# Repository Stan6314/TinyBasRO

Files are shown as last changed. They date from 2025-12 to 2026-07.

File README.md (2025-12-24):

Microcomputer TinyBasRO
======================

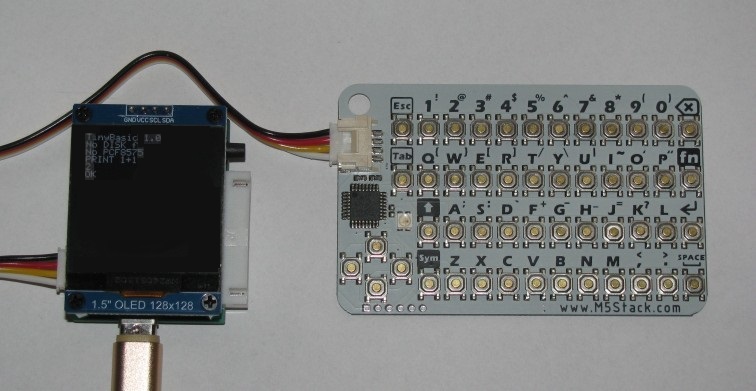
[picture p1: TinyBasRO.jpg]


The TinyBasRO microcomputer is a very simple device that even an electrical engineering beginner should be able to assemble and put into operation. It resembles simple 8-bit computers from the 1980s. After assembly, it can be programmed very easily using the Tiny BASIC language, which should be manageable even for those who have never programmed before. The basis is a small 32-bit RISC-V processor cooperating with serial I2C memory, where the user-created program is stored.

A microcomputer is suitable for the first introduction to computing technology when teaching hardware and software. It can be used not only for educational purposes, but can also be used as a control element for simple electronic devices.

Technical data for TinyBasRO
----------------------------

*   TinyBasHW_KiCad - HW documents (schematic and printed circuit board) in KiCad 9.0 format
*   src - Source files for TinyBasRO for CH32V003 created in ch32fun development environment
*   Bin - Compiled binary content in HEX format for direct loading into CH32V003 memory
*   Manuals - Manuals for HW, Tiny BASIC programming language and its examples and advice for beginners
*   EEPROM_examples - Contents of serial EEPROM memory in HEX format with examples of 8 ready-made Tiny BASIC sample programs for loading into microcomputer memory

Requirements for building and operating a TinyBasRO
---------------------------------------------------

*   Printed circuit board
*   Electrical components according to the list in the TinyBasRO_HW manual
*   WCHLinkE programmer for programming CH32V003
*   OLED display 128x128 with SH1107 driver
*   Keyboard CardKB from M5STACK
*   5V power supply

Using a microcomputer
---------------------

The assembled microcomputer only requires a 5 V power supply, OLED display 128x128 with SH1107 driver and CardKB keyboard. The board has several interfaces for connecting expansion modules via the I2C bus or controlled elements via the input/output connector. In addition, the TinyBasRO allows you to easily light up a string of up to 100 WS2812 LEDs compared to computer TinyBasRV.

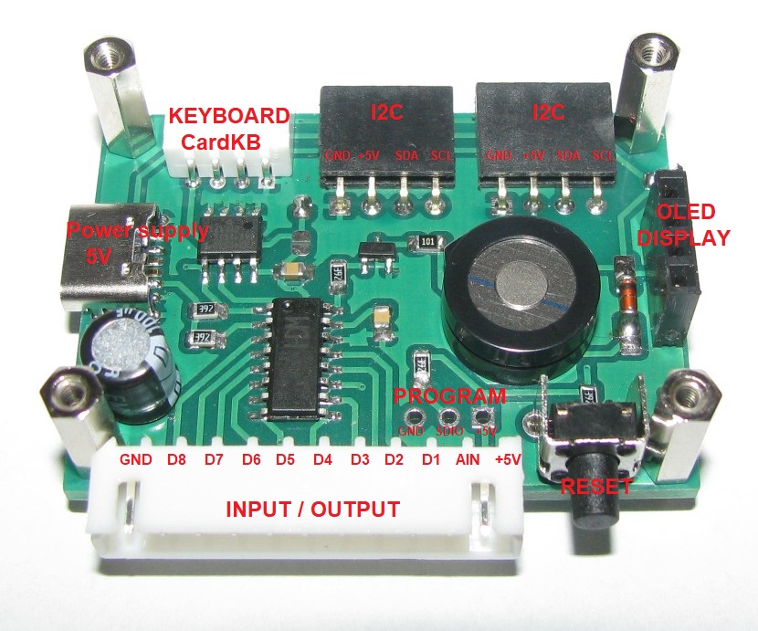
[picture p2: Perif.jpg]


After debugging the program, the TinyBasRO microcomputer can work independently without a monitor and keyboard and control, for example, some LED lighting effects.

* * *

Mikropočítač TinyBasRO
======================



Mikropočítač TinyBasRO je velmi jednoduché zařízení, které by měl dokázat sestavit a uvést do provozu i elektrotechnický začátečník. Podobá se jednoduchým 8bitovým počítačům z 80tých let. Po sestavení jej lze velmi jednoduše programovat pomocí jazyka Tiny BASIC, který by měl zvládnout i ten, kdo dříve neprogramoval. Základem je malý 32bitový RISC-V procesor spolupracující se sériovou I2C pamětí, kam se ukládá uživatelem tvořený program.

Mikropočítač je vhodný pro první seznámení s výpočetní technikou při výuce technického i programového vybavení. Může být použit nejen pro výukové účely, ale lze jej nasadit jako řídicí prvek pro jednoduché elektronické přístroje.

Technické podklady pro TinyBasRO
--------------------------------

*   TinyBasHW_KiCad - HW podklady (schéma a plošný spoj) ve formátu programu KiCad 9.0
*   src - Zdrojové soubory k TinyBasRO pro CH32V003 vytvořené v prostředí ch32fun
*   Bin - Přeložený binární obsah ve formátu HEX pro přímé nahrání do paměti CH32V003
*   Manuals - Manuály pro HW, programovací jazyk Tiny BASIC a jeho příklady a rady pro začátečníky
*   EEPROM_examples - Obsah sériové EEPROM paměti ve formátu HEX s příklady 8 hotových ukázkových programů Tiny BASIC pro nahrání do paměti mikropočítače

Požadavky pro stavbu a provoz TinyBasRO
---------------------------------------

*   Deska plošného spoje
*   Elektrotechnické součástky podle seznamu v manuálu TinyBasRO_HW
*   Programátor WCHLinkE pro naprogramování CH32V003
*   OLED displej 128x128 s řadičem SH1107
*   Klávesnice CardKB od M5STACK
*   Napájecí zdroj 5 V

Použití mikropočítače
---------------------

Sestavený mikropočítač vyžaduje pouze napájecí zdroj 5 V, OLED displej 128x128 s řadičem SH1107 a klávesnici CardKB. Na desce je několik rozhraní pro připojení rozšiřujících modulů přes I2C sběrnici nebo ovládaných členů přes konektor vstupů/výstupů. Navíc proti počítači TinyBasRV umožňuje snadno rozsvěcovat řetězec až se 100 LED WS2812. 



Po odladění programu, může mikropočítač TinyBasRO pracovat samostatně bez monitoru a klávesnice a řídit např. nějaké světelné LED efekty.

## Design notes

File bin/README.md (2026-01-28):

Memory content for the TinyBasRO microcomputer
==============================================

Here you will find two compiled versions of the program for the TinyBasRO microcomputer, which can be loaded directly into the microcontroller memory using the WCHLinkE programmer.

The file TinyBasRO.hex can be loaded into the CH32V003 memory with the standard display orientation (the display connector with the I2C bus is on top). If you would like to rotate the orientation of the microcomputer display (the display will be readable with the I2C bus connector on the bottom), use the file TinyBasRO_upsidedown.hex.

Notice!
=======

Be careful when reading and downloading HEX files from GitHub. When downloading a file, the end of the line is truncated to a single LF character (Linux-style). However, WCH-LinkUtility requires Windows-style line termination - CR+LF! When loading a file into its buffer, WCH-LinkUtility will only load one line of HEX file!

WCH-LinkUtility then acts as if it programmed the entire memory, but only 16 bytes are written. That is why the HEX files are now saved in .zip format.

* * *

Obsah paměti pro mikropočítač TinyBasRO
=======================================

Zde naleznete přeložené dvě verze programu pro mikropočítač TinyBasRO, které je možné nahrát přimo do paměti mikrořadiče pomocí programátoru WCHLinkE.

Soubor TinyBasRO.hex je možné nahrát do paměti CH32V003 při standardní orientaci displeje (konektor displeje s I2C sběrnicí je nahoře). Pokud byste chtěli orientaci displeje mikropočítače otočit (displej bude čitelný při konektoru I2C sběrnice dole) použijte soubor TinyBasRO_upsidedown.hex.

Upozornění!
===========

Dejte si pozor na čtení a stahování HEX souborů z GitHub. Při stažení souboru je konec řádku zkrácen na jeden znak LF (jako v Linuxu). WCH-LinkUtility ale vyžaduje ukončení řádku ve stylu Windows - CR+LF! Při načítání souboru do svého bufferu pak WCH-LinkUtility načte pouze jeden řádek HEX souboru!

WCH-LinkUtility pak fungují jakoby naprogramovaly celou paměť, ale zapíše se pouze 16 bajtů. Proto jsou HEX soubory nyní uloženy v .zip formátu.

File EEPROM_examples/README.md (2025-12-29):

Examples for TinyBasRO microcomputer
====================================

The file contains 8 examples in the Tiny BASIC language for the TinyBasRO computer. If you load them into the computer's serial EEPROM memory (you can choose "disk h" or "disk f") you will get 8 examples for working with the microcomputer.

The examples correspond to the examples described in the TinyBasExamples manual for the TinyBasRV microcomputer. Since the TinyBasRO computer has a smaller display (only 16 x 21 characters), the programs are modified to fit on the screen.

In the last example for controlling the traffic light, a total of 3 separate LEDs are used. Red on D2, yellow on D3 and green on D4 via 470 Ohm resistors. In addition, it is possible to connect a chain of 3 multi-colored WS2812 LEDs to D1. 

* * *

Příklady pro mikropočítač TinyBasRO
===================================

Soubor obsahuje 8 příkladů v jazyku Tiny BASIC pro počítač TinyBasRO. Pokud je nahrajete do sériové paměti EEPROM počítače (můžete si zvolit "disk h" nebo "disk f") získáte 8 ukázek pro práci s mikropočítačem.

Příklady odpovídají ukázkám popsaným v manuálu TinyBasExamples u mikropočítače TinyBasRV. Protože počítač TinyBasRO má menší displej (pouze 16 x 21 znaků), jsou programy modifikovány tak, aby se vešly na obrazovku.

U posledního příkladu pro ovládání semaforu jsou použity celkem 3 samostatné LED. Červená na D2, žlutá na D3 a zelená na D4 přes rezistory 470 Ohm. Navíc je možné připojit na D1 řetězec 3 vícebarevných LED typu WS2812.

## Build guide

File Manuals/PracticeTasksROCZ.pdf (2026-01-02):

## Cvičné úlohy pro jazyk Tiny BASIC (RO ver 1)

Příklad 1:

Zadání:
Vytvořte program pro výpočet plochy obdélníka. Po spuštění programu bude uživatel vyzván, ať zadá délky stran. Pak se vypíše velikost plochy. Vše počítejte s celočíselnými hodnotami.

Rada:
Použijte příkazy PRINT a INPUT. Plocha obdélníka se vypočítá jako součin délek jeho stran.

Příklad řešení:
0 REM Vypocet plochy obdelnika 1 PRINT “Zadej delku stran:\n“ 2 INPUT A; INPUT B
3 PRINT “Plocha je: “ , A*B

Poznámky k řešení:
Příklad by se dal napsat i na jeden řádek:
1 INPUT A; INPUT B; PRINT “Plocha je: “ , A*B

Rev. A

Příklad 2:

Zadání:
Vytvořte program pro výpočet plochy kruhu s přesností na 2 desetinná místa. Po spuštění programu bude uživatel vyzván, ať zadá poloměr kruhu a pak se vypíše velikost plochy.

Rada:
Použijte příkazy PRINT, LET, IF-THEN a INPUT. Tiny BASIC počítá pouze s celými čísly. Použijte pro výpočet plochy hodnotu π jako 314 a pak zobrazte výsledek postupně. Nejprve vypište celou hodnotu získanou dělením 100, znak pro desetinnou čárku a pak zbytek po dělení 100. Nezapomeňte, že zbytek po dělení je nutné zobrazit i s první nulou – např. 08.
Vzorec pro výpočet plochy je známý:

Příklad řešení:
0 REM Vypocet plochy kruhu
1 PRINT “Zadej polomer:\n“
2 INPUT R
3 LET S=R*R*314; LET C=S/100 4 PRINT “Plocha je: “ , C, “.“
5 LET Z=S-C*100
6 IF Z<10 THEN PRINT “0“
7 PRINT Z

Poznámky k řešení:
Tiny BASIC nemá operaci pro mocniny čísel. Proto je druhá mocnina zapsána jako R*R (řádek 3). A také nepracuje s desetinnými čísly. Násobením 314 místo 3,14 získáme výsledek 100krát větší. Abychom dostali celou část výsledku musíme S dělit 100 (řádek 3). Zbytek, který vypočítáme po odečtení celočíselné části násobené 100, pak musíme zobrazit i s případnou první nulou (řádek 6).

Příklad 3:

Zadání:
Vytvořte program, který pod sebe vypíše všechna lichá čísla do 20.

Rada:
Použijte příkazy PRINT, LET, GOTO a IF-THEN

Příklad řešení:
0 REM Licha cisla do 20
1 LET A=1
2 PRINT A, “\n“
3 LET A=A+2
4 IF A<20 THEN GOTO 2

Poznámky k řešení:
Jde o velmi jednoduchý počítaný cyklus. Začínáme od 1 (řádek 1) a postupně čísla vypisujeme na samostatné řádky (řádek 2) se zvětšováním po 2 (řádek 3). Vyhodnocovací podmínka (řádek 4) vrací program na výpis čísla, dokud není dosažena 20.

Příklad 4:

Zadání:
Vytvořte program, který vykresli na obrazovce pravoúhlý trojúhelník ze znaků * vysoký 10 řádků.

Rada:
Použijte příkazy PUTCH, LET, GOTO a IF-THEN. Znak pro nový řádek má hodnotu 10 a znak * má hodnotu 42.

Příklad řešení:
0 REM Trojuhelnik z *
1 PUTCH 10
2 LET A=1; REM Pocita radky
3 LET B=1; REM Hvezdy na radku 4 PUTCH 42; LET B=B+1
5 IF B<=A THEN GOTO 4
6 PUTCH 10; LET A=A+1
7 IF A<11 THEN GOTO 3

Poznámky k řešení:
Jsou zde použity 2 počítané cykly vnořené do sebe. V proměnné A se počítají řádky (řádky 2,6,7) a v proměnné B se počítají znaky vypisované na řádku (řádky 3,4,5).

Příklad 5:

Zadání:
Vytvořte program, který vykresli na obrazovce čtverec o délce strany 10 znaků.

Rada:
Použijte příkazy PUTCH, PRINT, LET, GOTO a IF-THEN. Abyste si ušetřili práci, použijte pro vykreslení vodorovné čáry podprogram s příkazy GOSUB a RETURN. Nezapomeňte program ve správném bodě ukončit příkazem END.
Znak pro vymazání displeje má hodnotu 12, nový řádek 10, levý horní roh 144, pravý horní roh 145, levý dolní roh 146, pravý dolní roh 147, svislá čára 156 a vodorovná čára 157.

Příklad řešení:
0 REM Ctverec
1 PUTCH 12
2 LET A=1; REM Pocita radky 3 PUTCH 144; GOSUB 10
4 PUTCH 145; PUTCH 10
5 PUTCH 156; PRINT “ “
6 PUTCH 156; PUTCH 10; LET A=A+1 7 IF A<8 THEN GOTO 5
8 PUTCH 146; GOSUB 10
9 PUTCH 147; PUTCH 10; END
10 REM Vodorovna cara
11 LET I=1
12 PUTCH 157; LET I=I+1
13 IF I<9 THEN GOTO 12
14 RETURN

Poznámky k řešení:
Řádky 3 a 4 vykreslí horní stranu čtverce, řádky 8 a 9 spodek čtverce. Využívá se podprogram na řádcích 10 až 14, který dělá vodorovnou čáru. Řádky 5, 6 a 7 vykreslí svislé čáry. Počet mezer v příkazu PRINT na řádku 5 musí být 8, aby se vyprázdnilo tělo čtverce.

Příklad 6:

Zadání:
Vytvořte program, který umožní posunovat znak X po obrazovce. Začíná se uprostřed obrazovky a stisknutí klávesy 2 znak X posune dolů, 4 vlevo, 6 vpravo a 8 nahoru.

Rada:
Použijte příkaz PUTCH s využitím jeho parametrů, CURSOR, INKEY, GOTO a IF-THEN.
Znak pro vymazání displeje má hodnotu 12, znak X je 88, prázdný znak je 32, 2 je 50, 4 je 52, 6 je 54 a 8 je 56.

Příklad řešení:
0 REM Posun X
1 PUTCH 12
2 CURSOR 157; PUTCH .88
3 INKEY K
4 IF K=50 THEN PUTCH v32; PUTCH .88 5 IF K=52 THEN PUTCH <32; PUTCH .88 6 IF K=54 THEN PUTCH >32; PUTCH .88 7 IF K=56 THEN PUTCH ^32; PUTCH .88
8 GOTO 3

Poznámky k řešení:
Program nejprve vyčistí obrazovku a umístí doprostřed displeje (pozice 400) znak X pomocí příkazu PUTCH. Symbol tečky zajistí, že kurzor zůstane na dané pozici. Když uživatel stiskne správnou klávesu, nejprve se vymaže stará pozice prázdným znakem a posune se kurzor na novou pozici (směr určuje symbol před hodnotou 32). Na nové pozici se pak vypíše X a ponechá kurzor.

Příklad 7:

Zadání:
Vytvořte program, který bude automaticky „hrát ping-pong“. Míček v podobě písmene o bude poletovat na řádku z levé strany na pravou stranu a naopak. Na kraji displeje se vždy odrazí a vrátí zpět.

Rada:
Použijte příkaz PUTCH s využitím parametrů, CURSOR, DELAY, GOTO a IF-THEN.
Znak pro vymazání displeje má hodnotu 12, znak o je 111, prázdný znak je 32.
Pozice uprostřed prostředního řádku má hodnotu 157, znak na levém okraji 147, vpravo 167.

Příklad řešení:
0 REM Ping-pong
1 PUTCH 12; LET C=157
2 CURSOR C; PUTCH .111
3 LET D=1
4 DELAY 100; PUTCH .32
5 LET C=C+D; CURSOR C; PUTCH .111 6 IF C=167 THEN LET D=-1
7 IF C=147 THEN LET D=1
8 GOTO 4

Poznámky k řešení:
Nejprve se program nastaví do výchozí pozice a směr pohybu míčku v proměnné D se určí na hodnotu 1 – tj. míček poletí vpravo(řádky 1 až 3). Ve smyčce, která začíná na řádku 4, se chvíli počká, smaže starý obraz míčku a pak se posune míček podle hodnoty v D na novou pozici. Řádky 6 a 7 hlídají dosažení kraje obrazovky a mění směr letu tam (D=1), nebo zpět (D=-1).

Příklad 8:

Zadání:
Napište program, který zahraje melodii podle not na obrázku. Na začátku uživatel zadá dobu trvání 1/8 noty v rozmezí 200 až 400 milisekund.

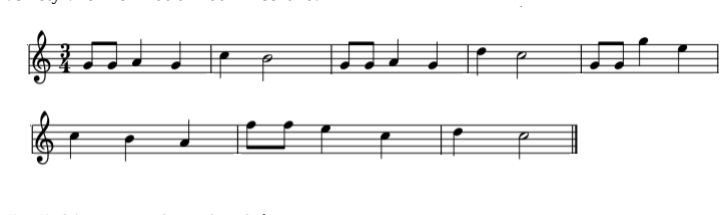
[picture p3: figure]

Přibližné frekvence základních tónů:
c‘: 262 | d‘: 294 | e‘: 330 | f‘: 349 | g‘: 392 | a‘: 440 | h‘: 494
c“: 523 | d“: 587 | e“: 659 | f“: 698 | g“: 784 | a“: 880 | h“: 989

Rada:
Použijte příkaz BEEP s využitím parametrů, INPUT, GOTO a IF-THEN. Pokud se v melodii objevují stejné pasáže, můžete použít podprogram GOSUB a RETURN, abyste nemuseli opisovat stejné části. Nezapomeňte program ukončit příkazem END.

Příklad řešení:
0 REM Melodie
1 PRINT “Zadej tempo:\n“
2 INPUT T
3 IF T<200 THEN GOTO 1
4 IF T>400 THEN GOTO 1
5 GOSUB 15
6 BEEP 523,2*T; BEEP 494,4*T; GOSUB 15 7 BEEP 587,2*T; BEEP 523,4*T; BEEP 392,T 8 BEEP 392,T; BEEP 784,2*T; BEEP 659,2*T
9 BEEP 523,2*T; BEEP 494,2*T; BEEP 440,2*T 10 BEEP 698,T; BEEP 698,T; BEEP 659,2*T
11 BEEP 523,2*T; BEEP 587,2*T; BEEP 523,4*T 12 END
15 BEEP 392,T; BEEP 392,T; BEEP 440,2*T
16 BEEP 392,2*T; RETURN

Poznámky k řešení:
Uživatel je nejprve vyzván k zadání tempa a je zkontrolováno povolené rozmezí hodnot (řádky 1 až 4). Protože se první čtyři tóny opakují ve třetím taktu, je použit podprogram na řádcích 15 a 16. Jednotlivé tóny jsou zadány frekvencí a dobou trvání. Čtvrťová nota je dvojnásobná a půlová čtyřnásobná proti zadané době osminové noty.

Příklad 9:

Zadání:
Napište program pro vytvoření velmi jednoduchého klavíru. Po stisknutí klávesy 1 až 9 zahraje po dobu 200 až 600 milisekund (čas se zadá po startu) tón c‘ až d“.
Přibližné frekvence základních tónů:
c‘: 262 | d‘: 294 | e‘: 330 | f‘: 349 | g‘: 392 | a‘: 440 | h‘: 494
c“: 523 | d“: 587

Rada:
Použijte příkaz BEEP s využitím parametrů, INPUT, INKEY, GOTO a IF-THEN. Zkuste využít toho, že klávesy 1 až 9 vrací v příkazu INKEY hodnoty 49 až 57. Pak můžete vypočítat potřebný skok v příkazu GOTO.

Příklad řešení:
0 REM Piano
1 PRINT “Zadej dobu tonu:\n“ 2 INPUT T
3 IF T<200 THEN GOTO 1
4 IF T>600 THEN GOTO 1
5 INKEY K
6 IF K<49 THEN GOTO 5
7 IF K>57 THEN GOTO 5
8 GOTO K-40
9 BEEP 262,T; GOTO 5
10 BEEP 294,T; GOTO 5
11 BEEP 330,T; GOTO 5
12 BEEP 349,T; GOTO 5
13 BEEP 392,T; GOTO 5
14 BEEP 440,T; GOTO 5
15 BEEP 494,T; GOTO 5
16 BEEP 523,T; GOTO 5
17 BEEP 587,T; GOTO 5

Poznámky k řešení:
Uživatel je nejprve vyzván k zadání doby tónu a je zkontrolováno povolené rozmezí hodnot (řádky 1 až 4). Ve smyčce, která začíná na řádku 5 se nejprve zkontroluje, zda klávesa patří mezi povolené a pak se vypočítá na řádku 8 skok na řádek s odpovídajícím tónem. Hodnota první povolené číslice 49 musí zamířit na řádek 9, proto se odečítá hodnota 40.

Příklad 10:

Zadání:
Vytvořte program, který bude představovat losovací zařízení pro čísla 1 až 49. Vždy po stisknutí libovolné klávesy zobrazí náhodné číslo z uvedeného rozsahu.

Rada:
Použijte příkazy TIME, INKEY, PRINT, GOTO a IF-THEN.
Po stisknutí klávesy vezměte aktuální čas. Jeho zbytek po dělení 49 bude dostatečně náhodné číslo. Nezapomeňte, že zbytek po dělení 49 je v rozsahu 0 až 48. Získanou hodnotu je potřeba zvýšit o 1.

Příklad řešení:
0 REM Nahodne cislo
1 INKEY K
2 IF K=0 THEN GOTO 1
3 TIME T; LET A=T/49
4 PRINT T-A*49+1, “\n“
5 GOTO 1

Poznámky k řešení:
Na řádcích 1 a 2 se čeká na stisknutí libovolné klávesy. V okamžiku, kdy uživatel stiskne klávesu se naplní proměnná T příkazem TIME. Hodnota získaná příkazem TIME se mění přibližně 32000krát za sekundu. Protože potřebujeme náhodná čísla do 49, vypočítáme zbytek po dělení 49. Výsledek zvětšený o 1 zobrazíme.

Příklad 11:

Zadání:
Vytvořte program ukazující čas uplynulý od spuštění počítače ve formě HH:MM:SS.

Rada:
Použijte příkazy TIME, PRINT, PUTCH, CURSOR, GOTO a IF-THEN.
Pokud hodnotu získanou příkazem TIME podělíte 31914, získáte čas od spuštění počítače v sekundách. Získaný čas pak stačí dělit 3600, abyste dostali počet uplynulých hodin. Ze zbytku pak dělením 60 získáte minuty. Nezapomeňte, že v zadání je zobrazení čísla na 2 místa. Nestačí vypsat jenom např. 5, je třeba zobrazit jako 05. Na to se může hodit podprogram s GOSUB a RETURN. Znak : má hodnotu 58, znak 0 má hodnotu 48.

Příklad řešení:
0 REM Hodiny
1 PUTCH 12
2 DELAY 300
3 TIME T; LET S=T/31914
4 LET A=S/3600; LET S=S-A*3600 5 CURSOR 0; GOSUB 10
6 LET A=S/60; LET S=S-A*60
7 PUTCH 58; GOSUB 10
8 LET A=S; PUTCH 58; GOSUB 10 9 GOTO 2
10 REM Vypis z A na 2 mista
11 IF A<10 THEN PUTCH 48
12 PRINT A; RETURN

Poznámky k řešení:
Čas získaný příkazem TIME podělíme hodnotou 31914, abychom získali celkový čas v sekundách. Hodiny do proměnné A získáme dělením 3600. Ve zbytku po celočíselném dělení zůstanou minuty a sekundy. Celočíselným dělením 60 dostaneme minuty a zbytek z výpočtu minut jsou sekundy. Vše musíme zobrazovat na 2 místa, takže doplňujeme případnou první nulu u jednociferných čísel při zobrazování hodnoty z A v podprogramu (řádek 11).

Příklad 12:

Zadání:
Vytvořte pomocí počítače „kuchyňskou minutku“. Po startu programu uživatel zadá čas od 1 do 99 minut. Po zadání začne na displeji odpočítávání po minutách a po dosažení 0 se ozve 10 sekund signál.

Rada:
Použijte příkaz TIME, BEEP, INPUT, PRINT, GOTO a IF-THEN. Po zadání požadovaného času si můžete vypočítat čas, při kterém časování skončí. Cílový čas získáte přičtením počtu minut násobených 60*31914 (sekundy v minutě krát počet tiků za sekundu = 1914840) k aktuálnímu času.

Příklad řešení:
0 REM Minutka
1 PRINT “Zadej cas [min]:\n“ 2 INPUT T
3 IF T<1 THEN GOTO 1
4 IF T>99 THEN GOTO 1
5 TIME C; LET C=C+T*60*31914 6 PUTCH 12
7 DELAY 300
8 TIME T; LET D=C-T
9 IF D<0 THEN BEEP 800,10000; END 10 CURSOR 0; PRINT D/1914840, “ “
11 GOTO 7

Poznámky k řešení:
Uživatel je nejprve vyzván k zadání doby a je zkontrolováno povolené rozmezí hodnot (řádky 1 až 4). Po správném zadání je do proměnné C uložen cílový čas, který vypočítáme jako aktuální čas s dobou zadanou uživatelem vynásobenou 31914 (počet tiků za sekundu) a 60 (počet sekund v minutě). Ve smyčce, která začíná na řádku 7, chvíli čekáme, protože není nutno zobrazovat hodnoty tak rychle, že by to uživatel stejně nepostřehl. Na řádku 8 zjistíme rozdíl mezi cílovým a aktuálním časem. Při záporném výsledku časování ukončíme. Jinak rozdíl zobrazíme. Konstanta 1914840 vznikne vynásobením 60*31914.

Příklad 13:

Zadání:
Naprogramujte hru „Lepší postřeh“ pro dva a více hráčů. Po stisknutí klávesy čeká 5 sekund, přičemž start časování je zahájen *. Pak zobrazí na displeji cílový znak. Klávesa, která byla zmáčknutá jako první po zobrazení cílového znaku, bude označena jako vítěz.

Rada:
Použijte příkazy INKEY, DELAY, PUTCH, PRINT, GOTO a IF-THEN. Při tvorbě programu nezapomeňte na to, že musíte zkontrolovat, zda hráč nezmáčknul klávesu před zobrazením cílového znaku.
Znak * má hodnotu 42, cílový znak má hodnotu 143.

Příklad řešení:
0 REM Lepsi postreh
1 PRINT “\nStart hry\n“
2 INKEY K
3 IF K=0 THEN GOTO 2
4 PUTCH 42; DELAY 5000; INKEY K 5 PUTCH 143; IF K>0 THEN GOTO 10
6 INKEY K
7 IF K=0 THEN GOTO 6
8 PRINT “\nVitez: “; PUTCH K; DELAY 2000 9 GOTO 1
10 PRINT “\nProhral: “; PUTCH K; DELAY 2000
11 GOTO 1

Poznámky k řešení:
Na řádcích 1 až 3 počkáme na start hry. Pak zobrazíme *, čekáme 5 sekund a sejmeme, zda někdo nestiskl klávesu předčasně (řádek 4). Na řádku 5 zobrazíme cílový znak a zkontrolujeme předčasné stisknutí klávesy. Je-li vše v pořádku, na řádcích 6 a 7 čekáme na stisknutí klávesy a na řádku 8 vyhlásíme vítěze.

Příklad 14:

Zadání:
Vytvořte program pro akustický generátor. Uživatel zadá frekvenci požadovaného tónu v rozsahu 100 až 4000 Hz a dokud nebude program ukončen, počítač píská zadaným tónem.

Rada:
Použijte příkazy BEEP, INPUT, PRINT, GOTO a IF-THEN.
Aby bylo možné program zastavit zadáním příkazu END, použijte v časovém parametru u příkazu BEEP nějakou přijatelnou hodnotu v rozsahu jednotek sekund.

Příklad řešení:
0 REM Zvukovy generator
1 PRINT “Zadej frekv. 100-4000\n“ 2 INPUT F
3 IF F<100 THEN GOTO 1
4 IF F>4000 THEN GOTO 1
5 BEEP F,5000
6 GOTO 5

Poznámky k řešení:
Uživatele nejprve vyzveme k zadání frekvence a je zkontrolováno povolené rozmezí hodnot (řádky 1 až 4). Pak je ve smyčce na řádcích 5 a 6 trvale pouštěn tón o zadané frekvenci.

Příklad 15:

Zadání:
Napište program, ve kterém uživatel zadá nějaké jméno ukončené klávesou Enter. Počítač pak vypíše, že jméno je jeho přítel. Maximální délka jména může být 30 znaků.

Rada:
Použijte příkazy INKEY, PRINT, PUTCH, GOTO a IF-THEN. Zadávané jméno je výhodné ukládat do proměnných v poli @. Počítejte si přitom počet uložených písmen.

Příklad řešení:
0 REM Pritel pocitace
1 LET I=0; PRINT “\nZadej jmeno:\n“ 2 INKEY K
3 IF K=0 THEN GOTO 2
4 IF K=10 THEN GOTO 10
5 PUTCH K; LET @I=K; LET I=I+1 6 IF I=30 THEN GOTO 10
7 GOTO 2
10 LET J=0; PUTCH 10
11 PUTCH @J; LET J=J+1
12 IF J<I THEN GOTO 11
13 PRINT “ je muj pritel\n“

Poznámky k řešení:
Řádky 2 a 3 čekají na zadání znaku. Řádek 4 kontroluje, zda nebylo zadávání ukončeno klávesou Enter. Na řádku 5 je znak uložen do pole. Řádek 6 kontroluje maximální povolenou délku jména. Na řádcích 10 až 12 je jméno opět vypsáno.

Příklad 16:

Zadání:
Vytvořte program pro ovládání LED připojené k výstupu D1 pomocí klávesnice. První zmáčknutí libovolné klávesy LED rozsvítí, druhé zhasne, další opět rozsvítí atd.

Doplňkový HW:
Na výstup D1 připojte LED s rezistorem podle následujícího obrázku. Červená barva LED bude vhodná pro následující úlohu.

Rada:

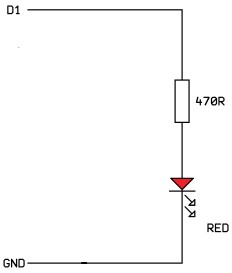
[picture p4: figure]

Použijte příkazy INKEY, DOUT, GOTO a IF-THEN. Příkaz DOUT 1,1 pak LED rozsvítí a DOUT 0,1 ji zhasne.
Protože program nemusí být rychlý, můžete do cyklu čekání na stisk klávesy vložit drobné zpoždění příkazem DELAY.

Příklad řešení:
0 REM Ovladani LED
1 LET L=0
2 DELAY 100; INKEY K
3 IF K=0 THEN GOTO 2
4 IF L=0 THEN GOTO 6
5 LET L=0; DOUT 0,1; GOTO 2
6 LET L=1; DOUT 1,1; GOTO 2

Poznámky k řešení:
Proměnná L ukládá aktuální hodnotu výstupu, abychom věděli, jak příště výstup změnit. Na řádcích 2 a 3 se čeká na stisk klávesy. Řádek 4 rozhodne podle stavu L, zda se LED rozsvítí nebo zhasne.

Příklad 17:

Zadání:
Vytvořte program, který z TinyBasRO udělá ovládání výstražných světel na železničním přejezdu i se zvukovou signalizací.

Doplňkový HW:
Na výstupy D1 a D2 připojte dvě LED (nejlépe červené) s rezistory podle následujícího obrázku.

Rada:

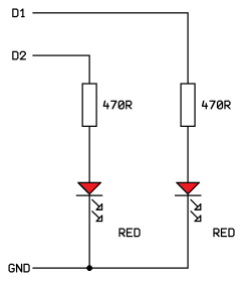
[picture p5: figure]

Použijte příkazy BEEP, DELAY, DOUT a GOTO. Zvukovou signalizaci si vyzkoušejte a upravte podle vlastních představ.

Příklad řešení:
0 REM Zeleznice - vystraha
1 DOUT 1,1; DOUT 0,2
2 BEEP 2000,100; BEEP 800,200; DELAY 200 3 DOUT 0,1; DOUT 1,2
4 BEEP 2000,100; BEEP 800,200; DELAY 200
5 GOTO 1

Poznámky k řešení:
Řádky 1 a 3 rozsvítí vždy pouze jednu z obou LED. Na řádcích 2 a 4 je generováno stejné zvukové znamení. Uvedený příklad jen velmi vzdáleně připomíná cinkání zvonce. Můžete je ladit a upravovat podle svého ucha...

Příklad 18:

Zadání:
Vytvořte program pro měření vstupního napětí na vstupu AIN v mV. Na vstup přiveďte napětí z běžce potenciometru, které bude zobrazováno s periodou ½ sekundy.

Doplňkový HW:
Na výstup AIN připojte lineární potenciometr s hodnotou odporu v rozmezí 1 až 100 kΩ podle následujícího obrázku.

Rada:

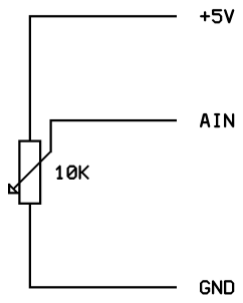
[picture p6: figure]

Použijte příkazy AINP, DELAY, CURSOR, PRINT a GOTO. Hodnota získaná z A/D převodníku je v rozsahu 0 až 1023. To představuje napětí 0 až 5V – tedy 0 až 5000 mV. Abychom přepočítali rozsah A/D převodníku na mV, musíme hodnotu nejprve vynásobit 5000 a pak dělit 1023.

Příklad řešení:
0 REM Analog vstup mV
1 PUTCH 12
2 CURSOR 154; AINP A
3 PRINT A*5000/1023, “ mV “ 4 DELAY 500
5 GOTO 2

Poznámky k řešení:
Na řádku 2 se nejprve nastaví kurzor přibližně do středu obrazovky a pak se změří napětí na vstupu AIN. Přepočet se provede při výpisu hodnoty v příkaze PRINT podle návodu v odstavci Rada. Po výpisu jednotek jsou ještě doplněny 3 mezery, aby se vymazal případný delší zápis z minulého měření.

Příklad 19:

Zadání:
Upravte počítač TinyBasRO tak, aby pracoval jako jednoduchý voltmetr s rozsahem do 50 V. Napětí bude zobrazováno s periodou ½ sekundy a s rozlišením na 2 desetinná místa.

Doplňkový HW:
Na výstup AIN připojte vstupní odporový dělič s rezistory s poměrem odporů 9:1. Ideální by bylo např. 900 kΩ a 100 kΩ. Hodnota 900 kΩ je ale mimo běžnou řadu dostupných rezistorů. Můžete použít nejbližší hodnotu 910 kΩ z řady E24. V nouzi lze použít i 1 MΩ a upravit konstantu v programu.

Rada:

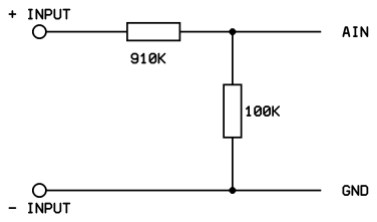
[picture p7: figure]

Použijte příkazy AINP, DELAY, CURSOR, PUTCH, PRINT, GOTO a IF-THEN. Hodnota získaná AINP z A/D převodníku je v rozsahu 0 až 1023. To představuje napětí 0 až 50V (musíme zobrazit 0.00 až 50.00 V). Abychom přepočítali rozsah A/D převodníku na V, je třeba hodnotu nejprve vynásobit 5000 a pak dělit 1023. Výsledné číslo zobrazíme s desetinou tečkou mezi číslicemi. Násobící konstanta 5000 je ideální případ, kdy se předpokládá přesné referenční napětí v mikropočítači a přesné hodnoty odporu obou rezistorů v děliči. V praxi se to bude lišit. Proto je potřeba u konkrétního kusu počítače tuto hodnotu upravit tak, aby zobrazené napětí se co nejvíce blížilo napětí změřenému referenčním voltmetrem.

Příklad řešení:
0 REM Voltmetr 50V
1 PUTCH 12; LET K=5320
2 CURSOR 154; AINP A
3 LET V=A*K/1023; LET C=V/100 4 LET Z=V-C*100
5 PRINT C, “.“
6 IF Z<10 THEN PRINT “0“
7 PRINT Z
8 DELAY 500
9 GOTO 2

Poznámky k řešení:
Na řádku 1 je nastavena přepočtová konstanta, kterou si musíte upravit podle konkrétního kusu počítače a vstupního odporového děliče. Další postup již kopíruje instrukce uvedené v odstavci Rada. Nejprve je vypsána celá část z proměnné C a pak zbytek po dělení 100 ze Z. Pokud je zbytek menší než 10, je nutné doplnit úvodní nulu (řádek 6).

Příklad 20:

Zadání:
Pomocí expanderu PCF8575 připojeného k TinyBasRO vyrobte běžící světlo na řadě LED připojených k výstupům expanderu.

Doplňkový HW:
Na výstupy modulu s expanderem PSC8575 připojte více LED podle obrázku. Záleží na množství LED, které máte k dispozici, maximálně je možné připojit 16 LED.

Rada:

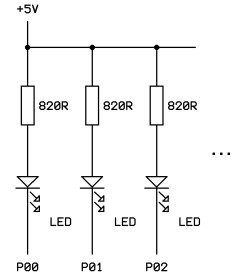
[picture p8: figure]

Použijte příkazy I2CW, DELAY, LET, GOTO a IF-THEN. Pokud chcete rozsvítit první LED, musíte do expanderu poslat binární číslo b1111111111111110 nebo dekadicky -2. Druhá LED vyžaduje poslat binární číslo b1111111111111101 nebo dekadicky -3. Další by bylo binární číslo b1111111111111011 nebo dekadicky -5. Rozsvícení LED se posune na další pozici vždy vynásobením 2 a přičtením 1.
Po rozsvícení poslední LED se musí světlo vrátit na začátek.

Příklad řešení (pro 8 LED): 0 REM Bezicich 8 LED
1 LET A=-2
2 I2CW A; DELAY 200
3 LET A=A*2+1
4 IF A < -300 THEN LET A=-2
5 GOTO 2

Poznámky k řešení:
Program postupuje podle instrukcí uvedených v odstavci Rada. Po daný příklad bylo použito pouze 8 LED, při dosažení hodnoty menší než -300 se hodnota v A vrátí na začátek. Poslání čísla -257 do expanderu (poslední odeslané v cyklu) na chvíli vypne všech 8 LED. Pokud byste to nechtěli, zmenšete podmínku např. na A<-150.

Příklad 21:

Zadání:
Napište program, který pomocí expanderu PCF8575 připojeného k TinyBasRO rozsvítí po stisknutí klávesy 0 až 9 určený počet LED (vámi zvolený obraz).

Doplňkový HW:
Na výstupy modulu s expanderem PSC8575 připojte více LED podle obrázku. Záleží na množství LED, které máte k dispozici, maximálně je možné připojit 16 LED.

Rada:

Použijte příkazy I2CW, DELAY, INKEY, GOTO a IF-THEN. Pro jednotlivé číslice si můžete určit libovolný vzorek rozsvícených LED. Např. po stisknutí klávesy 1 se rozsvítí každá lichá LED příkazem I2CW b1010101010101010, klávesa 2 rozsvítí dolní polovinu LED příkazem I2CW b1111111100000000 atd.
Klávesy 0 až 9 vrací v příkazu INKEY hodnoty 48 až 57.

Příklad řešení:
0 REM Vzory z LED
1 DELAY 100; INKEY K
2 IF K<48 THEN GOTO 1
3 IF K>57 THEN GOTO 1
4 GOTO K-43
5 I2CW b1100110011001100; GOTO 1 6 I2CW b1010101010101010; GOTO 1 7 I2CW b1111111100000000; GOTO 1 8 I2CW b1111100001100101; GOTO 1 9 I2CW b0000000011001100; GOTO 1 10 I2CW b1100110000000000; GOTO 1 11 I2CW b1110111011101110; GOTO 1 12 I2CW b1101110111011101; GOTO 1 13 I2CW b1011101110111011; GOTO 1
14 I2CW b0111011101110111; GOTO 1

Poznámky k řešení:
Nejprve se na řádcích 1, 2 a 3 zajistí přijetí pouze povolené číselné klávesy. Řádek 4 pak zajistí odskok na patřičný vzorek rozsvícených LED s návratem na začátek.

Příklad 22:

Zadání:
Naprogramujte měřič postřehu uživatele. Po stisknutí klávesy čeká program náhodný počet sekund (1 až 10), přičemž start časování je zahájen *. Pak zobrazí na displeji cílový znak. Uživatel musí co nejrychleji zmáčknout libovolnou klávesu. Na displeji se zobrazí reakční čas v milisekundách.

Rada:
Použijte příkazy INKEY, TIME, DELAY, PUTCH, PRINT, GOTO a IF-THEN. Při tvorbě programu nezapomeňte na to, že musíte zkontrolovat, zda hráč nezmáčknul klávesu před zobrazením cílového znaku. Pro měření času v milisekundách budeme počítat, že TIME vrací každou milisekundu hodnotu o 32 větší.
Znak * má hodnotu 42, cílový znak má hodnotu 143.

Příklad řešení:
0 REM Meric postrehu
1 PRINT “\nStart\n“
2 INKEY K
3 IF K=0 THEN GOTO 2
4 TIME T; LET C=T/10
5 LET D=T-C*10+1; LET D=D*1000 6 PUTCH 42; DELAY D
7 INKEY K; PUTCH 143; TIME S 8 IF K>0 THEN GOTO 14
9 INKEY K
10 IF K=0 THEN GOTO 9
11 TIME E; LET R=E-S
12 PRINT “\nReakce: “, R/32 13 PRINT “ milisec“; GOTO 1 14 PRINT “\nPredcasne!“
15 GOTO 1

Poznámky k řešení:
Řádky 2 a 3 čekají na start měření. Pak se získá pomocí příkazu TIME a zbytku po dělení 10 náhodný čas, který se uloží do proměnné D v milisekundách (řádky 4 a 5). Na řádku 6 se zobrazí * a provede čekání. Řádek 7 sejme stav kláves, zobrazí cílový znak a uloží začáteční čas pro měření postřehu. Na řádku 8 se zkontroluje případné předčasné stisknutí klávesy. Řádky 9 a 10 čekají na reakci uživatele. Čas, kdy zareagoval se uloží do E a pak na řádcích 11, 12 a 13 se výsledek vypíše.

Příklad 23:

Zadání:
Máte-li možnost připojit k TinyBasRO jehličkovou tiskárnu s paralelním portem přes expander PCF8575, vytvořte z ní jednoduchý psací stroj.

Doplňkový HW:
Na výstupy modulu s expanderem PCF8575 připojte konektor Cannon 25 samici podle obrázku.

Rada:

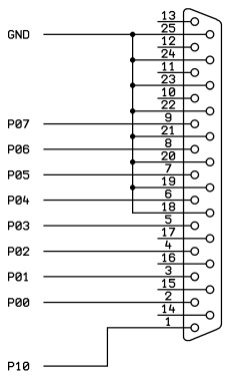
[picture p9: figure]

Použijte příkazy I2CW, DELAY, INKEY, GOTO a BEEP. Příkaz BEEP se použije pro zvukovou signalizaci stisknutí klávesy krátkým pípnutím. Není nutné jej použít.
Na vývodu 1 paralelního portu je signál STROBE ovládaný výstupem P10, který potvrdí a zapíše data do tiskárny. Aktivní hodnota je logická 0. Po zapsání dat, je nutné tento signál vrátit do klidové hodnoty 1. To lze nejsnáze udělat zapsáním hodnoty o 256 větší než zapisovaná data.

Příklad řešení:
0 REM Psaci stroj
1 INKEY K
2 IF K=0 THEN GOTO 1
3 I2CW K; PUTCH K
4 DELAY 10
5 I2CW K+256; BEEP 1000,50
6 GOTO 1

Poznámky k řešení:
Řádky 1 a 2 čekají na stisk klávesy. Řádek 3 pošle znak do tiskárny a okopíruje ho na displej. Na řádku 4 se chvíli počká (pro případ pomalé reakce tiskárny). Na řádku 5 se musí nastavit signál STROBE pro tiskárnu zpět na logickou 1 (hodnota znaku se zvýší o 9tý bit nastavený na 1) a krátce se pípne.

Příklad 24:

Zadání:
Vytvořte z TinyBasRO jednoduchou celočíselnou kalkulačku. Uživatel zadá první číslo, pak operand (+ - * /) a na závěr druhé číslo. Na displeji se objeví vypočítaný výsledek ve tvaru např. 256*2=512.

Rada:
Použijte příkazy INPUT, INKEY, PRINT, PUTCH, GOTO a IF-THEN. Znaky operandů mají následující hodnoty:
+ | 43 | - | 45 | * | 42 | / | 47
Nezapomeňte, že nulou nedělíme!

Příklad řešení:
0 REM Kalkulacka
1 PUTCH 10; INPUT A
2 INKEY K
3 IF K=42 THEN GOTO 8
4 IF K=43 THEN GOTO 8
5 IF K=45 THEN GOTO 8
6 IF K=47 THEN GOTO 8
7 GOTO 2
8 PUTCH K; PUTCH 10; INPUT B;
9 PRINT A; PUTCH K; PRINT B
10 IF K=43 THEN PRINT “=“,A+B; GOTO 1
11 IF K=45 THEN PRINT “=“,A-B; GOTO 1
12 IF K=42 THEN PRINT “=“,A*B; GOTO 1
13 IF B=0 THEN PRINT “ Nulou nelze!“; GOTO 1
14 PRINT “=“,A/B; GOTO 1

Poznámky k řešení:
První hodnota se uloží do proměnné A na řádku 1. Pak se na řádcích 3 až 7 čeká na typ operace. Na řádku 8 vytiskneme znak operace a počkáme na druhou hodnotu. Řádky 10 až 14 provedou výpočet podle stavu K, přičemž se na řádku 13 zkontroluje, zda se nebude dělit 0.

Příklad 25:

Zadání:
Napište program pro hádání tajného čísla 0 až 99. Po startu si počítač vybere náhodné číslo a hráč má toto číslo uhodnout na co nejmenší počet pokusů. Po každém pokusu počítač uvede, zda je tajné číslo větší nebo menší než to, které zadal hráč.

Rada:
Použijte příkazy INPUT, PRINT, TIME, LET, GOTO a IF-THEN. Nejprve si vygenerujte pomocí příkazu TIME a zbytku po dělení 100 náhodné číslo.

Příklad řešení:
0 REM Hadani cisla
1 TIME T; LET C=T/100; LET X=T-C*100 2 LET P=0; PRINT “\nHadej cislo\n“
3 INPUT A; LET P=P+1
4 IF A=X THEN GOTO 8
5 IF A>X THEN GOTO 7
6 PRINT P,“. Hadej vic\n“; GOTO 3
7 PRINT P,“. Hadej mene\n“; GOTO 3
8 PRINT “Uhodl jsi na “, P, “ pokusu\n“

Poznámky k řešení:
Na řádku 1 se pomocí příkazu TIME a zbytku po celočíselném dělení 100 uloží do proměnné X náhodně generované hádané číslo. Na řádcích 2 a 3 je uživatel vyzván k pokusu uhodnout číslo a v proměnné P se počítají provedené pokusy. Řádky 4 a 5 kontrolují úspěšnost pokusu a na zbývajících řádcích se vypisuje pokyn, kam směřovat další odhad nebo ukončení programu s výsledkem.

Příklad 26:

Zadání:
Vytvořte z TinyBasRO jednoduchý kódový zámek. Zadá-li uživatel na klávesnici správnou posloupnost 4 nebo 5 číslic, na výstupu D1 se na 3 sekundy objeví logická 1 a zazní zvukový signál.

Rada:
Použijte příkazy INKEY, LET, DOUT, BEEP, GOTO a IF-THEN. Počet kódových číslic si můžete zvolit sami. Tajnou číselnou kombinaci si uložte do pole @ a každá správně uhodnutá číslice posune ukazatel v poli na vyšší hodnotu. Při chybě se ukazatel vrátí na počátek pole.
Klávesy 0 až 9 vrací v příkazu INKEY hodnoty 48 až 57.

Příklad řešení:
0 REM Kodovy zamek
1 LET @0=49,57,50,48,51
2 LET P=0
3 INKEY K
4 IF K=0 THEN GOTO 3
5 IF K<>@P THEN GOTO 2
6 LET P=P+1;
7 IF P<5 THEN GOTO 3
8 DOUT 1,1; BEEP 800,3000; DOUT 0,1
9 GOTO 2

Poznámky k řešení:
Na řádku 1 je do pole @ uložen kód zámku. Proměnná P ukazuje, kam se uživatel při zadávání kódu dostal. Řádek 5 rozhoduje, zda se postoupí na další pozici, nebo se vrátí opět na první číslici kódu. Na řádku 7 se při správném postupu a dosažení ukazatele P na hodnotu 5 umožní přejít na řádek 8, kde se kódový zámek na 3 sekundy otevře.

Příklad 27:

Zadání:
Napište program, který bude nahrazovat hrací kostku. Program bude na displeji zobrazovat body tak, jak se nacházejí na kostce.

Rada:
Pokud se podíváte na vzory nacházející se na stěnách kostky, zjistíte, že kromě střední tečky se tečky vždy vyskytují po dvojicích. Např. 3 je kombinace A+B, 5 je A+B+C.

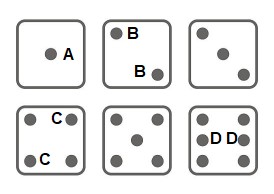
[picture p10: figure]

Vzory si můžete zakódovat do pole např. pomocí binárních čísel a pak je podle náhodně taženého čísla zobrazit. Doporučené pozice kurzoru jsou pro A: 157, pro B: 69 a 245, pro C: 77 a 237 a pro D: 153 a 161. Použijte příkazy LET, TIME, INKEY, GOTO, CURSOR, PUTCH a IF-THEN.

Příklad řešení:
0 REM Hraci kostka
1 PUTCH 12; LET @0=1,2,3,6,7,14
2 INKEY K
3 IF K=0 THEN GOTO 2
4 TIME D; LET C=D/6; LET D=D-C*6
5 CURSOR 157; PUTCH .32; IF @D&1 THEN PUTCH 143 6 CURSOR 69; PUTCH 32; CURSOR 245
7 PUTCH .32; IF@D&2 THEN PUTCH 143
8 CURSOR 69; IF@D&2 THEN PUTCH 143
9 CURSOR 77; PUTCH 32; CURSOR 237 10 PUTCH .32; IF@D&4 THEN PUTCH 143 11 CURSOR 77; IF@D&4 THEN PUTCH 143 12 CURSOR 153; PUTCH 32; CURSOR 161 13 PUTCH .32; IF@D&8 THEN PUTCH 143 14 CURSOR 153; IF@D&8 THEN PUTCH 143
15 GOTO 2

Poznámky k řešení:
V poli @ je zakódováno zobrazení čísel 0 až 5 pomocí binárního kódu. Pokud se podíváte, jak se uvedená čísla zapisují ve dvojkové soustavě, zjistíte, že nejnižší bit představuje tečku A, vyšší bit obě tečky B, další C a čtvrtý bit jsou tečky D. Řádky 2 a 3 čekají na stisknutí klávesy. Na řádku 4 je vygenerováno do proměnné D náhodné číslo 0 až 5. Pak jsou procházeny všechny pozice jednotlivých teček. Např. u řádku 5 je kurzor nastaven na tečku A a ta je nejprve smazána. Pokud prvek pole s indexem D má nastavený nejnižší bit, je tečka na pozici vykreslena.

Příklad 28:

Zadání:
Doplňte TinyBasRO tak, aby fungoval jako řídicí panel nouzového osvětlení. Pomocí fotorezistoru se bude snímat stav okolního osvětlení a měřená hodnota se zobrazí na displeji. Uživatel zadá na začátku hodnoty při kterých se zapne a naopak vypne LED připojená na D1.

Doplňkový HW:
Na vstup AIN a výstup D1 připojte dělič s fotorezistorem a LED s rezistorem podle obrázku.

Rada:

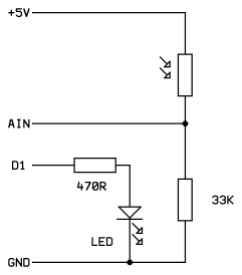
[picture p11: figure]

Použijte příkazy INPUT, PRINT, DOUT, AINP, GOTO a IF-THEN. Měřená hodnota osvětlení bude pouze číslo z A/D převodníku. Uživatel si může nastavit 2 hranice, při kterých se světlo zapne nebo vypne, a tak si nastavit hysterezi obvodu. Ošetřete, aby zadané hranice nebyly mimo rozumný rozsah.
Jako fotorezistor můžete použít typ 5537 nebo podobný.

Příklad řešení:
0 REM Nouzove osvetleni
1 PRINT “\f0\n\n“
2 INPUT H
3 IF H<10 THEN GOTO 2
4 IF H>1000 THEN GOTO 2
5 INPUT L
6 IF L>=H THEN GOTO 5
7 AINP A; CURSOR 0; PRINT A,“ “ 8 IF A<L THEN DOUT 1,1
9 IF A>H THEN DOUT 0,1
10 DELAY 200; GOTO 7

Poznámky k řešení:
Na řádcích 2 až 6 je vyžadováno zadání hranic, při kterých LED zhasne nebo se rozsvítí (i s kontrolou povolených hodnot). Vlastní smyčka je na řádcích 7 až 10. Po změření je hodnota vypsána. Příkaz PRINT je doplněn o vymazání delšího čísla, které by mohlo zůstat na displeji z předchozího měření. Pak je na řádcích 8 a 9 LED rozsvícena či zhasnuta.

Příklad 29:

Zadání:
Vytvořte z TinyBasRO jednoduchý kryptografický přístroj, který bude kódovat a dekódovat znaky abecedy a až z na jiný znak podle vámi zvolené šifrovací tabulky. Program po stisku příslušného znaku musí ukázat jak zakódovaný, tak odpovídající dekódovaný znak.

Rada:
V poli @ si pomocí příkazu LET vytvořte šifrovací tabulku. Po kontrole, zda zmáčknutá klávesa patří mezi povolené znaky, vyberte znak z tabulky, zobrazte ho a pak tabulku prohledejte pro dekódování. Doporučené příkazy PRINT, INKEY, CURSOR, GOTO a IF-THEN.

Příklad řešení:
0 REM Sifrovaci stroj
1 LET @0=6,18,11,5,20,14,22,2,9,15 2 LET @10=17,8,1,10,19,0,13,4,23,24 3 LET @20=25,7,16,12,21,3
4 PRINT “\fZnak Kod Dekod“
5 INKEY K
6 IF K<97 THEN GOTO 5
7 IF K>122 THEN GOTO 5
8 LET Z=K-97; CURSOR 22; PUTCH K 9 CURSOR 28; PUTCH 65+@Z; LET I=0 10 IF @I=Z THEN GOTO 12
11 LET I=I+1; IF I<26 THEN GOTO 10
12 CURSOR 34; PUTCH 65+I; GOTO 5

Poznámky k řešení:
Základem programu je kódovací tabulka v poli @. Všech 26 znaků anglické abecedy má svůj náhodně zvolený kód. Znak „a“ má kód na pozici 0, „b“ na 1, atd. Čísla kódů mohou být od 0 do 25.
Uvažujeme zadávání malých písmen abecedy, jejich hodnoty budou 97 až 122. Na to čekají řádky 5 až 7. Ukazatel do kódovací tabulky v proměnné Z získáme odečtením hodnoty 97 od znaku. Vypíšeme zadaný znak, jeho zakódovanou podobu ve formě velkého písmene, které začínají na hodnotách 65 (řádky 8 a 9). Na řádcích 10 a 11 tabulku prohledáme pro opačnou funkci – dekódování. Řádek 12 dekódovaný znak vypíše.

Příklad 30:

Zadání:
Napište program pro jednoduché stopky. První zmáčknutí libovolné klávesy měřený čas odstartuje, další pak hodnotu zastaví. Zobrazovat se bude na minuty:sekundy,desetiny sekund.

Rada:
Použijte příkazy INKEY, LET, PUTCH, PRINT, GOTO a IF-THEN. Po spuštění programu nejprve počkejte na zmáčknutí klávesy. Uložte si aktuální čas startu. Zobrazujte rozdíl mezi aktuálním časem a startem dělení 3191 (počet tiků za desetinu sekundy). Nejprve hodnotu dělenou 600 – to budou minuty a pak sekundy a desetiny sekund. Nezapomeňte, zobrazit sekundy vždy na 2 desetinná místa. Znak 0 má hodnotu 48.
Další stisk počítání zastaví, aby se dal přečíst dosažený čas. Třetí stisk klávesy pak opět vrátí stopky na nulový čas a připraví ke startu.

Příklad řešení:
0 REM Stopky
1 PUTCH 12; PRINT “0:00,0“ 2 INKEY K
3 IF K=0 THEN GOTO 2
4 TIME B
5 DELAY 80
6 TIME T; LET T=T-B; LET S=T/3191 7 LET A=S/600; LET S=S-A*600
8 CURSOR 0; PRINT A,“:“
9 LET A=S/10; LET S=S-A*10
10 IF A<10 THEN PUTCH 48
11 PRINT A,“,“,S
12 INKEY K; IF K=0 THEN GOTO 5 13 INKEY K
14 IF K=0 THEN GOTO 13
15 GOTO 1

Poznámky k řešení:
Řešení postupuje podle pokynů v odstavci Rada. Nejprve se čeká na start stopek (řádky 2 a 3). Do proměnné B se uloží čas startu. Lidské oko není příliš rychlé, tak má smyčka zobrazování zanesené zpoždění na řádku 5. Uplynulý čas v desetinách sekundy se vypočítá do proměnné S na řádku 6. Řádky 7 až 11 čas zobrazí na displej. Řádek 12 kontroluje zastavení stopek. Řádky 13 a 14 čekají na nový restart programu.

Příklad 31:

Zadání:
Napište program představující jednoduchou hru „Dostihy“. Hráč může s počátečním kapitálem vsadit částku na jednoho ze tří koní. Koně budou do cíle dobíhat s náhodným pořadím.

Rada:
Použijte např. příkazy INPUT, PRINT, PUTCH, LET, CURSOR, DELAY, TIME, GOTO a IF-THEN. Pozici, na které se nachází kůň, si uložte do pole @. Bude se pak lépe odkazovat na koně, který se bude náhodně posouvat pomocí příkazu TIME.
Při sázce na vítězného koně připočítejte hráči trojnásobek vsazené částky.

Příklad řešení:
0 REM Dostihy
1 LET M=1000
2 PRINT “\fVsadis? 1-“,M,“\n“
3 INPUT B; IF B<1 THEN GOTO 2 4 IF B>M THEN GOTO 2
5 PRINT “\nKun 1-3?\n“; INPUT K 6 LET @1=1; LET @2=1; LET @3=1 7 PRINT “\fZavod“; PUTCH p49,42
8 PUTCH p50,84; PUTCH p51,126
9 TIME T; LET V=T/3; LET V=T-V*3+1
10 DELAY 100; LET @V=@V+1; PUTCH p143,V*42+@V 11 IF @V<20 THEN GOTO 9
12 CURSOR 174; PRINT “Vyhral “,V; DELAY 1000
13 IF V=K THEN LET M=M+B*3; GOTO 2
14 LET M=M-B; IF M>0 THEN GOTO 2
15 PRINT “\nDosly prachy\n“

Poznámky k řešení:
Počáteční kapitál je nastaven na řádku 1. Pak je uživatel vyzván, aby určil hodnotu sázky s kontrolou, zda se nepokouší švindlovat (řádky 2 až 4). Řádek 5 vyzve k sázce na jednoho ze tří koňů. Zde se platnost volby nekontroluje, pokud hráč zadá nesmyslné číslo, peníze vyhodí oknem. Řádek 6 usadí koně na startovní pozici (pozice koní jsou v odpovídajícím prvku pole @). Řádky 7 a 8 připraví grafiku závodu. Na řádku 9 se vygeneruje, který kůň náhodně postoupí o jedno políčko. To je vykresleno na řádku 10 s tím, že pozice koně se uloží do jeho proměnné.
Řádek 11 řeší případné vítězství koně a ukončení závodu. Na řádcích 12 až 15 se vyplácí výhra, odebírají prohrané peníze a případně ukončuje hra při nedostatku peněz.

Příklad 32:

Zadání:
Napište pro TinyBasRO jednoduchou hru „Žabí skokani“. Na začátku budou 4 žáby jednoho druhu vlevo a 4 žáby druhého druhu vpravo. Uprostřed je jedna mezera. Hráč může skočit s libovolnou žábou do vedlejší mezery nebo jednu sousední žábu do mezery přeskočit. Cílem je na co nejmenší počet skoků přemístit žáby zleva na pravou stranu a naopak.

Rada:
Použijte příkazy INPUT, LET, PUTCH, PRINT, CURSOR, GOTO a IF-THEN. Počáteční a cílovou pozici si můžete uložit do pole @. Znaky pro žáby vlevo a vpravo si zvolte sami. Hráč bude muset vždy zadat „odkud“ skáče „kam“. Jednoduše to lze zadávat číslem např. 34 – skok z pozice 3 na 4. Budete muset ošetřit, aby hráč nezadal nesmyslné pozice skoku. Nesmí také skákat přes 2 a více žab naráz.

Příklad řešení:
0 REM Zabi skokani
1 LET P=0; LET @1=8,8,8,8,15,1,1,1,1
2 LET @10=1,1,1,1,15,8,8,8,8
3 PUTCH 12; LET I=1
4 CURSOR I*2; PUTCH v80+@I; PRINT I
5 LET I=I+1; IF I<10 THEN GOTO 4
6 PRINT “\n\n“; INPUT M; IF M>99 THEN GOTO 3 7 LET F=M/10; LET T=M-F*10; LET D=F-T
8 IF T<1 THEN GOTO 3
9 IF F<1 THEN GOTO 3
10 IF D<0 THEN LET D=-D
11 IF @T<>15 THEN GOTO 3
12 LET I=1; IF D>2 THEN GOTO 3
13 LET P=P+1; LET @T=@F; LET @F=15 14 LET K=I+9; IF @I<>@K THEN GOTO 3 15 LET I=I+1; IF I<10 THEN GOTO 14
16 PRINT “\nUspech na “,P,“ skoku“

Poznámky k řešení:
V proměnné P je uložen počet skoků. V poli jsou nejprve uloženy pozice žab při startu a pak i cílová pozice. Čísla jsou malá aby se snadno v programu zapsala. Pro zobrazení budou znaky zvýšeny o 80, takže levé žáby se objeví jako Q (81), pravé jako X (88) a volná pozice bude podtržítko (95). Na řádcích 3 až 5 je vykresleno hrací pole s žábami i s jejich pozicemi.
Na řádku 6 hráč zadá svůj skok. Ihned se kontroluje, zda číslo není moc velké. Na řádku 7 se rozdělí odkud (F) a kam (T) se skáče a jak dlouhý je to skok (D). Řádky 8 a 9 kontrolují, zda nebyla někde zadána 0 nebo záporné číslo. Řádek 10 opraví délku skoku na kladné číslo.
Řádek 11 kontroluje, jestli se skáče do volné pozice, řádek 12, není-li skok moc dlouhý. Na řádku 13 se provede platný skok. Řádky 14 a 15 zkontrolují případný konec hry při dosažení cíle.

Příklad 33:

Zadání:
Použijte TinyBasRO pro řízení sloupce 8 LED typu WS2812 připojených na D1. Na všech LED se bude postupně měnit 8 základních barev vzniklých kombinací RGB.

Doplňkový HW:
Na vstup D1 připojte řadu alespoň 8 ks LED typu WS2812. Tvar řetězce a počet LED upravte podle toho, co máte k dispozici.

Rada:
Použijte příkazy DOUT s parametrem w, DELAY, LET, GOTO a IF-THEN. Rychlost změny barev si zvolte podle vlastního vkusu.

Příklad řešení:
0 REM Barevne svetlo
1 LET @0=4210752,4210688,4194368 2 LET @3=4194304,16448,16384,64,0 3 DOUT w8
4 LET A=@7; LET I=7
5 LET J=I-1; LET @I=@J; LET I=J 6 IF I>0 THEN GOTO 5
7 LET @0=A; DELAY 500
8 GOTO 3

Poznámky k řešení:
Na řádcích 1 a 2 jsou uloženy barvy pro 8 kombinací RGB. Řádek 3 pošle hodnoty do řetězce. Pak je na řádku 4 uložena hodnota posledního prvku pole do proměnné A. Řádky 5 a 6 posunou všechny hodnoty do prvku pole o 1 vyššího. Na 7 řádku se vrací uložená hodnota z posledního prvku na začátek pole a počká se požadovanou dobu.

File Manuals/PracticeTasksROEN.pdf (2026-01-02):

## Tiny BASIC language exercises (RO ver 1)

Task 1:

Assignment:
Create a program to calculate the area of a rectangle. When the program is run, the user will be prompted to enter the lengths of the sides. Then the area will be printed. Calculate everything with integer values.

Advice:
Use the PRINT and INPUT statements. The area of a rectangle is calculated as the product of the lengths of its sides.

Solution example:
0 REM Calculate area of rectangle 1 PRINT “Enter length of sides:\n“ 2 INPUT A; INPUT B
3 PRINT “The area is: “ , A*B

Solution notes:
The program could be written on one line:
1 INPUT A; INPUT B; PRINT “The area is: “ , A*B

Rev. A

Task 2:

Assignment:
Write a program to calculate the area of a circle to 2 decimal places. When the program is run, the user is prompted to enter the radius of the circle and then the area is printed.

Advice:
Use the PRINT, LET, IF-THEN, and INPUT statements. Tiny BASIC only calculates with whole numbers. Use the value of π as 314 to calculate the area, and then display the result in sequence. First, print the whole value obtained by dividing by 100, the decimal point symbol, and then the remainder after dividing by 100. Remember that the remainder after division must be displayed with the first zero - e.g. 08.
The formula for calculating the area is known:

Solution example:
0 REM Calculate area of circle
1 PRINT “Enter radius:\n“
2 INPUT R
3 LET S=R*R*314; LET C=S/100 4 PRINT “The area is: “ , C, “.“
5 LET Z=S-C*100
6 IF Z<10 THEN PRINT “0“
7 PRINT Z

Solution notes:
Tiny BASIC does not have an operation for powers of numbers. That is why the square power is written as R*R (line 3). And it also does not work with decimal numbers. Multiplying by 314 instead of 3.14 gives a result 100 times larger. To get the whole part of the result, we must divide S by 100 (line 3). The remainder, which we calculate after subtracting the integer part multiplied by 100, must then be displayed, including any leading zero (line 6).

Task 3:

Assignment:
Create a program that prints all odd numbers up to 20.

Advice:
Use PRINT, LET, GOTO, and IF-THEN statements.

Solution example:
0 REM Odd numbers up to 20 1 LET A=1
2 PRINT A, “\n“
3 LET A=A+2
4 IF A<20 THEN GOTO 2

Solution notes:
This is a very simple counting loop. We start at 1 (line 1) and gradually print the numbers on separate lines (line 2) in increments of 2 (line 3). The evaluation condition (line 4) returns the program to print the number until 20 is reached.

Task 4:

Assignment:
Create a program that draws a rectangular triangle of the characters * 10 lines high on the screen.

Advice:
Use PUTCH, LET, GOTO, and IF-THEN statements. The newline character has the value 10 and the * character has the value 42.

Solution example:
0 REM Triangle *
1 PUTCH 10
2 LET A=1; REM Count lines 3 LET B=1; REM Stars on line 4 PUTCH 42; LET B=B+1
5 IF B<=A THEN GOTO 4
6 PUTCH 10; LET A=A+1
7 IF A<11 THEN GOTO 3

Solution notes:
There are 2 nested counting loops used here. In variable A, the lines are counted (lines 2,6,7) and in variable B, the characters printed on the line are counted (lines 3,4,5).

Task 5:

Assignment:
Create a program that draws a square with a side length of 10 characters on the screen.

Advice:
Use the PUTCH, PRINT, LET, GOTO, and IF-THEN statements. To save yourself some work, use a subroutine with GOSUB and RETURN statements to draw the horizontal line. Remember to end the program at the right point with the END statement.
The character to clear the display is 12, the new line is 10, the upper left corner is 144, the upper right corner is 145, the lower left corner is 146, the lower right corner is 147, the vertical line is 156, and the horizontal line is 157.

Solution example:
0 REM Square
1 PUTCH 12
2 LET A=1; REM Count lines 3 PUTCH 144; GOSUB 10
4 PUTCH 145; PUTCH 10
5 PUTCH 156; PRINT “ “
6 PUTCH 156; PUTCH 10; LET A=A+1 7 IF A<8 THEN GOTO 5
8 PUTCH 146; GOSUB 10
9 PUTCH 147; PUTCH 10; END
10 REM Horizontal line
11 LET I=1
12 PUTCH 157; LET I=I+1
13 IF I<9 THEN GOTO 12
14 RETURN

Solution notes:
Lines 3 and 4 draw the top of the square, lines 8 and 9 draw the bottom of the square. The subroutine on lines 10 through 14 is used to draw a horizontal line. Lines 5, 6, and 7 draw vertical lines. The number of spaces in the PRINT statement on line 5 must be 8 to empty the body of the square.

Task 6:

Assignment:
Write a program that allows you to move the character X around the screen. Starting in the middle of the screen, pressing the key 2 moves the character X down, 4 moves it left, 6 moves it right, and 8 moves it up.

Advice:
Use the PUTCH command using its parameters, CURSOR, INKEY, GOTO, and IF-THEN.
The character to clear the display has a value of 12, the X character is 88, the blank character is 32, 2 is 50, 4 is 52, 6 is 54, and 8 is 56.

Solution example:
0 REM Move X
1 PUTCH 12
2 CURSOR 157; PUTCH .88
3 INKEY K
4 IF K=50 THEN PUTCH v32; PUTCH .88 5 IF K=52 THEN PUTCH <32; PUTCH .88 6 IF K=54 THEN PUTCH >32; PUTCH .88 7 IF K=56 THEN PUTCH ^32; PUTCH .88
8 GOTO 3

Solution notes:
The program first clears the screen and places an X in the middle of the display (position 400) using the PUTCH command. The dot symbol ensures that the cursor remains at that position. When the user presses the correct key, the old position is first cleared with a blank character and the cursor moves to the new position (the direction is determined by the symbol before the value 32). The X is then printed at the new position and the cursor remains.

Task 7:

Assignment:
Create a program that will automatically "play ping-pong". A ball in the shape of the letter o will fly along a line from the left side to the right side and vice versa. It will always bounce off the edge of the screen and return.

Advice:
Use the PUTCH command using the parameters, CURSOR, DELAY, GOTO and IF-THEN.
The character to clear the display has a value of 12, the character o is 111, the blank character is 32. The position in the middle of the middle line has a value of 157, the character on the left edge 147, the right 167.

Solution example:
0 REM Ping-pong
1 PUTCH 12; LET C=157
2 CURSOR C; PUTCH .111
3 LET D=1
4 DELAY 100; PUTCH .32
5 LET C=C+D; CURSOR C; PUTCH .111 6 IF C=167 THEN LET D=-1
7 IF C=147 THEN LET D=1
8 GOTO 4

Solution notes:
First, the program is set to the initial position and the direction of the ball's movement in the variable D is set to the value 1 - i.e. the ball will fly to the right (lines 1 to 3). In the loop that starts on line 4, it waits for a while, deletes the old image of the ball and then moves the ball to a new position according to the value in D. Lines 6 and 7 monitor the edge of the screen and change the direction of flight there (D=1) or back (D=-1).

Task 8:

Assignment:
Write a program that plays a melody according to the notes in the image. At the beginning, the user enters the duration of a 1/8 note in the range 200 to 400 milliseconds.

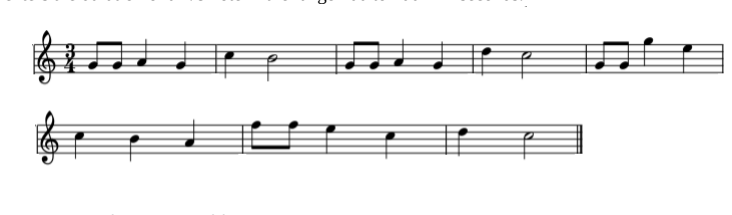
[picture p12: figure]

Approximate frequencies of fundamental tones:
c‘: 262 | d‘: 294 | e‘: 330 | f‘: 349 | g‘: 392 | a‘: 440 | h‘: 494
c“: 523 | d“: 587 | e“: 659 | f“: 698 | g“: 784 | a“: 880 | h“: 989

Advice:
Use the BEEP command with the parameters, INPUT, GOTO and IF-THEN. If the same passages appear in the melody, you can use the GOSUB and RETURN subroutines to avoid having to copy the same parts. Don't forget to end the program with the END command.

Solution example:
0 REM Melody
1 PRINT “Enter the pace:\n“ 2 INPUT T
3 IF T<200 THEN GOTO 1
4 IF T>400 THEN GOTO 1
5 GOSUB 15
6 BEEP 523,2*T; BEEP 494,4*T; GOSUB 15 7 BEEP 587,2*T; BEEP 523,4*T; BEEP 392,T 8 BEEP 392,T; BEEP 784,2*T; BEEP 659,2*T
9 BEEP 523,2*T; BEEP 494,2*T; BEEP 440,2*T 10 BEEP 698,T; BEEP 698,T; BEEP 659,2*T
11 BEEP 523,2*T; BEEP 587,2*T; BEEP 523,4*T 12 END
15 BEEP 392,T; BEEP 392,T; BEEP 440,2*T
16 BEEP 392,2*T; RETURN

Solution notes:
The user is first prompted to enter a tempo and the allowed range of values is checked (lines 1 to 4). Since the first four notes repeat in the third measure, the subroutine on lines 15 and 16 is used. The individual notes are specified by frequency and duration. A quarter note is double and a half note is quadruple the specified duration of an eighth note.

Task 9:

Assignment:
Write a program to create a very simple piano. When keys 1 to 9 are pressed, it will play the notes c' to d" for 200 to 600 milliseconds (the time is specified after the start).
Approximate frequencies of the fundamental notes:
c‘: 262 | d‘: 294 | e‘: 330 | f‘: 349 | g‘: 392 | a‘: 440 | h‘: 494
c“: 523 | d“: 587

Advice:
Use the BEEP command with the parameters, INPUT, INKEY, GOTO and IF-THEN. Try to take advantage of the fact that keys 1 to 9 return values 49 to 57 in the INKEY command. Then you can calculate the necessary jump in the GOTO command.

Solution example:
0 REM Piano
1 PRINT “Enter tone duration:\n“ 2 INPUT T
3 IF T<200 THEN GOTO 1
4 IF T>600 THEN GOTO 1
5 INKEY K
6 IF K<49 THEN GOTO 5
7 IF K>57 THEN GOTO 5
8 GOTO K-40
9 BEEP 262,T; GOTO 5
10 BEEP 294,T; GOTO 5
11 BEEP 330,T; GOTO 5
12 BEEP 349,T; GOTO 5
13 BEEP 392,T; GOTO 5
14 BEEP 440,T; GOTO 5
15 BEEP 494,T; GOTO 5
16 BEEP 523,T; GOTO 5
17 BEEP 587,T; GOTO 5

Solution notes:
The user is first prompted to enter the tone duration and the allowed range of values is checked (lines 1 to 4). In the loop that starts on line 5, it is first checked whether the key is among the allowed ones and then the jump to the line with the corresponding tone is calculated on line 8. The value of the first allowed digit 49 must go to line 9, so the value 40 is subtracted.

Task 10:

Assignment:
Create a program that will represent a lottery device for the numbers 1 to 49. Each time you press any key, it will display a random number from the specified range.

Advice:
Use the TIME, INKEY, PRINT, GOTO and IF-THEN commands.
After pressing a key, take the current time. Its remainder after dividing by 49 will be a sufficiently random number. Remember that the remainder after dividing by 49 is in the range 0 to 48. The obtained value needs to be increased by 1.

Solution example:
0 REM Lottery
1 INKEY K
2 IF K=0 THEN GOTO 1
3 TIME T; LET A=T/49
4 PRINT T-A*49+1, “\n“
5 GOTO 1

Solution notes:
Lines 1 and 2 wait for any key to be pressed. When the user presses a key, the variable T is filled with the TIME command. The value obtained by the TIME command changes approximately 32,000 times per second. Since we need random numbers up to 49, we calculate the remainder after dividing by 49. We display the result increased by 1.

Task 11:

Assignment:
Create a program that displays the time elapsed since the computer was started in the form HH:MM:SS.

Advice:
Use the TIME, PRINT, PUTCH, CURSOR, GOTO and IF-THEN commands.
If you divide the value obtained by the TIME command by 31914, you will get the time since the computer was started in seconds. Then you just need to divide the obtained time by 3600 to get the number of hours that have passed. Then divide the remainder by 60 to get the minutes. Do not forget that in Assignment the number is displayed to 2 places. It is not enough to just print out e.g. 5, it needs to be displayed as 05. A subroutine with GOSUB and RETURN can be useful for this. The character : has the value 58, the character 0 has the value 48.

Solution example:
0 REM Clock
1 PUTCH 12
2 DELAY 300
3 TIME T; LET S=T/31914
4 LET A=S/3600; LET S=S-A*3600 5 CURSOR 0; GOSUB 10
6 LET A=S/60; LET S=S-A*60
7 PUTCH 58; GOSUB 10
8 LET A=S; PUTCH 58; GOSUB 10 9 GOTO 2
10 REM List A to 2 digits
11 IF A<10 THEN PUTCH 48
12 PRINT A; RETURN

Solution notes:
We divide the time obtained by the TIME command by 31914 to get the total time in seconds. We get the hours in variable A by dividing by 3600. The remainder after integer division will be minutes and seconds. By integer division by 60 we get minutes and the remainder from the calculation of minutes is seconds. We have to display everything to 2 places, so we add any leading zero for single-digit numbers when displaying the value from A in the subroutine (line 11).

Task 12:

Assignment:
Create a “kitchen timer” using a computer. After starting the program, the user enters a time from 1 to 99 minutes. After entering, the display will start counting down in minutes and when it reaches 0, a signal will sound for 10 seconds.

Advice:
Use the TIME, BEEP, INPUT, PRINT, GOTO and IF-THEN commands. After entering the desired time, you can calculate the time at which the timing will end. The target time is obtained by adding the number of minutes multiplied by 60*31914 (seconds in a minute times the number of ticks per second = 1914840) to the current time.

Solution example:
0 REM Kitchen timer
1 PRINT “Enter time [min]:\n“ 2 INPUT T
3 IF T<1 THEN GOTO 1
4 IF T>99 THEN GOTO 1
5 TIME C; LET C=C+T*60*31914 6 PUTCH 12
7 DELAY 300
8 TIME T; LET D=C-T
9 IF D<0 THEN BEEP 800,10000; END 10 CURSOR 0; PRINT D/1914840, “ “
11 GOTO 7

Solution notes:
The user is first prompted to enter a time and the allowed range of values is checked (lines 1 to 4). After correct entry, the target time is stored in the variable C, which is calculated as the current time with the time entered by the user multiplied by 31914 (number of ticks per second) and 60 (number of seconds in a minute). In the loop that starts on line 7, we wait a while because it is not necessary to display the values so quickly that the user would not notice it anyway. On line 8, we find the difference between the target and current time. If the result is negative, we end the timing. Otherwise, we display the difference. The constant 1914840 is created by multiplying 60*31914.

Task 13:

Assignment:
Program the game "Better Perception" for two or more players. After pressing a key, it waits 5 seconds, while the timing starts *. Then it displays the target character on the display. The key that was pressed first after the target character was displayed will be declared the winner.

Advice:
Use INKEY, DELAY, PUTCH, PRINT, GOTO and IF-THEN statements. When writing your program, remember to check if the player pressed a key before displaying the target character. The * character has the value 42, the target character has the value 143.

Solution example:
0 REM Perception
1 PRINT “\nGame start\n“
2 INKEY K
3 IF K=0 THEN GOTO 2
4 PUTCH 42; DELAY 5000; INKEY K 5 PUTCH 143; IF K>0 THEN GOTO 10
6 INKEY K
7 IF K=0 THEN GOTO 6
8 PRINT “\nWinner: “; PUTCH K; DELAY 2000 9 GOTO 1
10 PRINT “\nLoser: “; PUTCH K; DELAY 2000
11 GOTO 1

Solution notes:
On lines 1 to 3 we wait for the game to start. Then we display *, wait 5 seconds, and check if someone pressed a key prematurely (line 4). On line 5 we display the target character and check for premature keypresses. If everything is OK, on lines 6 and 7 we wait for a keypress, and on line 8 we declare the winner.

Task 14:

Assignment:
Create a program for an acoustic generator. The user enters the frequency of the desired tone in the range of 100 to 4000 Hz and the computer beeps the entered tone until the program is terminated.

Advice:
Use the BEEP, INPUT, PRINT, GOTO, and IF-THEN statements.
To be able to stop the program by inserting an END statement, use some acceptable value in the time parameter of the BEEP statement in the range of seconds.

Solution example:
0 REM Audio generator
1 PRINT “Insert freq. 100-4000\n“ 2 INPUT F
3 IF F<100 THEN GOTO 1
4 IF F>4000 THEN GOTO 1
5 BEEP F,5000
6 GOTO 5

Solution notes:
The user is first prompted to enter a frequency and the allowed range of values is checked (lines 1 to 4). Then, a tone of the specified frequency is played continuously in a loop on lines 5 and 6.

Task 15:

Assignment:
Write a program in which the user enters a name followed by the Enter key. The computer then prints out that the name is his friend. The maximum length of the name can be 30 characters.

Advice:
Use the INKEY, PRINT, PUTCH, GOTO and IF-THEN commands. It is convenient to store the entered name in variables in the @ array. Count the number of letters stored.

Solution example:
0 REM Computer friend
1 LET I=0; PRINT “\nEnter name:\n“ 2 INKEY K
3 IF K=0 THEN GOTO 2
4 IF K=10 THEN GOTO 10
5 PUTCH K; LET @I=K; LET I=I+1 6 IF I=30 THEN GOTO 10
7 GOTO 2
10 LET J=0; PUTCH 10
11 PUTCH @J; LET J=J+1
12 IF J<I THEN GOTO 11
13 PRINT “ is my friend\n“

Solution notes:
Lines 2 and 3 wait for a character to be entered. Line 4 checks whether the input was terminated by pressing the Enter key. Line 5 stores the character in the array. Line 6 checks the maximum allowed length of the name. Lines 10 to 12 print the name again.

Task 16:

Assignment:
Create a program to control an LED connected to output D1 using the keyboard. The first press of any key turns the LED on, the second press turns it off, the next press turns it on again, and so on.

Additional HW:
Connect an LED with a resistor to the D1 output as shown in the following figure. The red LED will be suitable for the following task.

Advice:


Use the INKEY, DOUT, GOTO, and IF-THEN statements. The DOUT 1,1 statement turns the LED on, and the DOUT 0,1 statement turns it off.
Since the program doesn't have to be fast, you can insert a small delay into the keypress cycle with the DELAY statement.

Solution example:
0 REM LED control
1 LET L=0
2 DELAY 100; INKEY K
3 IF K=0 THEN GOTO 2
4 IF L=0 THEN GOTO 6
5 LET L=0; DOUT 0,1; GOTO 2
6 LET L=1; DOUT 1,1; GOTO 2

Solution notes:
The variable L stores the current value of the output so that we know how to change the output next time. Lines 2 and 3 wait for a key press. Line 4 decides whether the LED turns on or off based on the state of L.

Task 17:

Assignment:
Create a program that turns TinyBasRO into a control for warning lights at a railroad crossing, including sound signaling.

Additional HW:
Connect two LEDs (preferably red) with resistors to outputs D1 and D2 as shown in the following figure.

Advice:

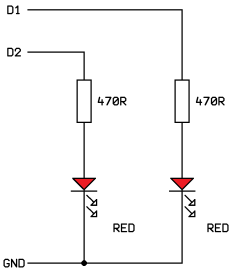
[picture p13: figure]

Use the BEEP, DELAY, DOUT and GOTO commands. Try out the sound signaling and adjust it to your liking.

Solution example:
0 REM Railroad crossing
1 DOUT 1,1; DOUT 0,2
2 BEEP 2000,100; BEEP 800,200; DELAY 200 3 DOUT 0,1; DOUT 1,2
4 BEEP 2000,100; BEEP 800,200; DELAY 200
5 GOTO 1

Solution notes:
Lines 1 and 3 always light up only one of the two LEDs. Lines 2 and 4 generate the same sound signal. The example given only very vaguely resembles the ringing of a bell. You can tune and adjust them to your ear...

Task 18:

Assignment:
Create a program to measure the input voltage at the AIN input in mV. Apply the voltage from the potentiometer slider to the input, which will be displayed with a period of ½ second.

Additional HW:
Connect a linear potentiometer with a resistance value in the range of 1 to 100 kΩ to the AIN output according to the following figure.

Advice:


Use the AINP, DELAY, CURSOR, PRINT, and GOTO commands. The value obtained from the A/ D converter is in the range 0 to 1023. This represents a voltage of 0 to 5V – that is, 0 to 5000 mV. To convert the A/D converter range to mV, we must first multiply the value by 5000 and then divide by 1023.

Solution example:
0 REM Analog input mV
1 PUTCH 12
2 CURSOR 154; AINP A
3 PRINT A*5000/1023, “ mV “ 4 DELAY 500
5 GOTO 2

Solution notes:
On line 2, first set the cursor approximately to the center of the screen and then measure the voltage at the AIN input. The conversion is performed when the value is printed in the PRINT command according to the instructions in the Advice paragraph. After the units are printed, 3 spaces are added to erase any longer entries from the previous measurement.

Task 19:

Assignment:
Modify the TinyBasRO computer to work as a simple voltmeter with a range of up to 50 V. The voltage will be displayed with a period of ½ second and a resolution of 2 decimal places.

Additional HW:
Connect an input resistor divider to the AIN output with resistors with a resistance ratio of 9:1. For example, 900 kΩ and 100 kΩ would be ideal. However, the value of 900 kΩ is outside the normal range of available resistors. You can use the closest value of 910 kΩ from the E24 series. In an emergency, you can also use 1 MΩ and adjust the constant in the program.

Advice:


Use the AINP, DELAY, CURSOR, PUTCH, PRINT, GOTO, and IF-THEN commands. The value obtained by AINP from the A/D converter is in the range of 0 to 1023. This represents a voltage of 0 to 50V (we need to display 0.00 to 50.00 V). To convert the A/D converter range to V, we first need to multiply the value by 5000 and then divide by 1023. We display the resulting number with a decimal point between the digits.
The multiplication constant of 5000 is the ideal case, when an accurate reference voltage in the microcontroller and accurate resistance values of the two resistors in the divider are assumed. In practice, this will vary. Therefore, for a particular piece of computer, this value needs to be adjusted so that the displayed voltage is as close as possible to the voltage measured by the reference voltmeter.

Solution example:
0 REM Voltmeter 50V
1 PUTCH 12; LET K=5320
2 CURSOR 154; AINP A
3 LET V=A*K/1023; LET C=V/100 4 LET Z=V-C*100
5 PRINT C, “.“
6 IF Z<10 THEN PRINT “0“
7 PRINT Z
8 DELAY 500
9 GOTO 2

Solution notes:
Line 1 sets the conversion constant, which you must adjust according to the specific computer and input resistor divider. The next step copies the instructions given in the Advice paragraph. First, the entire part of the variable C is printed, and then the remainder after dividing 100 from Z. If the remainder is less than 10, it is necessary to add a leading zero (line 6).

Task 20:

Assignment:
Using a PCF8575 expander connected to a TinyBasRO, make a running light on a series of LEDs connected to the expander outputs.

Additional HW:
Connect multiple LEDs to the outputs of the PSC8575 expander module as shown in the picture. It depends on the number of LEDs you have available, a maximum of 16 LEDs can be connected.

Advice:


Use the I2CW, DELAY, LET, GOTO and IF-THEN commands. To light the first LED, you need to send the binary number b1111111111111110 or decimal -2 to the expander. The second LED requires sending the binary number b1111111111111101 or decimal -3. The next would be the binary number b1111111111111011 or decimal -5. The LED lighting is moved to the next position by multiplying by 2 and adding 1.
After the last LED is lit, the light must return to the beginning.

Solution example (for 8 LEDs): 0 REM Running 8 LED
1 LET A=-2
2 I2CW A; DELAY 200
3 LET A=A*2+1
4 IF A < -300 THEN LET A=-2
5 GOTO 2

Solution notes:
The program follows the instructions given in the Advice paragraph. In the given example, only 8 LEDs were used, when reaching a value less than -300 the value in A returns to the beginning. Sending the number -257 to the expander (the last one sent in the cycle) will turn off all 8 LEDs for a while. If you do not want this, reduce the condition, for example, to A<-150.

Task 21:

Assignment:
Write a program that uses a PCF8575 expander connected to TinyBasRO to light up a specified number of LEDs (an image of your choice) when you press the 0 to 9 key.

Additional HW:
Connect multiple LEDs to the outputs of the PSC8575 expander module as shown in the picture. It depends on the number of LEDs you have available, a maximum of 16 LEDs can be connected.

Advice:

Use the I2CW, DELAY, INKEY, GOTO and IF-THEN commands. You can specify any pattern of LED lights for each digit. For example, pressing key 1 will light up each odd LED with the I2CW command b1010101010101010, key 2 will light up the bottom half of the LEDs with the I2CW command b111111100000000, etc.
Keys 0 to 9 return values 48 to 57 in the INKEY command.

Solution example:
0 REM LED patterns
1 DELAY 100; INKEY K
2 IF K<48 THEN GOTO 1
3 IF K>57 THEN GOTO 1
4 GOTO K-43
5 I2CW b1100110011001100; GOTO 1 6 I2CW b1010101010101010; GOTO 1 7 I2CW b1111111100000000; GOTO 1 8 I2CW b1111100001100101; GOTO 1 9 I2CW b0000000011001100; GOTO 1 10 I2CW b1100110000000000; GOTO 1 11 I2CW b1110111011101110; GOTO 1 12 I2CW b1101110111011101; GOTO 1 13 I2CW b1011101110111011; GOTO 1
14 I2CW b0111011101110111; GOTO 1

Solution notes:
First, lines 1, 2, and 3 ensure that only the allowed number keys are accepted. Line 4 then ensures a jump to the appropriate pattern of lit LEDs and a return to the beginning.

Task 22:

Assignment:
Program a user's perception meter. After pressing a key, the program waits a random number of seconds (1 to 10), with the timing starting at *. Then it displays the target character on the display. The user must press any key as quickly as possible. The display shows the reaction time in milliseconds.

Advice:
Use the INKEY, TIME, DELAY, PUTCH, PRINT, GOTO, and IF-THEN commands. When writing your program, remember to check to see if the player pressed a key before the target character is displayed. To measure time in milliseconds, we will assume that TIME returns a value 32 larger for each millisecond.
The * character has the value 42, the target character has the value 143.

Solution example:
0 REM Perception meter
1 PRINT “\nStart\n“
2 INKEY K
3 IF K=0 THEN GOTO 2
4 TIME T; LET C=T/10
5 LET D=T-C*10+1; LET D=D*1000 6 PUTCH 42; DELAY D
7 INKEY K; PUTCH 143; TIME S 8 IF K>0 THEN GOTO 14
9 INKEY K
10 IF K=0 THEN GOTO 9
11 TIME E; LET R=E-S
12 PRINT “\nReaction: “, R/32 13 PRINT “ milisec“; GOTO 1 14 PRINT “\nPrematurely!“
15 GOTO 1

Solution notes:
Lines 2 and 3 wait for the measurement to start. Then, using the TIME command and the remainder after dividing by 10, a random time is obtained, which is stored in the variable D in milliseconds (lines 4 and 5). Line 6 displays * and waits. Line 7 reads the key state, displays the target character, and stores the starting time for the perception measurement. Line 8 checks for any premature key presses. Lines 9 and 10 wait for the user to respond. The time at which the user responded is stored in E, and then lines 11, 12, and 13 print the result.

Task 23:

Assignment:
If you have the choice to connect a dot matrix printer with a parallel port to the TinyBasRO via a PCF8575 expander, create a simple typewriter from it.

Additional HW:
Connect the Cannon 25 female connector to the outputs of the PCF8575 expander module as shown in the picture.

Advice:


Use the I2CW, DELAY, INKEY, GOTO and BEEP commands. The BEEP command is used to sound a short beep when a key is pressed. It is not necessary to use it.
On pin 1 of the parallel port there is a STROBE signal controlled by output P10, which confirms and writes data to the printer. The active value is logical 0. After writing the data, it is necessary to return this signal to the idle value 1. This is easiest to do by writing a value 256 greater than the data being written.

Solution example:
0 REM Typewriter
1 INKEY K
2 IF K=0 THEN GOTO 1
3 I2CW K; PUTCH K
4 DELAY 10
5 I2CW K+256; BEEP 1000,50
6 GOTO 1

Solution notes:
Lines 1 and 2 wait for a keystroke. Line 3 sends the character to the printer and copies it to the display. Line 4 waits for a moment (in case the printer is slow to respond). Line 5 must set the STROBE signal for the printer back to logic 1 (the character value is increased by the 9th bit set to
1) and a short beep is emitted.

Task 24:

Assignment:
Create a simple integer calculator from TinyBasRO. The user enters the first number, then the operand (+ - * /) and finally the second number. The calculated result appears on the display in the form, for example, 256*2=512.

Advice:
Use the INPUT, INKEY, PRINT, PUTCH, GOTO, and IF-THEN commands. The operand characters have the following values:
+ | 43 | - | 45 | * | 42 | / | 47
Don't forget that we don't divide by zero!

Solution example:
0 REM Calculator
1 PUTCH 10; INPUT A
2 INKEY K
3 IF K=42 THEN GOTO 8
4 IF K=43 THEN GOTO 8
5 IF K=45 THEN GOTO 8
6 IF K=47 THEN GOTO 8
7 GOTO 2
8 PUTCH K; PUTCH 10; INPUT B;
9 PRINT A; PUTCH K; PRINT B
10 IF K=43 THEN PRINT “=“,A+B; GOTO 1
11 IF K=45 THEN PRINT “=“,A-B; GOTO 1
12 IF K=42 THEN PRINT “=“,A*B; GOTO 1
13 IF B=0 THEN PRINT “0 not possible!“; GOTO 1
14 PRINT “=“,A/B; GOTO 1

Solution notes:
The first value is stored in variable A on line 1. Then lines 3 through 7 wait for the operation type. Line 8 prints the operation character and waits for the second value. Lines 10 through 14 perform the calculation based on the state of K, with line 13 checking for division by 0.

Task 25:

Assignment:
Write a program to guess a secret number from 0 to 99. After starting, the computer chooses a random number and the player has to guess this number in the fewest number of attempts possible. After each attempt, the computer indicates whether the secret number is greater or less than the one entered by the player.

Advice:
Use the INPUT, PRINT, TIME, LET, GOTO, and IF-THEN statements. First, generate a random number using the TIME statement and the remainder after dividing by 100.

Solution example:
0 REM Guess number
1 TIME T; LET C=T/100; LET X=T-C*100 2 LET P=0; PRINT “\nGuess number\n“ 3 INPUT A; LET P=P+1
4 IF A=X THEN GOTO 8
5 IF A>X THEN GOTO 7
6 PRINT P,“. Guess more\n“; GOTO 3 7 PRINT P,“. Guess less\n“; GOTO 3
8 PRINT “You guessed in “, P, “ tries\n“

Solution notes:
On line 1, a randomly generated guessed number is stored in variable X using the TIME command and the remainder after integer division by 100. On lines 2 and 3, the user is asked to try to guess the number, and the number of attempts is counted in variable P. Lines 4 and 5 check the success of the attempt, and the remaining lines print instructions on where to go for the next guess or exit the program with the result.

Task 26:

Assignment:
Create a simple code lock from TinyBasRO. If the user enters the correct sequence of 4 or 5 digits on the keyboard, a logical 1 will appear on the D1 output for 3 seconds and a sound signal will sound.

Advice:
Use the INKEY, LET, DOUT, BEEP, GOTO and IF-THEN commands. You can choose the number of code digits yourself. Store the secret number combination in the @ array and each correctly guessed digit will move the pointer in the array to a higher value. If you make a mistake, the pointer will return to the beginning of the array.
The keys 0 to 9 return the values 48 to 57 in the INKEY command.

Solution example:
0 REM Code lock
1 LET @0=49,57,50,48,51
2 LET P=0
3 INKEY K
4 IF K=0 THEN GOTO 3
5 IF K<>@P THEN GOTO 2
6 LET P=P+1;
7 IF P<5 THEN GOTO 3
8 DOUT 1,1; BEEP 800,3000; DOUT 0,1
9 GOTO 2

Solution notes:
On line 1, the lock code is stored in the @ array. The variable P shows where the user got to when entering the code. Line 5 decides whether to advance to the next position or return to the first digit of the code. On line 7, if the procedure is correct and the P pointer reaches the value 5, it is possible to move to line 8, where the code lock opens for 3 seconds.

Task 27:

Assignment:
Write a program that will replace a dice. The program will display the points on the screen as they are located on the dice.

Advice:
If you look at the patterns on the sides of the cube, you will notice that, except for the center dot, the dots always appear in pairs. For example, 3 is a combination of A+B, 5 is A+B+C.


You can encode patterns into an array, for example using binary numbers, and then display them according to a randomly drawn number. Recommended cursor positions are for A: 157, for B: 69 and 245, for C: 77 and 237, and for D: 153 and 161. Use the LET, TIME, INKEY, GOTO, CURSOR, PUTCH, and IF-THEN commands.

Solution example:
0 REM Dice
1 PUTCH 12; LET @0=1,2,3,6,7,14
2 INKEY K
3 IF K=0 THEN GOTO 2
4 TIME D; LET C=D/6; LET D=D-C*6
5 CURSOR 157; PUTCH .32; IF @D&1 THEN PUTCH 143 6 CURSOR 69; PUTCH 32; CURSOR 245
7 PUTCH .32; IF@D&2 THEN PUTCH 143
8 CURSOR 69; IF@D&2 THEN PUTCH 143
9 CURSOR 77; PUTCH 32; CURSOR 237 10 PUTCH .32; IF@D&4 THEN PUTCH 143 11 CURSOR 77; IF@D&4 THEN PUTCH 143 12 CURSOR 153; PUTCH 32; CURSOR 161 13 PUTCH .32; IF@D&8 THEN PUTCH 143 14 CURSOR 153; IF@D&8 THEN PUTCH 143
15 GOTO 2

Solution notes:
The @ array encodes the display of the numbers 0 to 5 using binary code. If you look at how the numbers are written in binary, you will see that the lowest bit represents dot A, the next higher bit represents both dots B, the next C, and the fourth bit is dot D. Lines 2 and 3 wait for a key to be pressed. Line 4 generates a random number 0 to 5 in variable D. Then all positions of the individual dots are traversed. For example, in line 5, the cursor is set to dot A and it is deleted first. If the array element with index D has the lowest bit set, the dot at the position is drawn.

Task 28:

Assignment:
Complete the TinyBasRO to function as an emergency lighting control panel. The photoresistor will be used to sense the ambient light level and the measured value will be displayed on the display. The user will initially enter the values at which the LED connected to D1 will turn on and off.

Additional HW:
Connect a divider with a photoresistor and an LED with a resistor to the AIN input and D1 output as shown in the figure.

Advice:

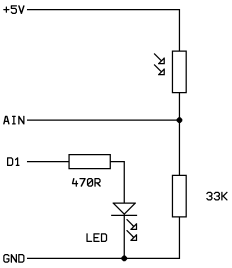
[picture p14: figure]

Use the INPUT, PRINT, DOUT, AINP, GOTO and IF-THEN commands. The measured light value will be just a number from the A/D converter. The user can set 2 limits at which the light turns on or off, thus setting the hysteresis of the circuit. Make sure that the entered limits are not outside a reasonable range.
You can use a type 5537 or similar as a photoresistor.

Solution example:
0 REM Emergency lighting
1 PRINT “\f0\n\n“
2 INPUT H
3 IF H<10 THEN GOTO 2
4 IF H>1000 THEN GOTO 2
5 INPUT L
6 IF L>=H THEN GOTO 5
7 AINP A; CURSOR 0; PRINT A,“ “ 8 IF A<L THEN DOUT 1,1
9 IF A>H THEN DOUT 0,1
10 DELAY 200; GOTO 7

Solution notes:
Lines 2 to 6 require the entry of the limits at which the LED turns off or on (including checking the allowed values). The actual loop is on lines 7 to 10. After the measurement, the value is printed. The PRINT command is supplemented by deleting a longer number that could remain on the display from the previous measurement. Then, on lines 8 and 9, the LED is turned on or off.

Task 29:

Assignment:
Create a simple cryptographic device from TinyBasRO that will encode and decode characters from the alphabet to another character according to your chosen encryption table. The program must display both the encoded and the corresponding decoded character after pressing character on keyboard.

Advice:
Use the LET command to create an encryption table in the @ array. After checking whether the pressed key is among the allowed characters, select a character from the table, display it, and then search the table for decoding. Recommended commands are PRINT, INKEY, CURSOR, GOTO, and IF-THEN.

Solution example:
0 REM Cryptograph
1 LET @0=6,18,11,5,20,14,22,2,9,15 2 LET @10=17,8,1,10,19,0,13,4,23,24 3 LET @20=25,7,16,12,21,3
4 PRINT “\fChar Code Decode“
5 INKEY K
6 IF K<97 THEN GOTO 5
7 IF K>122 THEN GOTO 5
8 LET Z=K-97; CURSOR 22; PUTCH K 9 CURSOR 28; PUTCH 65+@Z; LET I=0 10 IF @I=Z THEN GOTO 12
11 LET I=I+1; IF I<26 THEN GOTO 10
12 CURSOR 35; PUTCH 65+I; GOTO 5

Solution notes:
The basis of the program is the encoding table in the @ array. All 26 characters of the English alphabet have their randomly chosen code. The character "a" has a code at position 0, "b" at 1, etc. The code numbers can be from 0 to 25.
We consider entering lowercase letters of the alphabet, their values will be 97 to 122. Lines 5 to 7 are waiting for this. We obtain a pointer to the encoding table in the variable Z by subtracting the value 97 from the character. We print the entered character, its encoded form in the form of an uppercase letter, which begin with the values 65 (lines 8 and 9). On lines 10 and 11 we search the table for the opposite function - decoding. Line 12 prints the decoded character.

Task 30:

Assignment:
Write a program for a simple stopwatch. The first press of any key will start the measured time, the next press will stop the value. It will be displayed in minutes:seconds,tenths of seconds.

Advice:
Use the INKEY, LET, PUTCH, PRINT, GOTO and IF-THEN commands. After starting the program, first wait for a key press. Save the current start time. Display the difference between the current time and the start time by dividing 3191 (the number of ticks per tenth of a second). First, the value divided by 600 – these will be minutes, then seconds and tenths of seconds. Remember to always display seconds to 2 decimal places. The character 0 has the value 48.
Another press stops the counting so that the time reached can be read. A third press of the key then returns the stopwatch to zero time and prepares it for starting.

Solution example:
0 REM Stopwatch
1 PUTCH 12; PRINT “0:00,0“ 2 INKEY K
3 IF K=0 THEN GOTO 2
4 TIME B
5 DELAY 80
6 TIME T; LET T=T-B; LET S=T/3191 7 LET A=S/600; LET S=S-A*600
8 CURSOR 0; PRINT A,“:“
9 LET A=S/10; LET S=S-A*10
10 IF A<10 THEN PUTCH 48
11 PRINT A,“,“,S
12 INKEY K; IF K=0 THEN GOTO 5 13 INKEY K
14 IF K=0 THEN GOTO 13
15 GOTO 1

Solution notes:
The solution follows the instructions in the Advice paragraph. First, the stopwatch is waited for to start (lines 2 and 3). The start time is stored in variable B. The human eye is not very fast, so the display loop has a delay on line 5. The elapsed time in tenths of a second is calculated in variable S on line 6. Lines 7 to 11 display the time on the display. Line 12 checks to see if the stopwatch has stopped. Lines 13 and 14 wait for the program to restart.

Task 31:

Assignment:
Write a program that represents a simple game called "Horse Racing". The player can bet an amount on one of three horses with an initial capital. The horses will finish in a random order.

Advice:
Use, for example, the commands INPUT, PRINT, PUTCH, LET, CURSOR, DELAY, TIME, GOTO and IF-THEN. Store the position of the horse in the @ array. This will make it easier to refer to the horse, which will be moved randomly using the TIME command.
When betting on the winning horse, add three times the bet to the player.

Solution example:
0 REM Horse Racing
1 LET M=1000
2 PRINT “\fBet? 1-“,M,“\n“
3 INPUT B; IF B<1 THEN GOTO 2 4 IF B>M THEN GOTO 2
5 PRINT “\nHorse 1-3?\n“; INPUT K 6 LET @1=1; LET @2=1; LET @3=1 7 PRINT “\fRace“; PUTCH p49,42
8 PUTCH p50,84; PUTCH p51,126
9 TIME T; LET V=T/3; LET V=T-V*3+1
10 DELAY 100; LET @V=@V+1; PUTCH p143,V*42+@V 11 IF @V<20 THEN GOTO 9
12 CURSOR 174; PRINT “Win “,V; DELAY 1000
13 IF V=K THEN LET M=M+B*3; GOTO 2
14 LET M=M-B; IF M>0 THEN GOTO 2
15 PRINT “\nNo money\n“

Solution notes:
The initial capital is set on line 1. Then the user is asked to determine the value of the bet with a check to see if he is trying to cheat (lines 2 to 4). Line 5 asks to bet on one of the three horses. Here, the validity of the choice is not checked; if the player enters a meaningless number, the money is thrown out the window.
Line 6 places the horse in the starting position (the horse positions are in the corresponding element of the array @). Lines 7 and 8 prepare the race graphics. Line 9 generates which horse will randomly advance one space. This is plotted on line 10, with the horse's position being stored in its variable.
Line 11 handles the eventual victory of the horse and the end of the race. Lines 12 to 15 pay out the winnings, collect the lost money, and eventually end the game if there is a shortage of money.

Task 32:

Assignment:
Write a simple game for TinyBasRO called "Frog Jumpers". At the beginning, there will be 4 frogs of one type on the left and 4 frogs of another type on the right. There is one gap in the middle. The player can jump with any frog into the adjacent gap or jump over one of the neighboring frogs into the gap. The goal is to move the frogs from the left to the right side and vice versa in the fewest number of jumps.

Advice:
Use the INPUT, LET, PUTCH, PRINT, CURSOR, GOTO and IF-THEN commands. You can store the starting and target positions in the @ array. Choose the characters for the frogs on the left and right yourself. The player will always have to enter "from where" frog jumps "to where". This can be simply entered as a number, e.g. 34 - jump from position 3 to 4. You will have to take care that the player does not enter meaningless jump positions. They are also not allowed to jump over 2 or more frogs at once.

Solution example:
0 REM Frog Jumpers
1 LET P=0; LET @1=8,8,8,8,15,1,1,1,1
2 LET @10=1,1,1,1,15,8,8,8,8
3 PUTCH 12; LET I=1
4 CURSOR I*2; PUTCH v80+@I; PRINT I
5 LET I=I+1; IF I<10 THEN GOTO 4
6 PRINT “\n\n“; INPUT M; IF M>99 THEN GOTO 3 7 LET F=M/10; LET T=M-F*10; LET D=F-T
8 IF T<1 THEN GOTO 3
9 IF F<1 THEN GOTO 3
10 IF D<0 THEN LET D=-D
11 IF @T<>15 THEN GOTO 3
12 LET I=1; IF D>2 THEN GOTO 3
13 LET P=P+1; LET @T=@F; LET @F=15 14 LET K=I+9; IF @I<>@K THEN GOTO 3 15 LET I=I+1; IF I<10 THEN GOTO 14
16 PRINT “\nDone in “,P,“ jumps“

Solution notes:
The number of jumps is stored in the variable P. The @ first stores the frogs' starting positions and then the target position. The numbers are small to make them easy to write in the program. For display, the characters will be increased by 80, so that the left frogs will appear as Q (81), the right as X (88), and the free position will be an underscore (95). Lines 3 to 5 draw the playing field with the frogs and their positions.
On line 6, the player enters his jump. It is immediately checked whether the number is not too large. On line 7, it is divided into from (F) and to (T) the jump is made and how long the jump is (D). Lines 8 and 9 check whether a 0 or negative number has been entered somewhere. Line 10 corrects the jump length to a positive number.
Line 11 checks whether the jump is made to a free position, line 12 if the jump is not too long. A valid jump is made on line 13. Lines 14 and 15 check for a possible game end when the goal is reached.

Task 33:

Assignment:
Use TinyBasRO to control a column of 8 WS2812 LEDs connected to D1. All LEDs will gradually change the 8 basic colors created by the RGB combination.

Additional HW:
Connect a string of at least 8 WS2812 LEDs to input D1. Adjust the shape of the string and the number of LEDs according to what you have available.

Advice:
Use DOUT with w, DELAY, LET, GOTO and IF-THEN commands. Choose the speed of the color change according to your taste.

Solution example:
0 REM Color light
1 LET @0=4210752,4210688,4194368 2 LET @3=4194304,16448,16384,64,0 3 DOUT w8
4 LET A=@7; LET I=7
5 LET J=I-1; LET @I=@J; LET I=J 6 IF I>0 THEN GOTO 5
7 LET @0=A; DELAY 500
8 GOTO 3

Solution notes:
Lines 1 and 2 store the colors for 8 RGB combinations. Line 3 sends the values to a string. Then, line 4 stores the value of the last element of the array in variable A. Lines 5 and 6 shift all values to the element of the array 1 higher. Line 7 returns the stored value from the last element to the beginning of the array and waits for the required time.

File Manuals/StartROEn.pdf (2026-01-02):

## How to get started with Tiny BASIC

For complete beginners, the first steps can sometimes be very difficult. To help you get started, here are some examples and tips for getting started with the TinyBasRO microcomputer.

Command or program line

Computers oriented to various versions of the BASIC language usually have a language interpreter running after startup, which simultaneously performs the tasks of an "operating system", a command line and a language translator. It is similar with TinyBasRO. After startup, the computer waits for a command (or several commands) to be executed.
The user can decide whether to directly give the computer the command "to perform a certain action immediately", or to "make a list" of what the computer will do when the user instructs it to start the program.
Both modes (direct command and program writing) work with commands that the computer understands. There are 28 of them in total and you will find them described in detail in the TinyBasLang manual and at the end of it there is a summary table with an overview of the commands.
Tiny BASIC language commands are not entered into the TinyBasRO computer by typing them out one by one using individual characters. The command is passed to the computer by pressing the left Ctrl key and then simultaneously pressing the key according to the table at the end of the TinyBasLang manual.
A typical first example in programming textbooks is a task that forces the computer to say hello. With TinyBasRO, we can achieve this in 2 ways:
1) Enter the command to print the greeting directly
PRINT "Hello"
and then press Enter. The PRINT command is entered as Ctrl+P and then the text is typed between quotes. The computer prints the desired greeting on the next line. The disadvantage is that you have to do this every time you want the computer to say hello.
2) The second option is to write the greeting as a program and then run it. You can imagine that the computer is a servant waiting with a notebook 128 lines long. The computer has lines in the notebook numbered 0 to 127. On each line it can write down the command you enter. After you dictate your commands to it, you can tell it to "now do this according to the list". Some lines may be empty, others may have up to 3 commands per line.
In our case, we can enter into the computer, for example:
1 PRINT "Hello"
After pressing Enter, nothing seems to happen. But the computer has saved our command in its notebook on line 1. And it will wait for more commands. If we now enter the RUN command (Ctrl+R) and press Enter, the computer will start performing tasks in the notebook. On line 1, it will find the command to execute. The result will be the same output as in point 1). The difference is that now we can call up the greeting using the RUN command whenever we want.

More commands per line

Since the microcomputer has a 32-character command line, it would be a shame not to use it. It can write up to 3 commands per line, even with parameters separated by a ; character. You are limited to only 32 characters. You can try writing on one line:
INPUT A,B ; PRINT "Area: " , A*B
And try what it does after you run it with Enter. If you didn't make a mistake in any character while entering the commands, you have a simple tool for calculating the area of a rectangle.
Ver. 1 | 1

You can take advantage of this if you need to write a specific character somewhere on the display screen. You can use a combination of commands
CURSOR 157 ; PUTCH 143
The specified parameter values for commands are printed in a solid square in the middle of the screen.

How a computer processes program lines

If you decide to create a program that the computer will later execute, you can start "dictating" to it on the lines of its notebook what it will do. You can always write on any line from 0 to 127. When you have completed the program, you run it with the RUN command.
The computer will start to go through the individual lines starting from the number 0 and execute the commands it finds on them. It will skip an empty line and move to the next line 1 higher. When it reaches line 127 and should go to the non-existent line 128, it will stop executing the program. Try the following program:
1 INPUT A
5 PRINT "Volume: " , A*A*A
And you have a simple program to calculate the volume of a cube. Try running it.
You can also terminate the program execution at any line using the END command. Add the following line to the program:
3 END
Now, after starting, the computer will prompt you to enter the value A, but it will no longer calculate the volume of the cube. This is because on line 3 it encountered the END command and will not go to line 5.

As a piece of advice, you can take the recommendation for special use of line 0. It is a good idea to learn to write a REM command on line 0 and add a short description of what the program does. After a while, you may not remember what you wanted to create with the program, and a note at the beginning of the program can refresh your memory.

Creating a program - an infinite and counted loop

Computers make their work easier by telling them what to repeat and not having to prescribe each step individually. If we wanted to print out even numbers, we wouldn't prescribe:
1 PRINT 2
2 PRINT 4
3 PRINT 6
…
We will let the computer count by 2 (that's what a computer is for, after all) and we will write the values on lines below each other. For example, like this:
1 LET A=0
2 LET A=A+2 ; PRINT A ; PUTCH 10
3 GOTO 2
The program starts printing even numbers at high speed after it is run. On the first line, we set the value of A to 0. The second line increases the value of A by 2, prints it, and uses the PUTCH command to move the cursor to the next line. Because the GOTO command on line 3 returns the program to line 2 again, an infinite loop has been created that keeps the program running until you turn off or reset the computer. The program can also be interrupted by typing the END command on the keyboard.

If you want to print only a limited number of even numbers (e.g. up to 20), modify line 3 to the new version:
3 IF A<20 THEN GOTO 2
Now when you start the computer, it will print only even numbers up to 20. The conditional IF statement evaluates the condition and returns the program to line 2 only for numbers less than 20. And if you did not delete line 5 from the previous example, it will print as an extra bonus the volume of a cube with sides of 20. You can simply delete line 5 by typing a blank line 5:
5

Statements that are repeated multiple times in a row are usually referred to as a program loop. The IF statement can be entered at the beginning of a loop – for example:
5 IF condition THEN GOTO 21
…
loop statements
…
20 GOTO 5
at the end of the loop, as was shown in the example with the list of even numbers. At first glance, it may seem that it does not matter where the evaluation of the condition is placed. In practice, this often leads to the same program behavior. The main difference, however, is that a loop with an evaluation statement at the end must always be executed at least once. If the test is at the beginning and the condition is met when the loop is first entered, the loop does not have to be executed even once.
Using the IF/THEN and GOTO statements, even in such a simple language, it is possible to create program constructs for which higher-level languages have special statements.

If you need to perform the same operations repeatedly with different parameters during a program, you can use a so-called subroutine. As an example of a subroutine, we can demonstrate something that, when called, will cause the speaker to beep several times according to the value in variable A. 40 BEEP 1000,200 ; DELAY 200
41 LET A=A-1; IF A>0 THEN GOTO 40
42 RETURN
In the program, I can now insert the line: whenever I need to signal several beeps with sound:
23 LET A=5 ; GOSUB 40
On the given line, I set the number of times to beep in variable A and then call the subroutine on line 40. It will make the appropriate number of beeps and using the RETURN command on line 42, the program will return to the line 1 number higher than where it was called from. In our case, the program would continue on line 24.

Where the program is stored (FILE and DISK commands)

The microcomputer stores the entered program in its serial EEPROM memory. Since one notebook is not enough for a good servant, our computer also has the possibility of equipping itself with multiple notebooks. It is clear that a program for taking care of the garden is different from a program for cleaning the house or maintaining a car.
Depending on the type of installed memory, 1 to 16 programs can be stored in it. The types of memories and the number of programs are summarized in the table in the TinBasHW manual. You can switch between programs using the FILE command. For example:
FILE 3
switches to the file with program 3 (gives our servant notebook number 3 in his hand). This program (notebook in his hand) will remain current until a new FILE command. After the computer starts, program 0 is default. If you are not sure which program is currently switched, enter the FILE command without a parameter and the computer will answer you with its number.
To make it not so simple, our servant can have 2 bookcases and each of them has more notebooks. It is possible to use 2 serial EEPROM memories. In order to distinguish between them, one is marked "h" (like a hard disk) and is firmly soldered to the board. The other is marked "f" (like a flash or floppy disk) and can be mounted via I2C connector. External memory can be connected only when turned off!
Switching between EEPROM memories is done with the DISK command – for example:
DISK f
Again, if you are unsure, you can enter the command without any parameters and the computer will tell you which disk is active. After booting, it is always disk h.

Interface with the outside world – warning light

To try working with outputs and simple control of external peripherals, you can try connecting two red LEDs to digital outputs D1 and D2 via resistors according to the following diagram:


Let's load a simple program into memory:
1 DOUT 1,1; DOUT 0,2
2 BEEP 2000,100; BEEP 800,200; DELAY 200 3 DOUT 0,1; DOUT 1,2
4 BEEP 2000,100; BEEP 800,200; DELAY 200
5 GOTO 1

This will give us a simple warning device for a railway crossing with an audible signal. On lines 1 and 3 we always turn on one LED (and turn off the other). Lines 2 and 4 are the same and make an audible signal and a short delay. Line 5 then loops the program.

Expander

If you have an expansion board with a PCF8575 expander available, you can control a larger number of LEDs. This allows you to create, for example, a "running arrow" or other lighting effect. Connect the required number of LEDs (max. 16 pcs) to the expander outputs, always according to the picture:

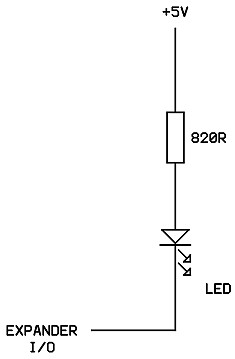
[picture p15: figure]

You can turn on the LEDs you want to light up with the command (for 8 LEDs):
I2CW b11110100
The binary digits in the parameter determine what will be lit – position 0, and what will be off – 1. If you want a running light, you can create it for 8 LEDs like this:
1 LET A=-2
2 I2CW A ; DELAY 200
3 LET A=A*2+1
4 IF A < -300 THEN LET A=-2
5 GOTO 2
This is where the magic of computer mathematics comes into play. The number -2 is made up of all 1s and one 0. The operation A*2+1 then moves this 0 up 1 position.

WS2812 string control

The TinyBasRO microcomputer has an extended number of digital inputs and outputs compared to the TinyBasRV computer. In addition, it allows you to control a string of up to 100 WS2812 LEDs via output D1. For example, the command
DOUT w16
will send the values stored in the @ field to 16 connected LEDs.

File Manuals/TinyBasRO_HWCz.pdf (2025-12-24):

## Hardwarové vybavení TinyBasRO ver. 1.0

Parametry:
Napájecí napětí: | 5 V
Odběr proudu: | 200 mA max
Počet vstupů a výstupů: | 8 x digitální + 1 analogový vstup
Rozšiřující moduly: | expander s PCF8575, modul s I2C pamětí

Mikropočítač TinyBasRO je jednoduché zapojení, které začínajícímu elektrotechnikovi umožňuje postavit si vlastní snadno ovladatelný a programovatelný počítač. Pro jeho používání k němu stačí připojit zdroj +5V, I2C klávesnici CardKB od firmy M5STACK a OLED displej 128x128. Všechny součástky počítače se nacházejí na jedné straně dvouvrstvého plošného spoje o velikosti 34 x 47 mm. Kompletní schéma zapojení je na následujícím obrázku.

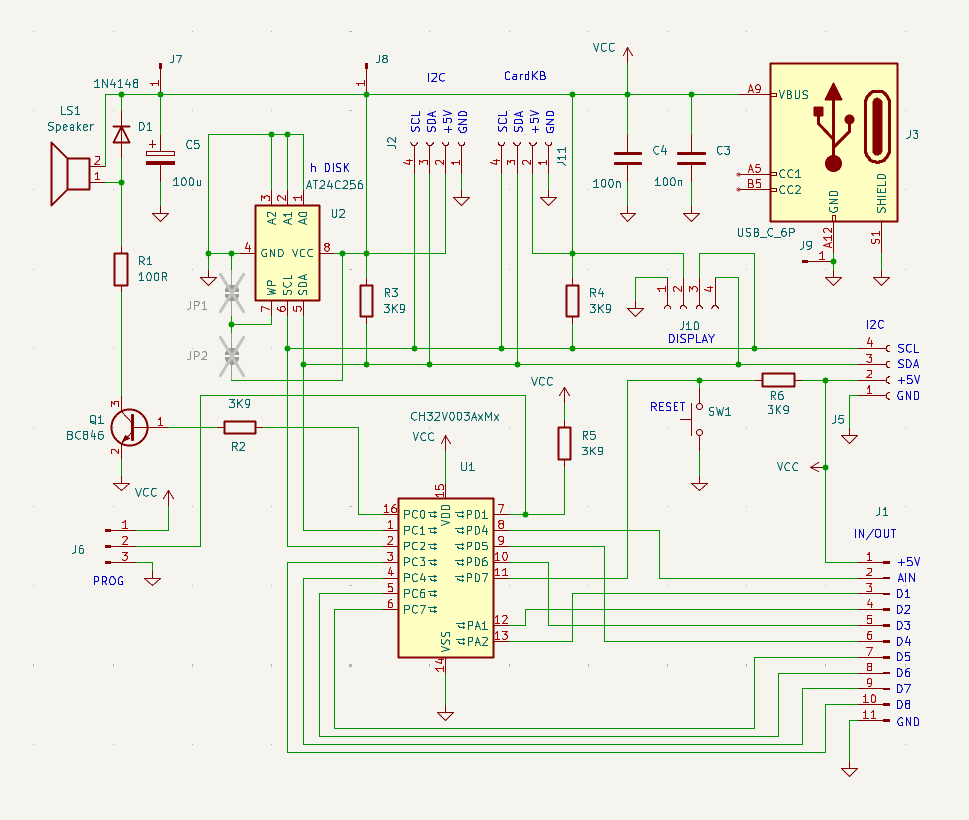
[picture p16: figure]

Rev A | 1

### Jádro počítače

Součástky nezbytné pro funkci počítače jsou integrované obvody U1 a U2, rezistory R3 a R4, kondenzátory C3 až C5 a konektory J10 a J11. Toto představuje minimum součástek, které je nutné na desku plošného spoje osadit.
Řídicí 32bitový RISC-V procesor U1 přijímá povely z klávesnice zapojené do konektoru J11. Rezistory R3 a R4 udržují klidovou úroveň log. 1 na sběrnici I2C pro klávesnici a displej. Výstupem pro uživatele je informace zobrazená na OLED displeji přes konektor J10.
Procesor má data s programem uložena v EEPROM sériové paměti U2. Komunikace s ní probíhá po sběrnici I2C. Paměť U2 označovaná jako „DISK h“ má všechny adresové vstupy A0 až A2 připojené na log. 0 a má tak nastavenou adresu 0. Paměť je stejně jako procesor v provedení SMD a je trvale připájena na desce. Cínové propojky JP1 a JP2 určují, zda je paměť U2 v režimu „Read only“ při spojení JP2, nebo zda je možné měnit její obsah (propojka JP1).
Zbývající součástky tj. kondenzátory C3 až C5 slouží k blokování napájecího napětí.

Napájení počítače
Počítač vyžaduje stabilizované napájecí napětí +5V. To je možné přivést přímo na desku plošného spoje pomocí vodičů do děr vedle konektoru pro OLED (J8 je +, J9 je GND). Nabízí se také možnost napájet počítač z běžného síťového adaptéru s USB konektorem typu C. Na desce jsou připraveny kontaktní plochy pro připájení 6vývodového napájecího konektoru typu C.

### Volitelné části:

Zvukový výstup
Aby mohl počítač vydávat různé tóny, má přichystánu zvukovou část. Základem je miniaturní reproduktor LS1 buzený přes tranzistor Q1. Rezistor R1 omezuje proud tekoucí přes reproduktor a R2 určuje proud do báze tranzistoru. Dioda D1 je ochranná a slouží pro potlačení napěťových špiček, které by vznikaly v okamžiku vypnutí proudu přes reproduktor.

Obvod RESET
Pokud by se stalo, že počítač přestal reagovat na povely uživatele, je možné jej uvést tlačítkem RESET do úvodního stavu. Rezistor R6 udržuje klidovou úroveň log. 1 na resetovacím vstupu procesoru. Po stisknutí tlačítka SW1 je úroveň změněna na log. 0 a dojde k RESETu počítače.

Rozšíření sběrnice I2C
Počítač má poměrně málo vstupů a výstupů pro případ, kdyby uživatel chtěl ovládat rozsáhlejší periferie. V tomto případě lze využít sběrnici I2C, přes kterou komunikuje s pamětí a displejem. Osadíte-li 4vývodové konektory na pozice J2 a J5, můžete pak počítač rozšířit o modul expanderu nebo další paměť EEPROM.
Jazyk Tiny Basic tohoto počítače nabízí možnost přímo ovládat připojenou desku s expanderem PCF8575. Tím se počet digitálních vstupů/výstupů rozšíří o 16. Při připojování externích obvodů na I2C sběrnici buďte opatrní a provádějte to vždy ve vypnutém stavu. Sběrnice přenáší data mezi procesorem a pamětmi a rušivý signál může poškodit zapsaný program.
Rozšíření paměti pro uložení více programů nebo pro zajištění přenosu programů mezi několika TinyBasRO počítači lze zařídit připojením externího modulu se sériovou I2C pamětí, jaké se nabízejí např. v obchodech s díly pro Arduino apod. Připojovaný modul musí mít nastavenu adresu 1 – tj. A0 = 1, A1 a A2 = 0.

Vstupy a výstupy
Na konektoru J1 může mít uživatel několik vstupů a výstupů pro ovládání různých přístrojů. Jeden vstup AIN je analogový a umožňuje měřit napětí 0 až 5V. Další vstupy/výstupy jsou digitální a je jich celkem 8. Bude-li konkrétní vývod vstupní nebo výstupní se určí pomocí programu. Zvláštní postavení má digitální výstup D1, přes který lze ovládat řetězec programovatelných barevných LED diod typu WS2812.

Signály na konektoru J1:
Vývod: | Použití:
+V | Napájecí napětí +5V
AIN | Analogový vstup 0 až 5 V
D1 | Digitální vstup/výstup, ovládání řetězce LED WS2812 pomocí příkazu „DOUT w“
D2 | Digitální vstup/výstup
D3 | Digitální vstup/výstup
D4 | Digitální vstup/výstup
D5 | Digitální vstup/výstup
D6 | Digitální vstup/výstup
D7 | Digitální vstup/výstup
D8 | Digitální vstup/výstup
GND | Společný vodič - zem

Poznámka: Digitální vstupy mohou mít definovanou klidovou úroveň. Lze u nich nastavit tzv. „Pull-up“ nebo „Pull-down“ rezistor na vstupu. Příkazem DOUT se daný vývod nastavuje do režimu výstup a současně se posílá logická úroveň na daný výstup. Při změně směru výstupu na vstup pomocí příkazu DINP se vývod změní na vstupní. Poslední výstupní hodnota, která byla zapsána na daném výstupu pak určuje klidovou hodnotu nezapojeného vstupu.
Např. Příkaz DOUT 1,3 způsobí, že následující příkaz DINP A,3 přečte do proměnné A u nezapojeného vstupu hodnotu 1. Po příkazu DOUT 0,3 by následující příkaz DINP A,3 přečetl do proměnné A u nezapojeného vstupu hodnotu 0.

### Sestavení počítače

Všechny součástky počítače jsou osazeny na jedné straně oboustranného plošného spoje. Na desku je nutné umístit pouze součástky označené výše jako jádro počítače a zajistit jeho napájení. Další součástky jsou již volitelné.

### Mechanická sestava počítače

Pokud použijete OLED displej 128x128 bodů s řadičem SH1107 se 4 vývody pro I2C sběrnici, jsou upevňovací otvory na desce displeje na stejných místech, jako montážní otvory počítače TinyBasRO. Pro spojení obou desek postačí použít 4 ks distančních sloupků délky 11 mm. U popisovaného vzorku byly použity pro spojení 4 ks šestihranných sloupků se závitem M2 a k tomu 4 šrouby a matice M2.

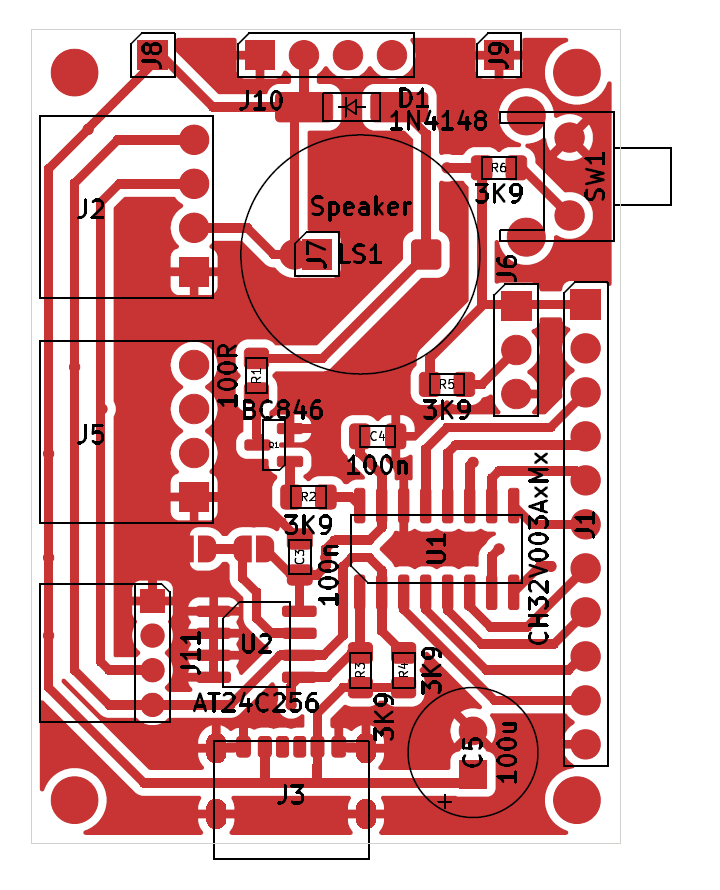
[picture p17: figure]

### Doporučený postup montáže

Při stavbě mikropočítače je vhodné začít jako první připájením procesoru U1 a kondenzátoru C4 na desku. Pak je možno pomocí programu WCH-LinkUtility naprogramovat Tiny BASIC do paměti počítače. K zapsání programu do paměti je nutný programátor WCHLinkE (Pozor! Programátor bez „E“ nebude fungovat!). Program WCH-LinkUtility lze najít na stránkách výrobce procesorů CH32V003 a je volně ke stažení. V okně programu stačí obvykle zvolit správný typ procesoru a zadat HEX soubor s daty pro naprogramování.

Program WCH-LinkUtility je také součástí programovacího prostředí MounRiver Studio. Je ale dobře ukrytý. Ve verzi 2.10 jej najdete ve složce:

c:\MounRiver\MounRiver_Studio2\resources\app\resources\win32\components\WCH\Others\ SWDTool\default\WCH-LinkUtility.exe

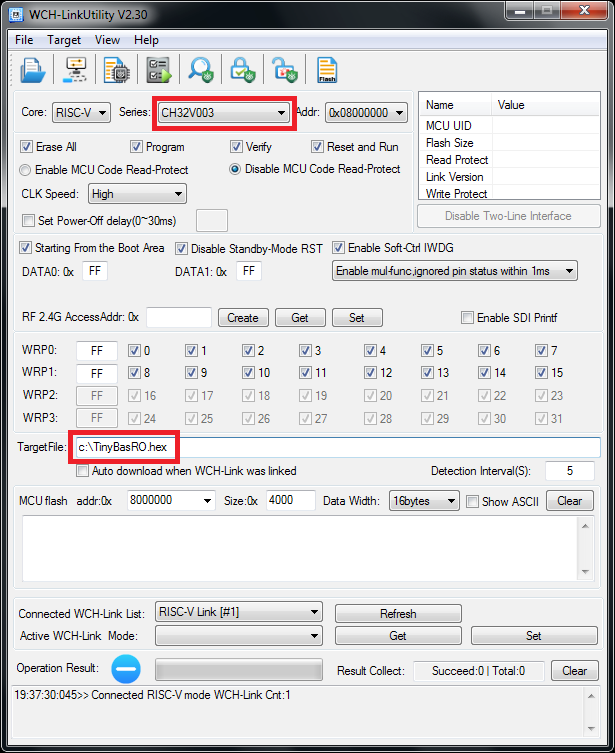
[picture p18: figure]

Na účely naprogramování je na desce připraven konektor J6. Pokud neplánujete častější přepisování nových verzí Tiny BASIC, není potřeba konektor osazovat. Programátor WCHLinkE je možné připojit 3 vodiči přímo do děr pro J6 na desce. Propojí se signály GND, SDIO a +5V na programátoru s deskou. Zvolte soubor TinyBasRO.hex. Pak stačí zadat Target – Program.

V případě potřeby je možné obsah procesoru v budoucnu přehrát novou verzí.

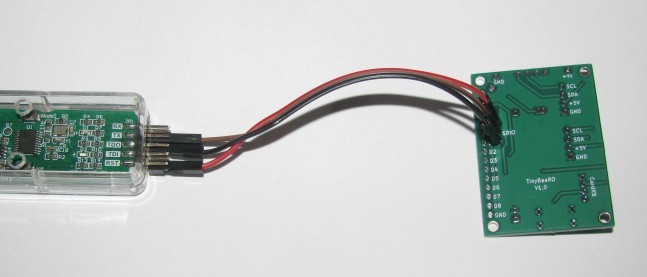
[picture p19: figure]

Po úspěšném naprogramování procesoru můžeme přistoupit k osazení dalších součástek. Jak bylo zmíněno výše, je nutné osadit jádro počítače (U1, U2, C3 až C5, R3 a R4, J10, J11). Zbývající části počítače a jejich součástky jsou volitelné, nejsou nezbytné pro základní fungování přístroje.
U kompletního počítače je ještě potřeba nastavit povolení zápisu do paměti zkratováním propojky JP1 pomocí kapky cínu.

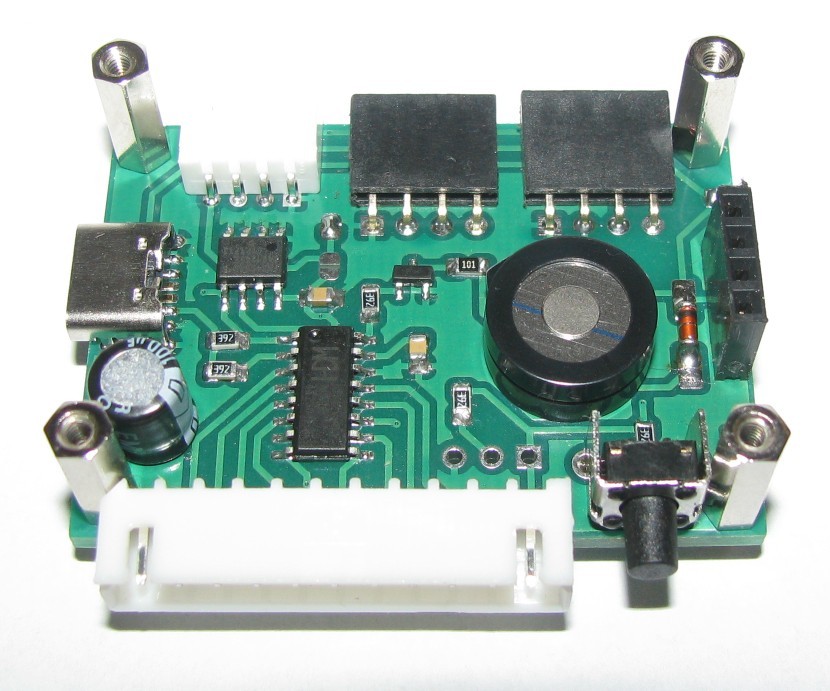
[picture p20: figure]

### Seznam součástek

Pozice | Typ | Poznámka
U1 | CH32V003A4M6 | 32bitový RISC-V
U2 | EEPROM I2C – viz dále | SOIC8
Q1 | BC846 | SOT23 nebo podobný NPN
D1 | 4148 | Nebo podobný typ
R1 | 100R | 0805
R2 až R6 | 3K9 | 0805
C3,C4 | 100n | Keramika 0805

C5 | 100u/16 | Elektrolyt (vhodný je nižší typ)
LS1 | Miniaturní reproduktor 16Ω | Průměr 12 mm
SW1 | Mikrospínač boční | Např. TS6606-8.0-180
J1 | JST XH 2,54 mm 11 pin | Samec do pl. spoje, nebo kolíková lišta
J2, J5 | Dutinková lišta 4 vývody | Do pl. spoje 90°
J3 | USB C 6 vývodů | Např. USB4125
J10 | Dutinková lišta 4 vývody | Do pl. spoje přímá
J11 | Grove 4 pin 2 mm | Do pl. Spoje 90° (pro CardKB)
- | Displej OLED 128x128 | Řadič SH1107 pro I2C
- | Klávesnice CardKB | Výrobce M5STACK

### Typy pamětí a počet programů

Na desku počítače je možné zapojit různé sériové I2C EEPROM paměti podle aktuální dostupnosti a požadavků uživatele. Při volbě paměti zkontrolujte, zda výrobce paměti povoluje napájecí napětí 5V a rychlost sběrnice 400 kHz. Různí výrobci označují svoje typové řady různě, např. 24LC256, 24AA256, M24512 apod. V tabulce je proto uvedeno základní číslicové značení, které je obvykle doplněno o další kombinace písmen.

Typ | Velikost | Počet programů | Označení programů
2432 | 32 Kbit / 4 KByte | 1 | 0
2464 | 64 Kbit / 8 KByte | 2 | 0,1
24128 | 128 Kbit / 16 KByte | 4 | 0,1,2,3
24256 | 256 Kbit / 32 KByte | 8 | 0,1,2,3,4,5,6,7
24512 | 512 Kbit / 64 KByte | 16 | 0,1,2,3,4,5,6,7,8,9,10,11,12,13,14,15

Sloupec „Počet programů“ udává, kolik samostatných programů jazyka Tiny BASIC je možné do paměti uložit. Poslední sloupec pak odkazuje na číselné značení jednotlivých programů zapsaných v paměti.
V případě, že máte k dispozici programátor sériových I2C EEPROM pamětí, lze využít vyvedené sběrnice I2C na konektoru J5. Propojíte-li správně 4 vodiče z konektoru do patice programátoru EEPROM pamětí, můžete nahrát do EEPROM obsah souboru ExampleBasRO.hex, který je ve složce EEPROM_examples. Soubor má velikost 32 KByte, takže je vhodný pro paměti 24256 a 24512. Podaří-li se vám to, získáte 8 ukázkových programů jazyka Tiny BASIC. Příklady můžete zapsat i do externí paměti. Bližší informace k programům najdete v návodu TinyBasExamples. Pokud budete na sběrnici I2C připojovat externí modul s EEPROM pamětí, nezapomeňte, že je potřeba nastavit adresový bit A0 na logickou 1!

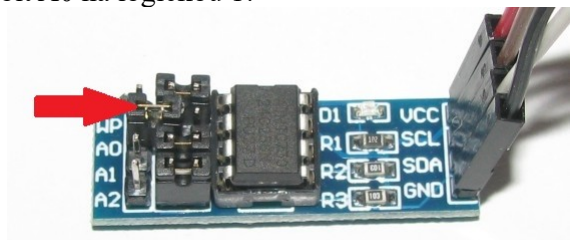
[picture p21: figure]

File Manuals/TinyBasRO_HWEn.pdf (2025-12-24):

## Hardware description TinyBasRO ver. 1.0

Parameters:
Supply voltage: | 5 V
Current consumption: | 200 mA max
Number of inputs and outputs: | 8 x digital + 1 analog input
Expansion modules: | expander with PCF8575, module with I2C memory

The TinyBasRO microcomputer is a simple circuit that allows a novice electrician to build their own easy-to-use and programmable computer. To use it, you just need to connect a +5V power supply, an I2C CardKB keyboard from M5STACK, and a 128x128 OLED display.
All computer components are located on one side of a two-layer printed circuit board measuring 34 x 47 mm. The complete circuit diagram is shown in the following figure.


Rev A | 1

### Computer core

The components necessary for the computer to function are integrated circuits U1 and U2, resistors R3 and R4, capacitors C3 to C5 and connectors J10 and J11. This represents the minimum number of components that must be mounted on the printed circuit board.
The control 32-bit RISC-V processor U1 receives commands from the keyboard connected to connector J11. Resistors R3 and R4 maintain a level of log. 1 on the I2C bus for the keyboard and display. The output for the user is information displayed on the OLED display via connector J10. The processor has data with the program stored in the EEPROM of the serial memory U2. Communication with it takes place via the I2C bus. The memory U2, designated as "DISK h", has all address inputs A0 to A2 connected to log. 0 and thus has the address set to 0. The SMD memory and the processor are permanently soldered to the board. Tin jumpers JP1 and JP2 determine whether the U2 memory is in "Read only" mode when JP2 is connected, or whether its contents can be changed (jumper JP1).
The remaining components, i.e. capacitors C3 to C5, are used to block the supply voltage.

Computer power supply
The computer requires a stabilized +5V power supply. This can be connected directly to the printed circuit board using wires in the holes next to the OLED connector (J8 is +, J9 is GND). It is also possible to power the computer from a regular AC adapter with a USB Type-C connector. The board has contact areas for soldering a 6-pin Type-C power connector.

### Optional parts:

Audio output
To emit various tones computers has a sound section. The basis is a miniature speaker LS1 driven by a transistor Q1. Resistor R1 limits the current flowing through the speaker and R2 determines the current to the base of the transistor. Diode D1 is protective and serves to suppress voltage peaks that would arise when the current through the speaker is turned off.

RESET
If the computer stops responding to user commands, it can be reset to its initial state by pressing the RESET button. Resistor R6 maintains a quiescent level of log. 1 on the processor reset input. After pressing the SW1 button, the level is changed to log. 0 and the computer is RESET.

I2C bus expansion
The computer has relatively few inputs and outputs in case the user wants to control larger peripherals. In this case, the I2C bus can be used, through which it communicates with the memory and display. If you install 4-pin connectors in positions J2 and J5, you can then expand the computer with an expander module or additional EEPROM memory.
The Tiny Basic language of this computer offers the possibility of directly controlling the connected PCF8575 expander board. This increases the number of digital inputs/outputs by 16. Be careful when connecting external circuits to the I2C bus and always do it in the off state. The bus transfers data between the processor and the memories and an interfering signal can damage the written program.
Memory expansion for storing multiple programs or for transferring programs between multiple TinyBasRO computers can be arranged by connecting an external module with serial I2C memory, such as those offered, for example, in Arduino parts stores, etc. The connected module must have address 1 set - i.e. A0 = 1, A1 and A2 = 0.

Inputs and outputs
On the J1 connector, the user can have several inputs and outputs for controlling various devices. One input AIN is analog and allows measuring voltages from 0 to 5V. Other inputs/outputs are digital and there are 8 of them in total. Whether a specific pin is an input or output is determined by the program. A special position is given to the digital output D1. Through D1 a string of programmable color LEDs of the WS2812 type can be controlled.

Signals on connector J1:
Pin: | Use:
+V | Supply voltage +5V
AIN | Analog input 0 to 5 V
D1 | Digital input/output, controlling WS2812 LED string using the command "DOUT w"
D2 | Digital input/output
D3 | Digital input/output
D4 | Digital input/output
D5 | Digital input/output
D6 | Digital input/output
D7 | Digital input/output
D8 | Digital input/output
GND | Common potential - ground

Note: Digital inputs can have a defined idle level. A so-called “Pull-up” or “Pull-down” resistor can be set on the input. The DOUT command sets the given pin to output mode and simultaneously sends a logic level to the given output. When changing the direction of the output to input using the DINP command, the pin changes to input. The last output value that was written to the given output then determines the idle value of the unconnected input.
For example, the DOUT 1,3 command causes the following DINP A,3 command to read the value 1 into the variable A of the unconnected input. After the DOUT 0,3 command, the following DINP A,3 command would read the value 0 into the variable A of the unconnected input.

### Building a computer

All computer components are mounted on one side of a double-sided printed circuit board. Only the components marked above as the core of the computer need to be placed on the board and its power supply must be provided. Other components are optional.

### Mechanical assembly of the computer

If you use a 128x128 OLED display with a SH1107 controller with 4 pins for the I2C bus, the mounting holes on the display board are in the same places as the mounting holes of the TinyBasRO computer. To connect the two boards, it is enough to use 4 pcs of 11 mm long spacers. In the described sample, 4 pcs of hexagonal posts with M2 thread were used for the connection, along with 4 M2 screws and nuts..


### Recommended assembly procedure

When building a microcomputer, it is advisable to start by soldering the U1 processor and the C4 capacitor to the board. Then, you can use the WCH-LinkUtility program to write Tiny BASIC into the computer's memory. To write the program into the memory, you need the WCHLinkE programmer (Caution! A programmer without an "E" will not work!). The WCH-LinkUtility program can be found on the website of the CH32V003 processor manufacturer and is freely downloadable. In the program window, you usually just need to select the correct processor type and enter the HEX file with the programming data.
The WCH-LinkUtility program is also part of the MounRiver Studio programming environment. However, it is well hidden. In version 2.10, you can find it in the folder:

c:\MounRiver\MounRiver_Studio2\resources\app\resources\win32\components\WCH\Others\ SWDTool\default\WCH-LinkUtility.exe


For programming purposes, the J6 connector is prepared on the board. If you do not plan to rewrite new versions of Tiny BASIC frequently, there is no need to install the connector. The WCHLinkE programmer can be connected with 3 wires directly to the holes for J6 on the board. The GND, SDIO and +5V signals on the programmer are connected to the board. Select the TinyBasRO.hex file. Then just enter Target – Program.
If necessary, the processor content can be overwritten with a new version in the future.


After successfully programming the processor, we can proceed to installing other components. As mentioned above, it is necessary to install the computer core (U1, U2, C3 to C5, R3 and R4, J10, J11). The remaining parts of the computer and their components are optional, they are not necessary for the basic functioning of the device. For a complete computer, it is still necessary to set the permission for writing to the memory by shorting the jumper JP1 with a drop of tin.

### Parts list


Position | Type | Note
U1 | CH32V003A4M6 | 32bit RISC-V SOIC16
U2 | EEPROM I2C – see next | SOIC8
Q1 | BC846 | SOT23 or similar NPN
D1 | 4148 | Or a similar type
R1 | 100R | 0805
R2 to R6 | 3K9 | 0805
C3,C4 | 100n | Ceramic 0805

C5 | 100u/16 | Electrolyte (lower type is suitable)
LS1 | Miniature speaker 16Ω | Diameter 12 mm
SW1 | Side microswitch | E.g. TS6606-8.0-180
J1 | JST XH 2,54 mm 11 pin | Male to pcb or pin header
J2, J5 | Pin header 4 terminals | To pcb 90° female
J3 | USB C 6 pins | E.g. USB4125
J10 | Pin header 4 terminals | To pcb upright
J11 | Grove 4 pin 2 mm | To pcb 90° (for CardKB)
- | Display OLED 128x128 | Driver SH1107 for I2C
- | Keyboard CardKB | Producer M5STACK

### Memory types and number of programs

It is possible to connect various serial I2C EEPROM memories to the computer board according to current availability and user requirements. When choosing a memory, check whether the memory manufacturer allows a supply voltage of 5V and a bus speed of 400 kHz. Different manufacturers mark their type series differently, e.g. 24LC256, 24AA256, M24512, etc. The table therefore shows the basic numerical marking, which is usually supplemented by other letter combinations.

Type | Size | Number of programs | Program designations
2432 | 32 Kbit / 4 KByte | 1 | 0
2464 | 64 Kbit / 8 KByte | 2 | 0,1
24128 | 128 Kbit / 16 KByte | 4 | 0,1,2,3
24256 | 256 Kbit / 32 KByte | 8 | 0,1,2,3,4,5,6,7
24512 | 512 Kbit / 64 KByte | 16 | 0,1,2,3,4,5,6,7,8,9,10,11,12,13,14,15

The "Number of programs" column indicates how many separate Tiny BASIC programs can be stored in memory. The last column then refers to the numerical marking of individual programs written in memory.
If you have a serial I2C EEPROM programmer, you can use the I2C bus on connector J5. If you correctly connect the 4 wires from the connector to the EEPROM programmer socket, you can load the contents of the ExampleBasRO.hex file, which is in the EEPROM_examples folder, into the EEPROM. The file is 32 KByte in size, so it is suitable for 24256 and 24512 memories. If you succeed, you will get 8 sample Tiny BASIC programs. You can also write the examples to external memory. For more information about the programs, see the TinyBasExamples manual.
If you are going to connect an external module with EEPROM memory to the I2C bus, do not forget that you need to set the address bit A0 to logical 1!

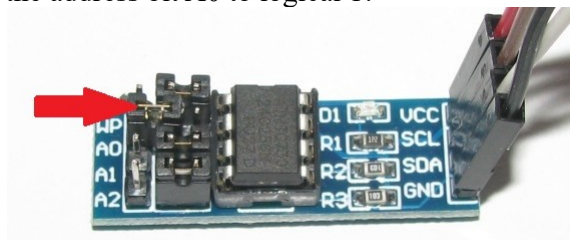
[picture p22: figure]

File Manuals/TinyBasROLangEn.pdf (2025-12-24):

# Tiny BASIC

# for

# TinyBasRO

Rev A | 1

## Software ver. 1.0

The TinyBasRO microcomputer contains a Tiny BASIC language interpreter with some limitations and, conversely, with a number of improvements. The interpreter provides the user interface (communication with the user) and also execution of the stored program.
After turning on the microcomputer, the message "Tiny BASIC x.x" appears on the OLED display indicating the current version of the interpreter. This document should have the same version as reported by the computer after starting. The microcomputer simultaneously tests the available hardware and possibly reports that the DISK f and the PCF8575 expander on the I2C bus are not available and that some functions are limited. To connect the "f" disk or expander, follow the instructions "What to do when..." at the end of this manual.

When interacting with the user, the microcomputer expects a command to be entered at the prompt in two possible formats:
STATEMENT (; STATEMENT) (; STATEMENT)
or
NUM STATEMENT (; STATEMENT) (; STATEMENT)
where STATEMENT represents a Tiny BASIC command that can be executed. If a line begins with a statement, it is executed immediately. If a line begins with a number NUM (in the range 0 to 127), the statement is not executed, but is stored in memory and becomes one of the lines of the program waiting to be executed.

Example:
PRINT 5+46
It immediately prints the result on the line 51
On the contrary
26 PRINT 5+46
does nothing. This line is stored at line number 26 in the program memory in the current "file" (see the FILE command). It remains inactively written in memory until the program is run. Only after the program is run is the command executed at the moment when line number 26 is processed.

There can be one, two, or three semicolon-separated statements on a line, which are executed sequentially from the left. Some statements, such as REM, GOTO, IF, cause the next statement (or statements) on the line to not be executed.

### Writing a program

The program or interpreter commands are entered using the keyboard on the line at the blinking cursor. Printable characters appear on the screen immediately after entry. If you need to enter more than one "space" character, you can use the Tab key, which expands to 4 spaces. Any errors can be undone with the "Back Space" key. Moving on the line using the arrows is not possible, you can only delete characters one by one.
You can delete a misspelled line by entering a blank line. At the beginning of the line, type only the number of the deleted line and then press Enter. The misspelled line is corrected automatically after you type a new correct version of the line.
Tiny BASIC language commands are not written out character by character, but are entered by pressing 2 keys simultaneously. Commands are entered by pressing one key and previously pressed the "Fn" key. The list of allowed commands and their corresponding keys is in the summary table on the last page of this document.
Commands (STATEMENT) can be entered up to 3 at the same line. Most commands expect one or more parameters in a specific, precisely defined format after the command itself. The list of parameters and their meaning is given below in the description of individual commands and also in the table on the last page. The main parameters of the commands are:

STRING
is a text string enclosed in quotation marks. Any printable characters can be included within the string. A special case within a string is the combination of two characters - "\" (backslash) followed by the letters "n", "t" or "f" - e.g. "\n". These combinations cause:
n- line break
t - tab with cursor movement to positions divisible by 8 (i.e. 0,8,16)
f - clear the screen and return the cursor to the top left

VAR
indicates a variable in which numerical values are stored. Since a 32-bit computer is used, all variables are also 32-bit. The values stored in them can be in the range -2,147,483,648 to 2,147,483,647. The user has a total of 126 automatically predefined variables. These are divided into two groups. Either they have their own name and are indicated by uppercase letters of the English alphabet A to Z (26 variables in total).
Or they form an indexed array of 100 items. The array can be accessed using the "@" character, immediately followed by the index number of the item given by one or two digits, or a letter indicating the variable where the index value is stored.

Examples of allowed variable names: A, .. Q, .. Z
Examples of array element names: @0, .. @9, .. @10, .. @28, .. @99, @A .. @Z.

Direct indexing of an array by digits does not exceed the array size, because the interpreter processes only one or two digits. However, if a variable is used for indexing, its contents may exceed the size of the array. For example, if A contains the value 4786, then a reference to an array element @A will cause an error message and the program to terminate.

EXPR
represents a mathematical expression with a computable value. It can be a number, the content stored in a variable, or an algebraic expression for calculating a specific value. The usable forms of expressions are described in the mathematics of the language below.

NUM
a number entered directly using consecutive decimal digits. The second option is to enter the number in binary form. A binary number is indicated by the letter "b" followed closely by the digits 0 or 1.

### Mathematics of language

The language uses integer arithmetic, so it is not possible to enter numbers with fractional part. The range of a number can be from -2147483648 to 2147483647. Numbers outside this range will not be processed correctly.
Calculations process 32-bit numbers in the specified range. Addition, subtraction, multiplication and division operations can be used for calculations. The priority of operations (multiplication and division have priority over addition and subtraction) is respected. With the same priority level, expressions are processed from left to right.
Mathematics can be written formally:

EXPR = ( |+|-)TERM ((+|-) TERM)^
where TERM = FACT ((*|/) FACT)^
and FACT = VAR | NUM ...... see above.

Items in parentheses are optional. Options are separated by the character "|". Parentheses marked "^" can be repeated until the end of the line.
Examples of mathematical expressions (EXPR) that are allowed:
| -5 A/3 + @23 10 + A*15 - @G/42*R -114783648 – Q * R* S* T + 526 / C

Parentheses cannot be used in mathematics in the program. If we need to calculate, for example, the formula A=(B+C)/(D-E), it is necessary to divide the calculation into several steps - for example:

| LET F=B+C; LET G=D-E; LET A=F/G

### Commands

The same formal description was used when entering the parameters of individual commands as the description given above for the language mathematics. Items in parentheses are optional and brackets marked "^" can be repeated until the end of the line.

Command: PRINT
Parameters: (STRING | EXPR) (,(STRING | EXPR))^
Command function: Prints the data specified in the parameters to the screen from the current cursor position. STRING is printed in text form without leading and closing quotation marks. EXPR is printed as a number expressed by the given mathematical expression.

Examples:
PRINT 5+3 | prints the number 8 at the current screen position
PRINT "Result is " , B | prints according to the content of B e.g. Result is 115
PRINT A, "\n", B, "\n", C | will print the contents of variables A,B,C one after the other on
| the lines below them

Command: IF
Parameters: EXPR RelOp EXPR
Command function: This statement is closely related to the following THEN statement, which must immediately follow on the same line. They form a single, linked pair of statements, effectively representing a single double statement.

Command: THEN
Parameters: STATEMENT
Command function: Together with the IF statement, they create a decision condition that allows for conditional processing of another statement or branching of the program. The IF-THEN pair executes the STATEMENT statement in the THEN parameter only if the relational condition EXPR RelOp EXPR in the parameter of the IF statement is true.
RelOp is a comparison condition between two EXPR expressions. It can be of the form:
= | are both expressions the same?
< | is the first expression less than the second?
<> | are the expressions different?
<= | is the first expression less than or equal to the second?
> | is the first expression greater than the second?
>< | are the expressions different?
>= | is the first expression greater than or equal to the second?
& | is the bitwise logical conjunction of the expressions non-zero?
If the condition is true, the STATEMENT command is executed, otherwise, the command is not executed.
Attention! If the condition is false, the execution of the line after the THEN keyword is not continued and the program moves to the next line of the program. This property can be used when executing multiple commands simultaneously. If the condition is met, the execution of the line continues and since there can be up to 3 commands on a line, it is possible to execute or not execute up to 3 commands after evaluating one condition.
Examples:
IF A>5 THEN PRINT A | the content of A is only printed if it is greater than 5

IF A*5=100 THEN GOTO 35 | if the value in A is 20, the program jumps to line 35,
| otherwise it continues with the next line
IF C&b1000 THEN BEEP 1000,100 | if bit no. 3 in variable C is log. 1, a tone will sound
IF A=0 THEN LET A=1; PRINT B | if the value of A is zero, A changes to 1 and B is printed

Command: GOTO
Parameters: EXPR
Command function: This is a jump function that transfers the current position of the processed lines to the line whose number is given by the expression EXPR. The command is only meaningful in the processing mode of a running program. If the user enters it as a command in the command entry mode, nothing is done. The command parameter is a general expression. However, the programmer must ensure that the value of this expression does not exceed the range 0 to 127. If an attempt is made to "jump" outside the allowed line number, an error is reported and program execution stops.

Examples:
GOTO 23 | transfers program execution to line number 23
GOTO 10+I*5 | according to the value in variable I, the program jumps to a line in
| multiples of 5

Command: INPUT
Parameters: VAR (,VAR)^
Command function: Entering numerical values into individual variables. The programmer can choose as a parameter which values the user should enter and these are gradually stored in the given variable. The user is gradually prompted to enter a number. When entering, the name of the variable being filled is displayed. For an array type variable, the user is prompted to enter only "@" (the index is not given). Numbers can only be entered in decimal form.

Examples:
INPUT L,H | the user is prompted to enter values into variables L and then H
INPUT @20, @38 | the user will be asked twice to enter a value in @

Command: LET
Parameters: VAR = EXPR or @VAR = EXPR(,NUM)^
Command function: The assignment statement determines which EXPR value is inserted into the VAR variable.
The statement can also be used to simultaneously fill additional values into multiple array items. After entering a value into a specified array element, it is possible to enter numeric values separated by commas into subsequent elements. The number of values entered is limited only by the length of the line or by reaching the end of the array.

Examples:
LET I=52 | the value 52 is written to I
LET Q= 23*W-L/3 | the expression 23*W-L/3 is first calculated and the result is written to

Q variable
LET @23=4,12,8,63,47 array elements 23 to 27 are filled with the values entered sequentially

Command: GOSUB
Parameters: EXPR
Command function: Calling a subroutine, which can be on reserved program lines. This command is very similar to the GOTO command and does practically the same thing. In addition, however, the return value for the RETURN command is stored. The return value is the line number 1 greater than the line on which the GOSUB command is currently being processed. After executing the subroutine, the RETURN command returns the program to the line given by the return value. Within a subroutine, it is possible to call another subroutine and thus nest subroutines within each other. However, the maximum level is limited to 8 nested subroutines. An attempt to call the ninth subroutine from the eighth nested subroutine will cause an error message and the program to terminate.

Examples:
GOSUB 44 | the subroutine stored on line 44 will be called, after it is terminated
| with the RETURN command, it will continue on the next line

Command: RETURN
Parameters: ---
Command function: Terminate a subroutine. The statement takes the return value stored by the GOSUB command and places it in the pointer to the next line to be executed. Calling the RETURN statement without first calling the GOSUB statement (i.e., missing a return value) will cause an error to be reported and the program to terminate.

Examples:
RETURN | ends the subroutine and returns the program to the line following the
| GOSUB command

Command: CLEAR
Parameters: ---
Command function: Delete the current program. After executing this command, all lines of the program will be empty. If any program was written in the current file (see FILE command), it will be completely deleted.

Examples:
CLEAR | deletes the current program

Command: LIST
Parameters: (NUM)
Command function: Prints the current program in memory. The command can be given without a parameter. In this case, it prints the entire current program stored in the computer's memory. If a number is specified as a parameter, it prints only a specific line. The number can be any, but only the lowest 7 bits are valid (so-called modulo 128 arithmetic).

Examples:
LIST | prints the entire program on the screen
LIST 15 | prints line 15 of the program
LIST 130 | prints line 2 of the program

Command: RUN
Parameters: ---
Command function: Starts program execution. After starting, the program lines are executed sequentially from line 0. If there is no jump command (GOTO or GOSUB) on the given line, the line with a number 1 higher is executed after the current line is executed. Lines on which no command is stored are searched, but no action is performed on them. They represent only a minor delay in the program (the line must be read). For time-critical parts of the program, it is advisable not to leave lines unnecessarily empty. If the line pointer exceeds the value from 127 to 128, the program is automatically terminated.
Line 0 is intended for storing a note in a REM command or for automatic program start. Other functional commands on line 0 will not be executed.
A special case is writing the RUN command in the file FILE 0 (on the disk "h") at the first position of line 0. If the computer finds the RUN command at this position, it automatically starts this program after it is turned on. The computer does not need to have a keyboard connected and can be used, for example, to control a device after debugging the program.

Examples:
RUN | runs the written program

Command: END
Parameters: ---
Command function: Terminates program execution. If the END command is processed during program execution, the program is terminated and the computer returns to the waiting for user command mode. The END command is the only command whose pressing of the appropriate keys (Ctrl + N) is tested during the transition between lines during program execution. When this command is entered on the keyboard, the running program is terminated.

Examples:
END | ends the running program

Command: TIME
Parameters: VAR
Command function: It stores the value from the permanently running internal counter in the variable VAR. The counter is incremented by 1 every time a graphic line is drawn on the OLED monitor since the computer started. To synchronize with the oscillator frequency, the counter runs at a frequency of 31914 Hz. This means that its content is incremented by 31914 every second. Since the counter is 32-bit, it must overflow. After reaching the value 2,147,483,647, which will happen after about 18 hours of operation, the value jumps to the smallest negative number -2,147,483,648 and continues to increase by 1. Further overflows will then always occur after more than 37 hours. The function can be used not only to monitor the passage of a certain time interval during program execution, but also, for example, as a random number generator. When you press a key and save the current time, you just need to calculate the remainder after dividing the time by the number that determines the generator range.

Examples:
TIME T | stores the time in the variable T
TIME R; LET Q=R/6; LET R=R-Q*6 | in the variable R we get a random number from 0 to 5
| (e.g. for a dice roll)

Command: CURSOR
Parameters: EXPR
Command function: Sets the cursor (the place where writing will be done on the screen) to the specified position. The upper left corner of the screen is position 0 and the lower right corner is position 335. Positions increase on lines from left to right, just as when writing. If the position is outside the allowed range, the command does nothing and the cursor position remains at its original value.
If it is necessary to set the cursor position using a line number, then a calculation can be used where the line number is multiplied by 21 and the character positions within the line are added.

Examples:
CURSOR A | moves the cursor position to the values according to variable A
CURSOR 21*5+15 | moves the cursor to the sixth line from the top and the 16th position
| on that line
CURSOR 1024 | does nothing (value is out of range)

Command: PUTCH
Parameters: EXPR or x EXPR (where x see next) or p EXPR, EXPR
Command function: At the position specified by the cursor (the place where the screen will be written), a character is printed whose value is determined by the parameter expression. The lowest 8 bits are used for the printout. The character is printed in the range 0 to 255 (for higher numbers it will be the remainder after dividing by 256). The drawn character corresponds to the ASCII table. For example, the letter "A" has a value of 65.
Within the ASCII table range, only printable characters from 32 to 127 will be displayed. Above this range, semigraphic characters (mainly lines suitable for various frames) will be displayed in the range 128 to 159. After the semigraphic characters there is an area whose value is expanded as a BASIC keyword. For example, the value 160 will cause the word "PRINT" to be printed.
The remaining characters are non-printable and a dot will appear instead. The only exceptions are 3 values that correspond to the characters "\n", "\t" and "\f", as mentioned for the STRING parameter above:

9 | "\t" - move the cursor on the line to the next higher tab position 0,8,16
10 | "\n" - newline
12 | "\f" - clears the screen and places the cursor at position 0
The cursor moves in the same way as when printing text using the PRINT command. At the end of a line, a new line is entered and, if necessary, the entire screen is moved.
If one of the following characters is given before EXPR, the cursor moves in a special way:
. | the cursor will remain at the same position
> | the cursor moves one place to the right
< | the cursor moves one place to the left
v | the cursor moves down one place
^ | the cursor moves up one place
In these cases, the line or column is not moved to a new line or column. The cursor moves (and overflows) within the same line or column. In this way, it is possible to print only printable characters in the range 32 to 159.
The last option is to insert a character directly at the specified position on the display without affecting the cursor. After the "p" character, the value of the EXPR character is given, which is inserted at the position specified by the second parameter. The position on the display is in the range 0 to 335, the same as with the CURSOR command. In this way, it is again possible to print only printable characters in the range 32 to 159.

Examples:
PUTCH 49 | prints the number 1 at the cursor position
PUTCH p68, 21*12+10 | prints the letter D on line 12, position 10
PUTCH 12 | clears the screen and sets the cursor to the upper left corner
PUTCH .65 | prints the letter A and leaves the cursor at the same position
PUTCH v67 | prints the letter C and moves the cursor to the lower line with the same
position (in the case of the lowest line, it goes to the highest line)

Command: GETCH
Parameters: VAR or pEXPR, VAR
Command function: It stores the value of the character located at the cursor position on the screen in the variable VAR. Using the CURSOR command, it is possible to set the cursor to any position and using the GETCH command, it is possible to search for what was written at that position. The second option is to specify the position on the display directly after the character "p" in the range 0 to 335, from which the character is taken and stored in the variable VAR.

Examples:
CURSOR 260; GETCH C | the character from position 12,8 on the screen is inserted into
| variable C
GETCH p21*15+4, L | the character from position 4,15 on the screen is inserted into
| the variable L

Command: INKEY
Parameters: VAR
Command function: The command tests whether the user has pressed a key. If no key has been pressed, the value 0 is stored in the variable VAR. If a key has been pressed before the command is called, the corresponding character value according to the ASCII table is stored in the variable. For example, the value 66 means that the user has pressed "B".
Examples:
INKEY C | the character of the key already pressed is inserted into the variable C, or 0 if
| nothing was pressed

Command: FILE
Parameters: (EXPR)
Command function: Depending on the size of the connected memory, the user has at least 1 and at most 16 files available for writing a 128-line program. Switching between these programs is done using the FILE command, where the EXPR expression determines which file (program) will be active. This program is then worked with, written to or read from. EXPR can take on any value, but only the lowest 4 bits are valid (the remainder after dividing by 16). So, for example, the value 17 is equivalent to the value 1.
The size of the memory used determines how many files the user has available. If the smallest memory 24C32 is used, the FILE command has no meaning, because only the file with number 0 is available and it is still active. The larger memory 24LC64 already has two files – 0 and 1. The EXPR expression then allows switching between files, depending on whether the expression is odd or even. With the 24LC128 memory, you can use EXPR to sequentially select files 0,1,2,3,0,1,2,3,0,1... Only the 24LC512 memory uses the full range of this command and selects files numbered 0 to 15.
The FILE command will probably be used most often when changing programs by the user. It can also be used within a running program. This provides a powerful tool that allows you to link different files and jump between them on the fly.
For example, if a program is running in file number 0 and executes the command FILE 3 on line 25, the program continues with line 26 in file 3. This way, the program size limitation of 128 lines can be bypassed. When using the 24LC512 memory and using the option to write up to 3 commands per line, a program of up to 6000 commands can theoretically be placed in memory. In combination with the DISK command (see below), this number increases to 12000.
If the parameter is not specified (or the expression is entered incorrectly), this command prints the current file number on a new line.

Examples:
FILE 10 | switches to file number 10 (for 24LC512 only), to file 0 (for 24C32, 24LC64)
| and to file 2 (for 24LC128 and 24LC256)
FILE | prints the current file number

Command: DISK
Parameters: (h|f)
Command function: The command switches between the memories on the computer board. One of the memories is SMD, firmly soldered to the board and cannot be changed. This memory represents the computer's "hard disk" and is marked “h”. The other memory in DIL can be inserted and removed from the socket and is marked “f”. The integrated circuit can be marked as a "floppy disk"
- a removable medium. After the computer starts, DISK h is active and the file FILE 0 in it.
The parameter determines which disk will be used next – it will be active.
If DISK f is not inserted at startup, the computer will report this in the initial message after switching on. Then, of course, it is not possible to switch to this disk using the DISK f command. The command does nothing and does not report an error. DISK h will remain active.
If the parameter is not specified or is chosen incorrectly, the command will print the active disk designation on a new line.

Examples:
DISK f | switches to DISK f if inserted; otherwise does nothing
DISK | lists active DISK

Command: DELAY
Parameters: EXPR
Command function: Pauses the program for the time specified by the EXPR parameter. The value of the expression specifies the time in milliseconds. Allowed values are 1 to 1,000,000. Outside this range, the command does nothing.

Examples:
DELAY 5*100 the program waits 500 milliseconds and then continues
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

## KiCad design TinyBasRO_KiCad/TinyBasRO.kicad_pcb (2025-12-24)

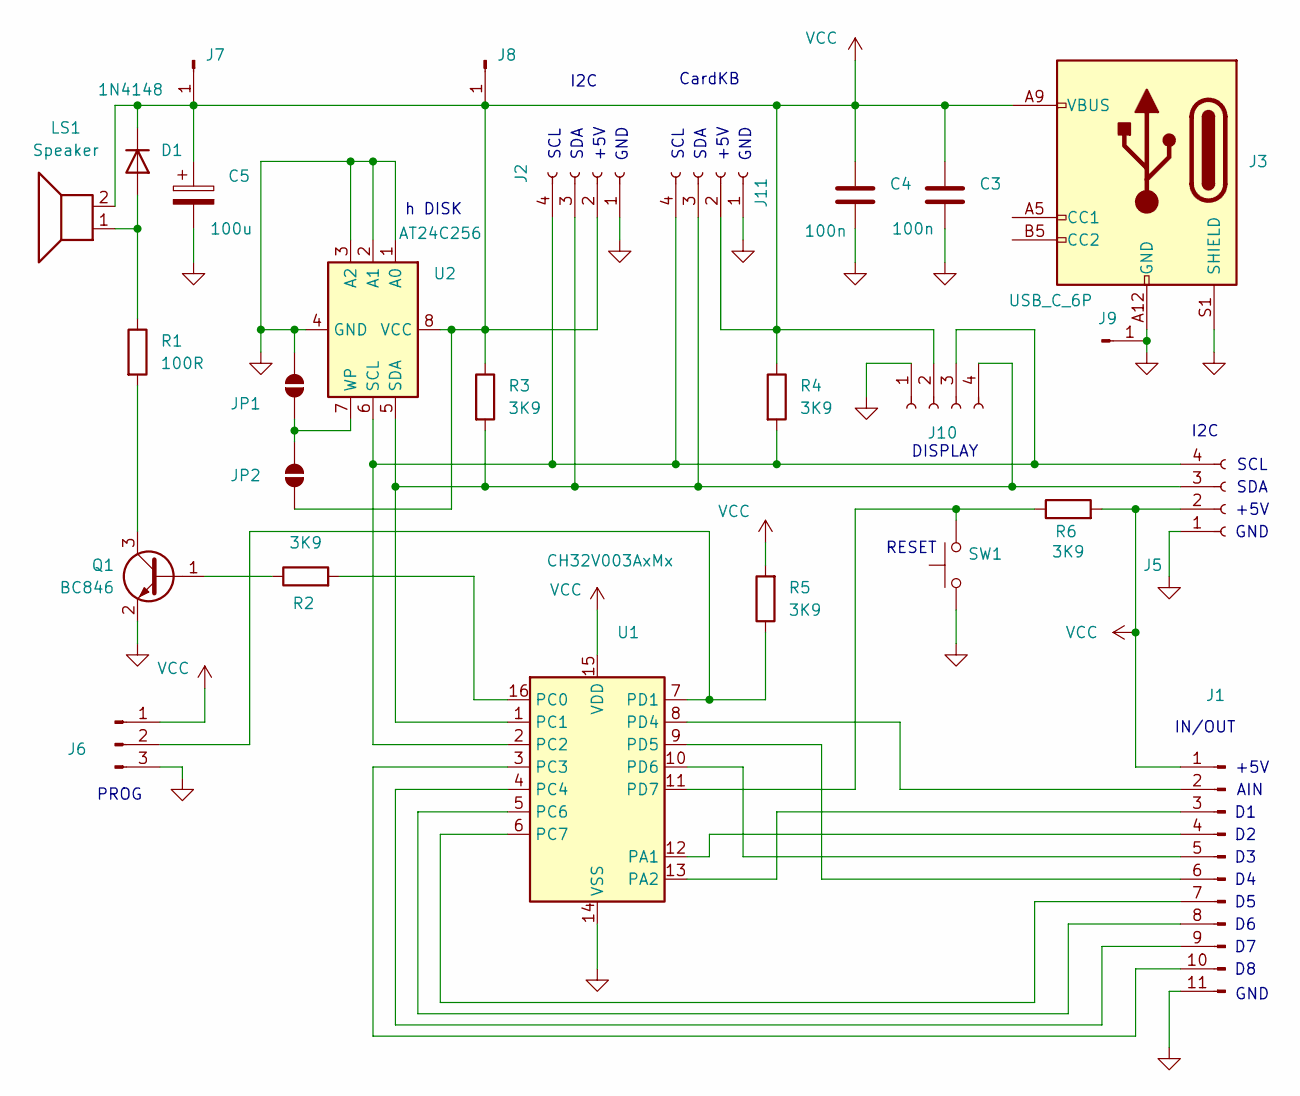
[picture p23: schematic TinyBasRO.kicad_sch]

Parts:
C3, C4: 100n; C_0805_2012Metric_Pad1.18x1.45mm_HandSolder
C5: 100u; CP_Radial_D7.5mm_P2.50mm
D1: 1N4148; D_MiniMELF_Handsoldering
J1: Conn_01x11_Pin; PinHeader_1x11_P2.54mm_Vertical
J2, J5: Conn_01x04_Socket; PinSocket_1x04_P2.54mm_Horizontal
J3: USB_C_6P; USB_C_Receptacle_GCT_USB4125-xx-x_6P_TopMnt_Horizontal
J6: Conn_01x03_Pin; PinHeader_1x03_P2.54mm_Vertical
J7, J8, J9: Conn_01x01_Pin; PinHeader_1x01_P2.54mm_Vertical
J10: Conn_01x04_Socket; PinSocket_1x04_P2.54mm_Vertical
J11: Conn_01x04_Socket; PinSocket_1x04_P2.00mm_Vertical
JP1, JP2: SolderJumper_2_Open; SolderJumper-2_P1.3mm_Open_RoundedPad1.0x1.5mm
LS1: Speaker; Indicator_PUI_AI-1440-TWT-24V-2-R
Q1: BC846; SOT-23
R1: 100R; R_0805_2012Metric_Pad1.20x1.40mm_HandSolder
R2, R3, R4, R5, R6: 3K9; R_0805_2012Metric_Pad1.20x1.40mm_HandSolder
SW1: SW_Push; SW_Tactile_SKHH_Angled
U1: CH32V003AxMx; SOP-16_3.9x9.9mm_P1.27mm
U2: AT24C256; SOIC-8_3.9x4.9mm_P1.27mm

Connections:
GND: C3.2, C4.2, C5.2, J1.11, J2.1, J3.A12 (GND), J3.B12 (GND), J3.S1 (SHIELD), J5.1, J6.3, J9.1, J10.1, J11.1, JP1.2 (B), Q1.2 (E), SW1.1, U1.14 (VSS), U2.1 (A0), U2.2 (A1), U2.3 (A2), U2.4 (GND)
unnamed: D1.2 (A), LS1.1, R1.1
unnamed: J1.2, U1.8 (PD4)
unnamed: J1.3, U1.13 (PA2)
unnamed: J1.4, U1.12 (PA1)
unnamed: J1.5, U1.10 (PD6)
unnamed: J1.6, U1.9 (PD5)
unnamed: J1.7, U1.6 (PC7)
unnamed: J1.8, U1.5 (PC6)
unnamed: J1.9, U1.4 (PC4)
unnamed: J1.10, U1.3 (PC3)
unnamed: J6.2, R5.1, U1.7 (PD1)
unnamed: J2.4, J5.4, J10.3, J11.4, R4.2, U1.2 (PC2), U2.6 (SCL)
unnamed: J2.3, J5.3, J10.4, J11.3, R3.2, U1.1 (PC1), U2.5 (SDA)
unnamed: JP1.1 (A), JP2.2 (B), U2.7 (WP)
unnamed: Q1.1 (B), R2.1
unnamed: Q1.3 (C), R1.2
unnamed: R2.2, U1.16 (PC0)
unnamed: R6.1, SW1.2, U1.11 (PD7)
VCC: C3.1, C4.1, C5.1, D1.1 (K), J1.1, J2.2, J3.A9 (VBUS), J3.B9 (VBUS), J5.2, J6.1, J7.1, J8.1, J10.2, J11.2, JP2.1 (A), LS1.2, R3.1, R4.1, R5.2, R6.2, U1.15 (VDD), U2.8 (VCC)

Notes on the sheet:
GND
+5V
AIN
SDA
DISPLAY
IN/OUT
I2C
SCL
RESET
h DISK
CardKB
PROG

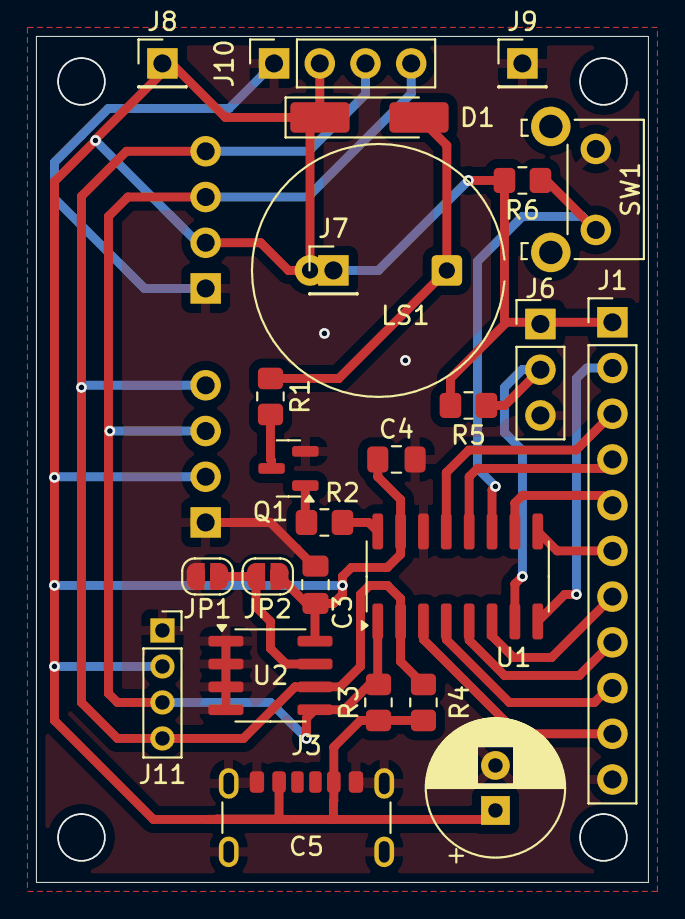
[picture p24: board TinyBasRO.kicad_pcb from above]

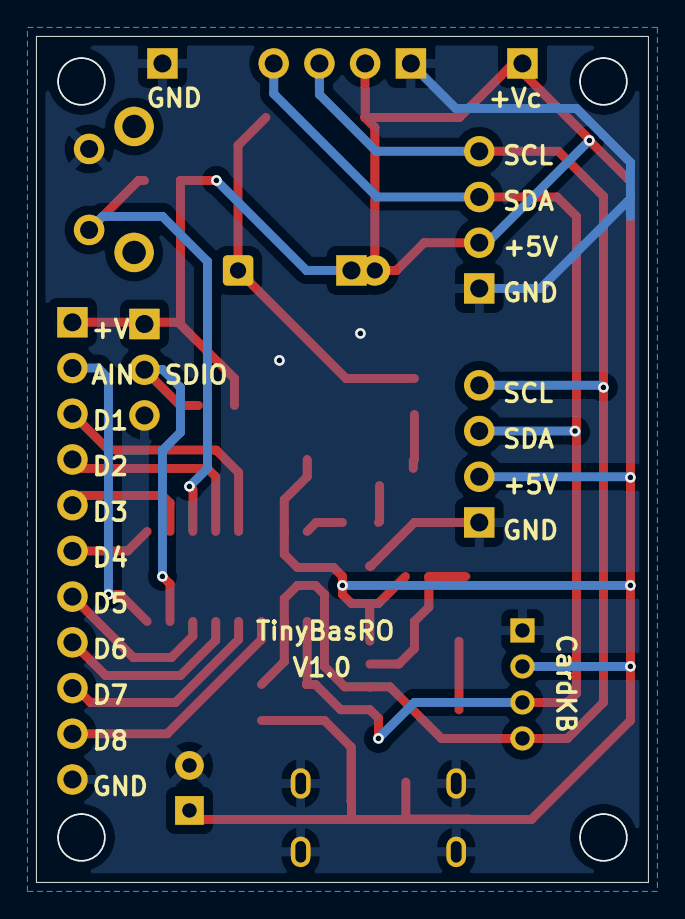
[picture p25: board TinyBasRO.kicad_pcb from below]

Board: 2 copper layers, 34.0 x 47.0 mm, 27 parts (2 on the bottom side), 20 nets.

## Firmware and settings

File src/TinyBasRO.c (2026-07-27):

/********************************** (C) COPYRIGHT *******************************
 * File Purpose       : TinyBasicRO main file
 * Author             : Stan6314
 * Versions           : V1.0 - initial
 *                      V1.1 - fix I2CR and I2CW command
 * Date               : 2026/07/26 
 * Description        : TinyBasic for CH32V003
 *      + character constants are in charstable.h
 * The program contains 3 parts:
 *      -> initialization, interrupt and auxiliary functions
 *      -> Tiny BASIC commands
 *      -> main loop
*********************************************************************************
*******************************************************************************/
#include "ch32fun.h"
#include "charstable.h"
// Uncomment for OLED display upside down
//#define OLEDUPSIDEDOWN

// I2C Timeout maximum count
#define TIMEOUT_MAX 500000 

// Global variables for display
volatile uint8_t VideoRAM[336];    // VideoRAM for 16 * 21 chars

// Global variables for Tiny BASIC
volatile uint32_t comENDTimer = 0;   // Internal timer for END command
volatile uint32_t basTimer = 0;      // Internal timer for Tiny BASIC TIME command incremented with "vertical sync"
static uint16_t dispPointer = 0;     // Pointer to current display position
volatile uint8_t RunMode = 0;     // If it is 1, then basic program is in run
uint8_t currentLine=0;    // Actual line to proccess
uint8_t noOfMemory = 0;   // Number of section in program memory or "file" (4 KB sections)
uint8_t compFlags = 0;    // Bit7 = Is DISK1, Bit6 = Is PCF857x, 
// Bit5 = Is OLED, Bit4 = Is CardKB, Bits3-0 = Low Addres of EEPROM (Disk adr)
uint8_t linePointer=0;    // Pointer to line memory buffer
uint8_t line_buffer[33];  // buffer for data read/write
uint8_t stack_buffer[8];  // buffer for GOSUB stack
uint8_t stackPointer=0;    // Pointer to GOSUB buffer
int charVariable[26]; // Variables A..Z
int arrayVariable[100]; // Variables in array @0..99
int evalNumber;     // Value of number for evaluation in BASIC line

// Define devices on I2C bus in compFlags
#define ISDISKf (compFlags & 0x80)
#define ISEXPANDER (compFlags & 0x40)
#define ISOLED (compFlags & 0x20)
#define ISKEYB (compFlags & 0x10)

// ****************************************************************
//         Systick interrupt handler
// ****************************************************************
void SysTick_Handler(void) __attribute__((interrupt));
void SysTick_Handler(void)
{
	// Increment the Compare Register for the next trigger
	SysTick->CMP += 1504;
	// Clear the trigger state for the next IRQ
	SysTick->SR = 0x00000000;
	// Increment BASIC counter and END command counter
	basTimer++; comENDTimer++;
}

// ****************************************************************
//         Delay functions
// ****************************************************************
// Own delay functions with SysTick counter
void My_Delay_Us(uint32_t delayTime)
{
    uint32_t recentTime = SysTick->CNT;
    while((SysTick->CNT - recentTime) < (48 * delayTime)) {;}
}
void My_Delay_Ms(uint32_t delayTime)
{
    for(uint32_t i=0; i<delayTime; i++) My_Delay_Us(1000);
}

// ****************************************************************
//         I2C module functions
// ****************************************************************
// Initialization of I2C module
void IIC_Init()
{
	// Enable GPIOC and I2C
    RCC->APB1PCENR |= RCC_APB1Periph_I2C1; 
	RCC->APB2PCENR |= RCC_APB2Periph_GPIOC | RCC_APB2Periph_AFIO;
    // Reset I2C1 to init all regs
	// PC1 is SDA, 30MHz Output, alt func, open-drain
	GPIOC->CFGLR &= ~(0xf<<(4*1));
	GPIOC->CFGLR |= (GPIO_Speed_10MHz | GPIO_CNF_OUT_OD_AF)<<(4*1);
	// PC2 is SCL, 30MHz Output, alt func, open-drain
	GPIOC->CFGLR &= ~(0xf<<(4*2));
	GPIOC->CFGLR |= (GPIO_Speed_10MHz | GPIO_CNF_OUT_OD_AF)<<(4*2);
    // set freq
	I2C1->CTLR2 = (FUNCONF_SYSTEM_CORE_CLOCK/2000000)&I2C_CTLR2_FREQ;;
	// Set clock config
    I2C1->CKCFGR = 0xC005;      // Speed up I2C to slightly bellow 400000 kHz
	// Enable I2C
	I2C1->CTLR1 |= I2C_CTLR1_PE;
	// set ACK mode
	I2C1->CTLR1 |= I2C_CTLR1_ACK;
}

// Wait for executing or timeout on I2C
int I2CTimeout(uint32_t EventCode)
{
    uint32_t status, timeout;
	timeout = TIMEOUT_MAX;
    do {
        status = I2C1->STAR1 | (I2C1->STAR2<<16);
        status &= EventCode;       
    }
	while((!(status == EventCode)) && (timeout--));
	if(timeout==-1) { I2C1->CTLR1 |= I2C_CTLR1_STOP; return 1; }
    return 0;
}

// Check I2C address for connected device
int CheckI2CDevice(u8 i2caddr)
{
    uint32_t timeout = TIMEOUT_MAX;
	// Wait for not busy
	while((I2C1->STAR2 & I2C_STAR2_BUSY) && (timeout--));
	if(timeout==-1) return 0;
	// Set START condition
	I2C1->CTLR1 |= I2C_CTLR1_START;
	// Wait for master mode select
    if(I2CTimeout(I2C_EVENT_MASTER_MODE_SELECT)) return 0;
	// Send 7-bit address + write flag
	I2C1->DATAR = i2caddr;
	// Wait for transmit condition
    if(I2CTimeout(I2C_EVENT_MASTER_TRANSMITTER_MODE_SELECTED)) {I2C1->CTLR1 |= I2C_CTLR1_STOP; return 0;};
	// set STOP condition
	I2C1->CTLR1 |= I2C_CTLR1_STOP;
    return 1;   // Yes, device is connected
}

// Check I2C for connected CardKB
int CheckI2CKeyboard()
{
    uint32_t timeout = TIMEOUT_MAX;
	// Wait for not busy
    while((I2C1->STAR2 & I2C_STAR2_BUSY) && (timeout--));
    if(timeout==-1) return 0;
    // Set START condition
    I2C1->CTLR1 |= I2C_CTLR1_START;
    // Wait for master mode select
    if(I2CTimeout(I2C_EVENT_MASTER_MODE_SELECT)) return 0;
    I2C1->DATAR = 0xBF;    // Send keyboard address + read
    // Wait for receive condition
    if(I2CTimeout(I2C_EVENT_MASTER_RECEIVER_MODE_SELECTED)) {I2C1->CTLR1 |= I2C_CTLR1_STOP; return 0;};
    if(I2CTimeout(I2C_EVENT_MASTER_BYTE_RECEIVED)) return 0;   // Wait for ready read data
    // set STOP condition
    I2C1->CTLR1 |= I2C_CTLR1_STOP;
    return 1;   // Keyboard is connected
}

// ****************************************************************
//         OLED functions
// ****************************************************************
// Send 1 byte to OLED
void OLEDi2cTransfer(uint8_t data, uint8_t control)
{
    if(!ISOLED) return;
	// Wait for I2C not busy
	uint32_t timeout = TIMEOUT_MAX;
	while((I2C1->STAR2 & I2C_STAR2_BUSY) && (timeout--));
	if(timeout==-1) {I2C1->CTLR1 |= I2C_CTLR1_STOP; return;}
	// Set START condition
	I2C1->CTLR1 |= I2C_CTLR1_START;
	// Wait for master mode select
    if(I2CTimeout(I2C_EVENT_MASTER_MODE_SELECT)) return;
	// send 7-bit address + write flag
	I2C1->DATAR = 0x78;
	// Wait for transmit condition
    if(I2CTimeout(I2C_EVENT_MASTER_TRANSMITTER_MODE_SELECTED)) return;
	// Send LSB
	I2C1->DATAR = control;
	// Wait for transmit condition
    if(I2CTimeout(I2C_EVENT_MASTER_BYTE_TRANSMITTED)) return;
	// Send data
	I2C1->DATAR = data;
	// Wait for transmit condition
    if(I2CTimeout(I2C_EVENT_MASTER_BYTE_TRANSMITTED)) return;
	// set STOP condition
	I2C1->CTLR1 |= I2C_CTLR1_STOP;
    return;   // Yes, device is connected
}

// Send more (the same) data bytes to OLED
void OLEDi2cBlockTransfer(uint8_t data, uint16_t len)
{
    if(!ISOLED) return;
	// Wait for I2C not busy
	uint32_t timeout = TIMEOUT_MAX;
	while((I2C1->STAR2 & I2C_STAR2_BUSY) && (timeout--));
	if(timeout==-1) {I2C1->CTLR1 |= I2C_CTLR1_STOP; return;}
	// Set START condition
	I2C1->CTLR1 |= I2C_CTLR1_START;
	// Wait for master mode select
    if(I2CTimeout(I2C_EVENT_MASTER_MODE_SELECT)) return;
	// send 7-bit address + write flag
	I2C1->DATAR = 0x78;
	// Wait for transmit condition
    if(I2CTimeout(I2C_EVENT_MASTER_TRANSMITTER_MODE_SELECTED)) return;
	// Send LSB
	I2C1->DATAR = 0x40;
	// Wait for transmit condition
    if(I2CTimeout(I2C_EVENT_MASTER_BYTE_TRANSMITTED)) return;
    for (uint16_t i = 0; i < len; ++i)
    {
  	    // Send data
  	    I2C1->DATAR = data;
     	// Wait for transmit condition
        if(I2CTimeout(I2C_EVENT_MASTER_BYTE_TRANSMITTED)) return;
    }
	// set STOP condition
	I2C1->CTLR1 |= I2C_CTLR1_STOP;
}

// Send to the display a command byte
void command(uint8_t sbyte)
{
    OLEDi2cTransfer(sbyte, 0x00);
}

//Send to the display a data byte
void OLEDdata(uint8_t sbyte)
{
    OLEDi2cTransfer(sbyte, 0x40);
}

// Initialisation of OLED
void OLEDinit()
{
    // Commands from unknown web page (I dont remember what)
    command(0xAE); command(0x00); command(0x10);
    command(0x20); command(0x81); command(0x2F);
#ifdef OLEDUPSIDEDOWN
    command(0xA1);
#else
    command(0xA0);
#endif  // For upside down display 0xA0 -> 0xA1
    command(0xA8); command(0x7F); command(0xA4);
    command(0xA6); command(0xD3); command(0x00); command(0xB0);
#ifdef OLEDUPSIDEDOWN
    command(0xC8);
#else
    command(0xC0);
#endif  // For upside down display 0xC0 -> 0xC8
    command(0xDA); command(0x12); command(0xD5);
    command(0x50); command(0xD9); command(0xF1);
    command(0x8D); command(0x14); command(0xDB);
    command(0x40); command(0xDC); command(0x00);
    command(0xAD); command(0x8A); command(0xAF);
    My_Delay_Ms(100);
}

//Set page address.
void OLEDsetPageAddress(uint8_t add) { command(0xB0 | add); }

//Set column address.
void OLEDsetColumnAddress(uint8_t add)
{
   command(0x10 | (add >> 4));  // Send lower address byte
   command((0x0F & add));       // Send upper address byte
}

// Fill screen with pattern
void OLEDclear(uint8_t c)
{
    for (uint8_t row = 0; row < 16; row++)
    {
        OLEDsetPageAddress(row);
        OLEDsetColumnAddress(0);
        OLEDi2cBlockTransfer(c, 0x80);
    }
}

// Draw character on the actual position on OLED
void PlotChar(uint8_t dispChar)
{
    if(!ISOLED) return;
    OLEDsetPageAddress(dispPointer/21);
    OLEDsetColumnAddress((dispPointer%21)*6);
    int toTabPoint = ((dispChar-0x20)&0x7F)*6;
	// Wait for I2C not busy
	uint32_t timeout = TIMEOUT_MAX;
	while((I2C1->STAR2 & I2C_STAR2_BUSY) && (timeout--));
	if(timeout==-1) {I2C1->CTLR1 |= I2C_CTLR1_STOP; return;}
	// Set START condition
	I2C1->CTLR1 |= I2C_CTLR1_START;
	// Wait for master mode select
    if(I2CTimeout(I2C_EVENT_MASTER_MODE_SELECT)) return;
	// send 7-bit address + write flag
	I2C1->DATAR = 0x78;
	// Wait for transmit condition
    if(I2CTimeout(I2C_EVENT_MASTER_TRANSMITTER_MODE_SELECTED)) return;
	// Send LSB
	I2C1->DATAR = 0x40;
	// Wait for transmit condition
    if(I2CTimeout(I2C_EVENT_MASTER_BYTE_TRANSMITTED)) return;
    for (uint16_t i = 0; i < 6; ++i)
    {
  	    // Send data
  	    I2C1->DATAR = CharTable[toTabPoint++];
     	// Wait for transmit condition
        if(I2CTimeout(I2C_EVENT_MASTER_BYTE_TRANSMITTED)) return;
    }
	// set STOP condition
	I2C1->CTLR1 |= I2C_CTLR1_STOP;
}

// Move display up and make a new line
void MakeNewLine()
{
    int i;
    for(i=0;i<315;i++) VideoRAM[i]=VideoRAM[i+21];  // Roll it up
    for(i=315;i<336;i++) VideoRAM[i]=0; // Clear last line
    dispPointer = 315;  // Cursor to begin on the last line
    if(!ISOLED) return;
    for(i=0;i<16;i++) {
        OLEDsetPageAddress(i);
        OLEDsetColumnAddress(0);
    	// Wait for I2C not busy
    	uint32_t timeout = TIMEOUT_MAX;
    	while((I2C1->STAR2 & I2C_STAR2_BUSY) && (timeout--));
    	if(timeout==-1) {I2C1->CTLR1 |= I2C_CTLR1_STOP; return;}
    	// Set START condition
    	I2C1->CTLR1 |= I2C_CTLR1_START;
    	// Wait for master mode select
        if(I2CTimeout(I2C_EVENT_MASTER_MODE_SELECT)) return;
    	// send 7-bit address + write flag
    	I2C1->DATAR = 0x78;
    	// Wait for transmit condition
        if(I2CTimeout(I2C_EVENT_MASTER_TRANSMITTER_MODE_SELECTED)) return;
    	// Send LSB
    	I2C1->DATAR = 0x40;
    	// Wait for transmit condition
        if(I2CTimeout(I2C_EVENT_MASTER_BYTE_TRANSMITTED)) return;
        for(int j=0;j<21;j++) {
            int toTabPoint = 6 * VideoRAM[i*21+j];
            for (int k = 0; k < 6; ++k)
             {
            	// Send data
            	I2C1->DATAR = CharTable[toTabPoint++];
               	// Wait for transmit condition
                if(I2CTimeout(I2C_EVENT_MASTER_BYTE_TRANSMITTED)) return;
             }
        }
	    // set STOP condition
	    I2C1->CTLR1 |= I2C_CTLR1_STOP;
    }
}

// ****************************************************************
//         Keyboard functions
// ****************************************************************
volatile uint8_t KbdDataBuffer = 0;       // Keyboard buffer

// Read keyboard status directly on I2C bus
uint8_t readActKbd()
{
    uint8_t actKey = 0;
    if(ISKEYB) {
        uint32_t timeout = TIMEOUT_MAX;
        while((I2C1->STAR2 & I2C_STAR2_BUSY) && (timeout--));
        if(timeout==-1) {I2C1->CTLR1 |= I2C_CTLR1_STOP; return actKey;}
        // Set START condition
        I2C1->CTLR1 |= I2C_CTLR1_START;
        // Wait for master mode select
        if(I2CTimeout(I2C_EVENT_MASTER_MODE_SELECT)) return actKey;
        I2C1->DATAR = 0xBF;    // Send keyboard address + read
        // Wait for receive condition
        if(I2CTimeout(I2C_EVENT_MASTER_RECEIVER_MODE_SELECTED)) return actKey;
        if(I2CTimeout(I2C_EVENT_MASTER_BYTE_RECEIVED)) return actKey;   // Wait for ready read data
        actKey = I2C1->DATAR;
        // set STOP condition
        I2C1->CTLR1 |= I2C_CTLR1_STOP;
    }
    return actKey;
}
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
int main()
{
	SystemInit();

	funGpioInitAll();  // Enable GPIOs
    // Prepare speaker output
    funPinMode( PC0, GPIO_CFGLR_OUT_10Mhz_PP ); 
    funDigitalWrite( PC0, FUN_LOW );
    IIC_Init();     // Initialize I2C module
    // Initialize SysTick to trigger an IRQ with auto-reload, using HCLK/1 as clock source
	// Reset any pre-existing configuration
	SysTick->CTLR = 0x0000;
	// Set the compare register to trigger once per millisecond
	SysTick->CMP = 1503;
	// Reset the Count Register, and the global millis counter to 0
	SysTick->CNT = 0x00000000;
	// NOTE: By not setting SYSTICK_CTLR_STRE, we maintain compatibility with
	// busywait delay funtions used by ch32v003_fun.
	SysTick->CTLR |= SYSTICK_CTLR_STE   |  // Enable Counter
	                 SYSTICK_CTLR_STIE  |  // Enable Interrupts
	                 SYSTICK_CTLR_STCLK ;  // Set Clock Source to HCLK/1
	// Enable the SysTick IRQ
	NVIC_EnableIRQ(SysTicK_IRQn);

	My_Delay_Ms(100);   // For display stabilization after RESET
    // Check devices on I2C bus
    int FlagNoPassedDelay = 1;
    if(CheckI2CDevice(0xA2)) compFlags |= 0x80;      // Disk f - second EEPROM
    if(CheckI2CDevice(0x40)) compFlags |= 0x40;      // Expander PCF8575
    if(CheckI2CDevice(0x78)) compFlags |= 0x20;      // OLED display
    else {      // Short beep if no OLED
        for(int32_t i=0; i<200; i++ ) {
            GPIOC->BSHR = 0x00000001; My_Delay_Us(500);
            GPIOC->BSHR = 0x00010000; My_Delay_Us(500);
        }
        FlagNoPassedDelay = 0;
    }
    // Display init
    if(ISOLED) OLEDinit();
    WriteChar(0x0C);    // Clear display

    adc_init(); // Start A/D converter
    line_buffer[32] = (unsigned char)0xFF;  // Stop symbol at end of buffer

    WriteTextln("TinyBasic 1.1");  // Introductory message
    if(!ISDISKf) WriteTextln("No DISK f");
    if(!ISEXPANDER) WriteTextln("No PCF8575");
  
    // Test for autorun (Is statement RUN - 0xAA in the first byte of file 0?)  
    I2C_read_line(0);   // Read the first line of file
    if(line_buffer[0] == (unsigned char)0xAA) {   // Test first byte for RUN statement
        linePointer=1;    // First byte is bytecode of RUN, so move to next byte...
        KbdDataBuffer = 0x0A;   // ... and pretend that user pressed Enter after RUN
    }

    // Unfortunately - CardKB starts after about 1 sec blinking with LED, so we must delay for keyboard awakening
    if(FlagNoPassedDelay) My_Delay_Ms(900); else My_Delay_Ms(700);   // No delay if missing OLED, so wait more for CardKB
    if(CheckI2CKeyboard()) compFlags |= 0x10;      // CardKB is connected
    if(!ISKEYB) WriteTextln("No CardKB");

    char recChar;   // Processed character from keyboard
    // Program main loop starts here
    while(1)
    {
        // Get char to buffer (only to max size of buffer or end of line (Enter))
        recChar = GetKeyChar();
        // and return it to display
        if(recChar == 0x09) {  // Tab needs special cure 
          if(linePointer < 27) WriteText("    "); // Tab inserts only 4 spaces
        } else {  // Other characters
          if(linePointer < 32) WriteChar(recChar);
        }
        // Char must be saved to line_buffer
        // Is it char to start process line (Enter)?
        if (recChar == '\n') {
          // look for the newline. That's the end of your sentence:
          line_buffer[linePointer] = (unsigned char)0xFF;    // End of line is signalled with 0xFF
          currentLine = 0; linePointer=0;  // Prepare pointer to beginning,...
          // ... and process line
          int* numLine;
          RemoveWhtSP();
          if((numLine = isNumberNext()) != NULL) {    // If line starts with number ...
            RemoveWhtSP();  // ... discard number and white spaces ...
            if((*numLine >= 0) && (*numLine < 128)) I2C_write_line((unsigned char) *numLine); // ... and save line
            else WriteErrMsg("Error line number!");
          }
          else {  // No number at begin of line
            comENDTimer = 0;    // Prepare counter for test END command
            do{ // Is it time for test END command to break program?
                if(comENDTimer > 31914) {    // time of 1 sec
                    comENDTimer = 0;
                    recChar = readActKbd();
                    // Enter is 0x0D - change it to 0x0A
                    if(recChar == 0x0D) recChar = 0x0A;
                    if(recChar < 0xBF) KbdDataBuffer = recChar;
                    if(recChar == 0xAB) RunMode = 0;
                }
                // Execute statements while RunMode
                uint8_t auxLine = currentLine;    // Save line number
                // -----------------------------------------------------------
                Statement();
                // Test for the second Statement on the line
                RemoveWhtSP();  // IF, GOTO or GOSUB will discard second Statement
                if((auxLine == currentLine) && (line_buffer[linePointer] == ';')) {
                  RemoveNextWhtSP();
                  Statement();
                }
                // Test for the third Statement on the line
                RemoveWhtSP();  // IF, GOTO or GOSUB will discard third Statement
                if((auxLine == currentLine) && (line_buffer[linePointer] == ';')) {
                  RemoveNextWhtSP();
                  Statement();
                }
                if(RunMode && (auxLine == currentLine)) currentLine++; // No jump, so go to next line
                // Prepare next program line
                if(currentLine > 127) { RunMode = 0; currentLine = 0;} // Number of line step over maximum line
                else { I2C_read_line(currentLine); linePointer = 0; }   // Line number is OK, so prepare it
            } while(RunMode);
            WriteTextln("\nOK");
          }
          // ... line was proccessed so...
          linePointer=0;  // ... move pointer to beginning again.
        }
        else {       // No end of line - just process character
          if(recChar==0x08) {    // Is backspace, so return char(s) in the line
            if (linePointer > 0) {  // Edit can be only in current line
              linePointer--;    // Return pointer 1 char
              if(line_buffer[linePointer] < 0xA0) { dispPointer--;VideoRAM[dispPointer] = 0x00;} // Discard normal character
              else {  // It is keyword - that means rather difficult
                if(line_buffer[linePointer] < 0xBC) { // Just within keyword range
                  int pKeyWord = ((line_buffer[linePointer] - (uint8_t)0xA0)) << 3;  // Get lenght of keyword
                  for(int j=0; j<KeyWordTab[pKeyWord];j++){
                    VideoRAM[dispPointer] = 0x00; PlotChar(' ');    // Discard 1 letter of keyword
                    // Test pointer and stop roll display off
                    if(dispPointer>1) dispPointer--;
                  }
                  VideoRAM[dispPointer] = 0x00;     // And the discard last letter of keyword
                }
              } 
            }
          } else {
            if (linePointer < 32) {
              // Put normal char to line buffer
              if(recChar == 0x09) {    // Special char is Tab
                if(linePointer < 27) {  // Expand Tab to 4 spaces (for future backspace)
                  line_buffer[linePointer++] = ' '; line_buffer[linePointer++] = ' ';
                  line_buffer[linePointer++] = ' '; line_buffer[linePointer++] = ' '; 
                }
              } else {
              // Save real "normal" char finally
                line_buffer[linePointer] = recChar;
                linePointer++;  // max 32 chars in buffer
              }
            }
          }
        }
    }
}

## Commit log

2025-12-24 Initial release
    [TinyBasRO.kicad_pcb, TinyBasRO.kicad_sch]
2026-07-27 Fix for I2CW and I2CR commands
    [TinyBasRO.c]
